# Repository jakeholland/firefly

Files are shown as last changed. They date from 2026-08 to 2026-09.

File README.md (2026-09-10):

# Firefly

**An open-source festival compass that points at your friends.**

Firefly is a palm-sized round-screen puck for music festivals: a compass arrow that points at your crew over LoRa mesh radio, off-grid messaging (canned replies, flares, T9), the full lineup with set alarms, and a vector map of the grounds — so your phone stays at camp.

<p align="center">
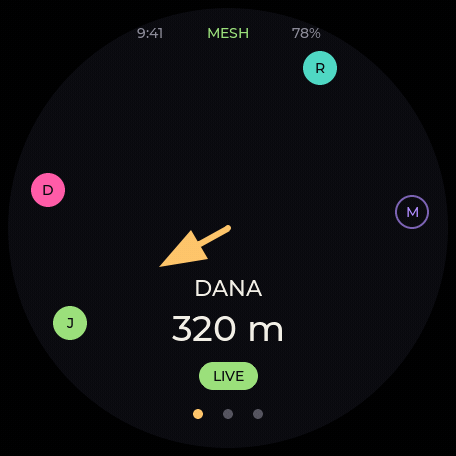
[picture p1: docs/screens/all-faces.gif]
Firefly cycling through the four built faces: the radar arrow locking onto a crew member, the Lost Lands lineup with set times still unpublished, the live schedule, the signals feed, the T9 composer, and a flare takeover.
  
</p>

<p align="center"><em>Not a mockup — that's the firmware rendering, frame by frame.<br>
All six v1 faces, running. The arrow finds your friend, the lineup admits which set times<br>aren't published yet, you can message without a network, and a flare takes over when someone needs finding.</em></p>

## Status

**The app runs.** As of 2026-09-02 all six v1 faces are built and merged: Radar, Lineup, Inbox (with its composer), Flare, Map, and Settings. The shell (S16) routes between them, and on top of it sits a device lifecycle (S25/S26): a launcher-is-home nav model, where a compass-ring launcher — Radar as the hub, the other faces as satellites — is what the puck boots into and rests on, with a physical button as the one "home" gesture from anywhere. Display, touch, the battery power latch, idle/sleep, and notification banners are hardware-verified on a real ESP32-S3 board, not just the desktop simulator. What's left before Lost Lands: the UART link to the comms brain (blocked on Seeed board availability), onboard sensors, and the enclosure. First field test: **Lost Lands, Sep 18–20 2026**.

<p align="center">
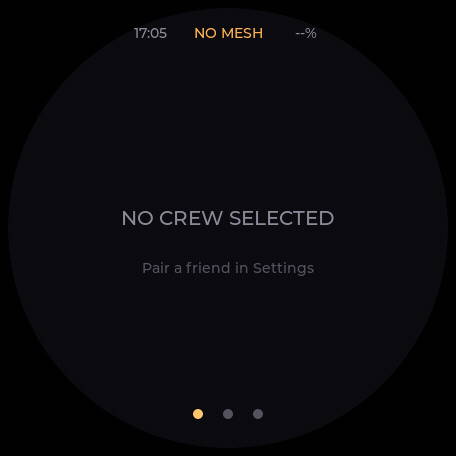
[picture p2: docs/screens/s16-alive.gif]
A live driven session: swiping from the radar's honest empty state through the Lost Lands lineup to Signals, typing omw on the T9 keypad, a flare takeover interrupting mid-draft with a live countdown, and the composer returning with the draft intact after DISMISS.
  
</p>

<p align="center"><em>Not fixtures — a live session, driven by real taps and swipes through the control socket.<br>Typed mid-draft, a flare takes the screen; dismiss it, and the draft is still there.</em></p>

This table is meant to be accurate rather than flattering — if something renders but can't run on hardware yet, it says so.

| Piece | State |
|---|---|
| Core logic — geo/bearing math, crew model & freshness, schedule engine, settings, T9, flare state machine | ✅ on `main` |
| Meshtastic client library (`meshclient`) | ✅ on `main` |
| festpack parser + the [Lost Lands 2026 pack](https://github.com/jakeholland/fest-almanac) | ✅ on `main` |
| **Radar face** — live / stale / lost / no-fix / no-selection | ✅ on `main` |
| Radar **close-range** mode — signal-strength rings under ~30 m | ✅ triggerable live with direct-path packets ([#35](https://github.com/jakeholland/firefly/issues/35)) |
| **Lineup face** (was Now) — live set times, starred-set countdown, and honest "times not published yet" states | ✅ on `main` |
| **Flare** — takeover screen, sender state, navigation lock | ✅ on `main` |
| Dev harness — control socket, dockerised Meshtastic node, end-to-end tests | ✅ on `main` |
| **Inbox face** (was Signals) — targeted crew messages and threads, rally points, OMW/5 MIN quick replies, and a T9 composer with ABC/123/SYM pages | ✅ on `main` (S22, S24) |
| **Map face** — vector grounds, crew dots, YOU arrow, priority-decluttered labels | ✅ on `main` (S09) |
| **Settings face** — units, clock format, quiet hours, share mode, screen flip, name | ✅ on `main` (S11, S21 — scrolling list + on-device Calibrate Touch; renaming is display-only, see below) |
| **App shell** — event loop, face routing, input dispatch, wall clock, link state, settings persistence | ✅ complete (S16, 9 slices) |
| **Launcher / home** — launcher-is-home nav model, compass-ring launcher (Radar hub + satellite faces), BOOT-button home, boot splash | ✅ on `main` (S26) |
| ESP32-S3 device target — display/touch, battery power latch, idle/sleep, notifications | ◐ hardware-verified on board (S15/S15b/c/d, S25, S26); UART link to the comms brain still blocked (Seeed board availability), sensors pending |
| Enclosure (`case/`) | ⏳ not started |

Every merged line went through an independent code review plus, for anything on screen, a review in the persona of a tired raver at 2 a.m. ([why](docs/review/ux-raver.md)).

### On `main` today

| Live | Lost | Close range |
|---|---|---|
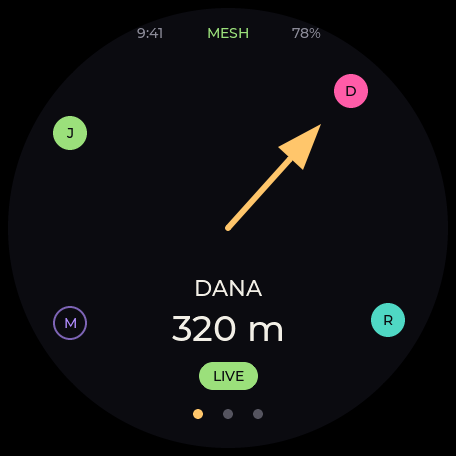
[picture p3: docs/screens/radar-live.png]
Radar face with a solid amber arrow, DANA, 320 m, and a green LIVE chip
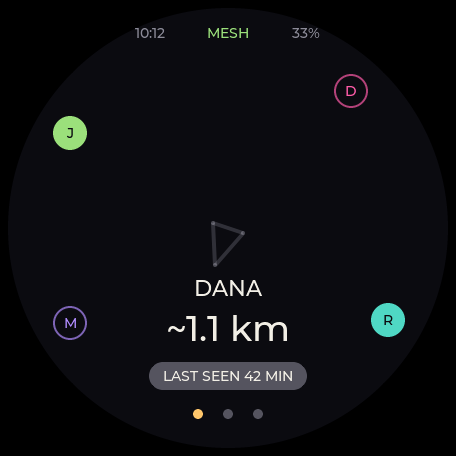
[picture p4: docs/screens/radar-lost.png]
Radar face showing a faint outline arrow, ~1.1 km, and a grey LAST SEEN 42 MIN chip
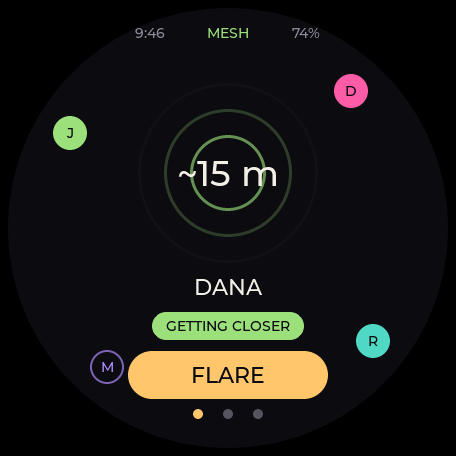
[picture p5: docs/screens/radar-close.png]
Radar face at close range with pulsing rings, ~15 m, and a FLARE button
|  |  |  |
| A fresh fix. Solid arrow, exact distance. | The fix is old. Different in *kind*, not just dimmer — the screen stops claiming to know. | Under 30 m, GPS is useless in a crowd. Rings and a hot/cold trend take over. **Triggerable live with direct-path packets** — see below. |

The middle one is the point of the whole project: most trackers keep pointing confidently at data they no longer have.

> **On close-range mode, honestly.** It renders, it has tests and golden screenshots, and it is now wired end to end: a DIRECT-path packet from a paired peer feeds `ff_crew_on_rssi()`, and `ff_radar_compute()` turns that into `mode: close` — two Heltec V3s standing next to each other can produce exactly that. What's still unproven is how OFTEN it fires on a real mesh: hardware findings on [#35](https://github.com/jakeholland/firefly/issues/35) show `hop_start: 0` is common, which makes DIRECT often unprovable, and that fraction hasn't been measured on live radio traffic yet — the ctl `state` dump now exposes per-member `rssi_dbm`/age (same bench-visibility pattern as `wall`/`link`) so it can be, next time boards are driven. "Triggerable live" is not "proven to trigger often enough" — a screenshot proves a thing draws, not how often it will.

| Set times, honestly | A flare arriving |
|---|---|
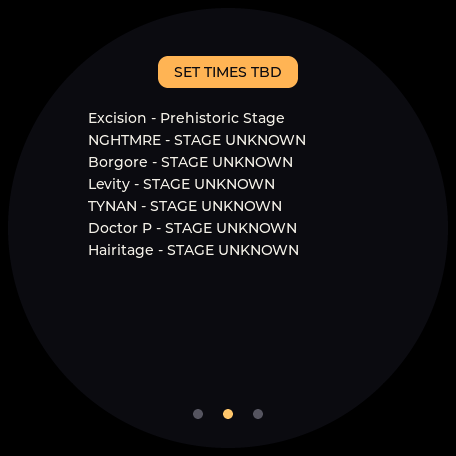
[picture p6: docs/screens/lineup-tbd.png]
Lineup face listing Friday's Lost Lands lineup under a SET TIMES TBD banner
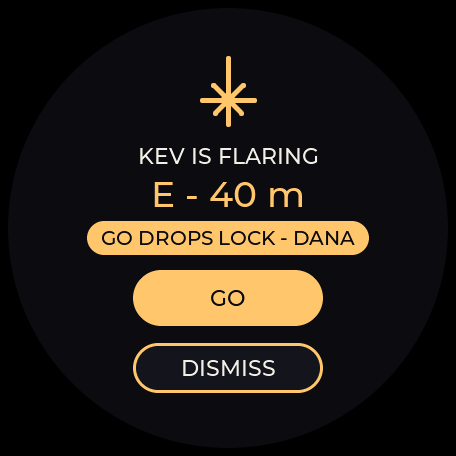
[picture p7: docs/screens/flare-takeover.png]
Full-screen takeover reading KEV IS FLARING, E - 40 m, above an amber chip reading GO DROPS LOCK - DANA — the disclosure that pressing GO costs you the navigation lock you already have
|  |  |
| Before a festival's set times are out, the puck says so and lists the day instead of inventing a schedule (screenshot predates publication — [Lost Lands' real 2026 set times landed on 2026-09-09](firmware/assets/field/README.md) and are embedded in the field pack now). | Press and hold, and your crew's pucks light up and point at you. If you were already navigating to someone else, it tells you what GO will cost you. |

| Inbox | Typing, off-grid |
|---|---|
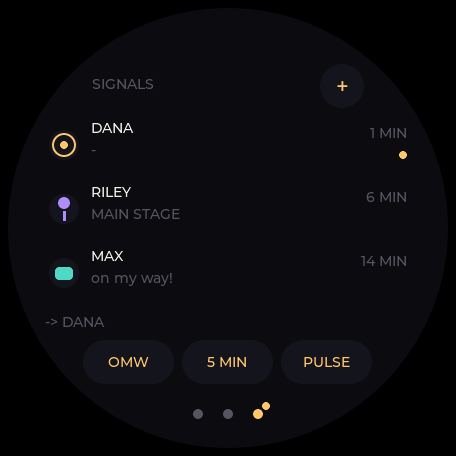
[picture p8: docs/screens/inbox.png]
Inbox face listing a pulse from Dana, a rally point, and a message, above OMW / 5 MIN / PULSE reply chips
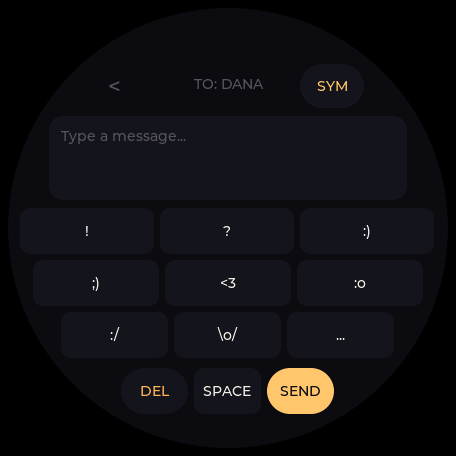
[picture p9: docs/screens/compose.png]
T9 composer showing the SYM page of symbols and emoticons
|  |  |
| Pulses, rally points, and one-tap replies — most festival coordination is four words or fewer. | A T9 keypad, because a QWERTY at 37 mm is a joke. ABC, 123, and a symbols page. |

## How it works

Firefly is a **dual-brain** device:

- **Comms brain** — a Seeed XIAO ESP32S3 + Wio-SX1262 stack running **stock, unmodified [Meshtastic](https://meshtastic.org)** with an L76K GPS. It owns the mesh, encryption, and positions, and gets free interop with every Meshtastic node on site.
- **UI brain** — a Waveshare ESP32-S3-Touch-LCD-1.46 (412×412 round touchscreen, IMU, mic) running the Firefly app on LVGL. It will talk to the comms brain over UART using Meshtastic's documented client API — the same protocol the official phone apps speak. *The app runs on real UI-brain hardware today (display, touch, power, lifecycle) speaking that API over TCP to a `meshtasticd` on your desktop; the UART link to the comms brain is still blocked on comms-brain board availability.*

No fork to maintain, no phone required, ~$80 in parts. Battery life is a design target, not a measurement — the puck has run on its own battery on the bench (S25), but not through a full festival day yet.

## Feature set (v1)

| Face | What it does |
|---|---|
| **Radar** | Big honest arrow + distance to a crew member; whole-crew dots; live/stale states. Close-range rings are triggerable live via direct-path packets from a paired peer ([#35](https://github.com/jakeholland/firefly/issues/35)) |
| **Lineup** | Set times per stage, set progress, starred-set alarms |
| **Inbox** | Targeted crew messages and threads, rally points, OMW/5 MIN quick replies, T9 composer |
| **Flare** | Press-and-hold "come find me" — crew pucks buzz and lock their arrows on you |
| **Map** | Vector grounds from a festpack — real Legend Valley geometry — with crew dots, rally pin, and a YOU arrow; labels declutter by priority so stages never overprint |
| **Settings** | Units, clock format, quiet hours, share mode, screen flip, on-device touch calibration — reached from the launcher, or long-press anywhere. Your name is shown but not yet editable: renaming needs its own T9 draft seam (the shell's only typed-input state today is the composer's), tracked as a follow-up rather than force-fit onto it |

Festival data (map polygons + lineup + set times) loads as a **festpack** — see [fest-almanac](https://github.com/jakeholland/fest-almanac), the open per-festival data repo.

## Try it without hardware

The whole app runs on macOS/Linux against a simulated round display:

```bash
cmake -S firmware -B build -DFF_TARGET=sim && cmake --build build -j8
ctest --test-dir build --output-on-failure     # the full suite
cd firmware && ../build/ffsim --fixture tests/fixtures/radar_live.json
```

Swap the fixture for any state in `firmware/tests/fixtures/` to see it rendered. Every screenshot in this README came out of that same binary — [`firmware/tools/social/render_scene.py`](firmware/tools/social/render_scene.py) is what turns a sequence of them into the animation above.

## Repo layout

```
firmware/   UI-brain application (LVGL, Meshtastic client API)
docs/       Architecture, specs, reviews, hardware notes
```

Planned, not yet present: `case/` (3D-printable ~82mm puck) and `web/` (browser
flasher + setup tools). Listing them as though they existed is the same
overclaim this README is trying not to make.

## Prior art & thanks

Standing on the shoulders of [Meshtastic](https://meshtastic.org), the [Friend Finder Edition](https://github.com/LeapYeet/Meshtastic-Firmware-Friend-Finder-Edition) fork, [iBurn](https://github.com/iBurnApp/iBurn-Data), and the badge scene (EMF Tildagon, badge.team). The consumer product that proved this market — Lynq — sold 20k units and then left for defense contracts. This one can't be taken away.

## History

This repo previously held a Meshtastic iOS/macOS client app — preserved at the [`archive/meshtastic-ios-app`](../../tree/archive/meshtastic-ios-app) branch and the `v0-ios-app` tag. Its BLE + protobuf client code remains a useful reference for the UI brain.

## License

**GPL-3.0-only** — see [LICENSE](LICENSE) and [docs/LICENSING.md](docs/LICENSING.md) for the reasoning (short version: the vendored Meshtastic protobuf derivations make GPL the honest choice, the ecosystem matches, and it's the license under which this project can't be taken away). Selling kits/assembled pucks under GPL is fine and encouraged — but the **Firefly name and flare mark are trademarks**: see [TRADEMARKS.md](TRADEMARKS.md) before selling anything under the name.

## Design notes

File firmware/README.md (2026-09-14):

UI-brain firmware (LVGL + Meshtastic client API). Starts when boards arrive — develop against the LVGL SDL simulator + meshtasticd.

## Layout

```
firmware/
  core/         firefly-core: pure C11 domain logic (no I/O, no LVGL)
  meshclient/   Meshtastic client library (skeleton — S03)
  festpack/     festpack.json parser (skeleton — S05)
  app/          ff_app_state.h (S13b) + LVGL screens (S06+)
                ff_route.h (S16a routing), ff_shell.h (S16b1 — the running app:
                lifecycle, mc_events_t callbacks, core->view projection)
  targets/sim/  ffsim — desktop sim target (S13); fixture.h/fixture_view.h (S13b);
                ctl_server.h/.c (S13c control socket); --connect/--pack drive the
                app shell (S16b2 — the interim live.h/.c wiring is retired)
  targets/esp32s3/  ESP-IDF project, real ESP32-S3 hardware (S15). Slice a
                (this one): the project skeleton — components/ wrap
                core/festpack/meshclient/app UNCHANGED, main/app_main.c
                boots the shell against stub HALs, no peripherals touched.
                See "Build — ESP32-S3 (device)" below.
  tools/        compare_png — golden-screenshot pixel diff (S14 slice b)
                dev/         compose.yml + crew_sim.py + CTL.md — the live dev loop (S13d)
  tests/        tests/fixtures/*.json, tests/golden/*.png, run_goldens.sh (S13/S14 slice b)
                e2e/         pytest e2e scenarios against dockerized meshtasticd (S14d)
  third_party/  vendored single-header libs (stb_image_write.h, stb_image.h)
  lv_conf.h     LVGL configuration for the sim build
```

Third-party dependencies (LVGL, Unity) are pulled via CMake FetchContent and
pinned to commit hashes in `firmware/CMakeLists.txt` — never floating tags.
SDL2 is a system dependency, found via `find_package(SDL2)`.

## Build — macOS

```sh
brew install sdl2 cmake
cmake -B build -DFF_TARGET=sim
cmake --build build
ctest --test-dir build --output-on-failure
```

## Build — Ubuntu / Debian

```sh
sudo apt-get update
sudo apt-get install -y libsdl2-dev cmake build-essential
cmake -B build -DFF_TARGET=sim
cmake --build build
ctest --test-dir build --output-on-failure
```

## Build — ESP32-S3 (device, S15 slice a)

```sh
source ~/esp/esp-idf/export.sh   # or: . ~/esp/esp-idf/export.sh
# first time only, if the xtensa toolchain isn't installed yet:
#   ~/esp/esp-idf/install.sh esp32s3
cd firmware/targets/esp32s3
idf.py set-target esp32s3   # only needed once, or after deleting build/
idf.py build
idf.py -p <PORT> flash monitor   # once the board is on the bench
```

This is a SEPARATE build entry point from the `cmake -S firmware ...`
sim build above — `idf.py`, not `cmake --build`. It does not
`add_subdirectory()` the sim tree; every component under
`targets/esp32s3/components/` points its `SRCS`/`INCLUDE_DIRS` straight
at the existing `firmware/{core,festpack,meshclient,app}` sources, so
those compile for xtensa UNCHANGED — literally the same `.c` files the
sim target builds. `main/app_main.c` boots `ff_shell_t` against stub
HALs (`esp_timer`-backed clock, a no-op store, no transport) and never
touches a peripheral — the display/touch/UART/sensor drivers are slices
b/c/d. See `docs/specs/S15-esp32s3-target.md` and the S15a PR body for
the full slice breakdown and every host-portability finding this port
surfaced.

## Run the sim

```sh
./build/ffsim                                 # SDL window, 456x456
./build/ffsim --headless --screenshot out/     # renders one frame -> out/boot.png, exits 0

# S13b: load an ff_app_state_t fixture (schema: tests/fixtures/README.md)
# and render the placeholder debug face instead of the boot screen.
./build/ffsim --headless --screenshot out/ --fixture tests/fixtures/radar_live.json --mock-clock
./build/ffsim --fixture tests/fixtures/radar_live.json   # same, in an interactive SDL window
```

Headless mode never touches SDL or a display server — it renders straight
into an LVGL software framebuffer and writes it out with stb_image_write.
This is the path CI uses to produce the boot screenshot artifact.
`--mock-clock` freezes the LVGL tick source (always meaningful in window
mode; a no-op-but-honored belt-and-suspenders in headless mode, which is
already deterministic on its own — see `targets/sim/main.c`'s header
comment).

### Live mode + the control socket (S13 slice c/d)

```sh
./build/ffsim --headless --ctl 9000 \
    --connect 127.0.0.1:4403 \
    --pack festpack/tests/fixtures/lost-lands-2026.festpack.json
```

Opens a newline-JSON control socket on `127.0.0.1:9000` (protocol:
`tools/dev/CTL.md`) instead of rendering once and exiting — `tap`/
`swipe`/`clock`/`state`/`screenshot`/`quit` commands, one JSON object per
line in, one JSON line back. `--connect HOST:PORT` wires up a live
Meshtastic connection driving the app shell (`app/include/ff_shell.h`,
S16b2) so `{"cmd":"state"}` dumps reflect `ff_shell_view()` — real mesh
traffic filtered by the roster trust policy — instead of a static
fixture; add `--dev-trust-all` (sim-only, compiled out on device) to
auto-pair the dev daemon's NodeInfo senders, see `tools/dev/CTL.md`;
`--pack FILE` anchors "my position" at a festpack's venue origin (the
sim has no real GPS); `--ctl-out DIR` sets where the `screenshot` command may write
(`path` in that command is a relative name confined under this root —
never an arbitrary filesystem path — see CTL.md). See `tools/dev/
README.md` for the whole dev loop (dockerized meshtasticd + `crew_sim.py`
scenario driver) and its documented, verified-against-the-real-container
limitations.

## Golden screenshots

```sh
tests/run_goldens.sh                 # render every tests/fixtures/*.json,
                                      # diff against tests/golden/*.png (<=0.5%)
tests/run_goldens.sh --update-golden # regenerate the committed goldens
```

Also proves determinism: every fixture is rendered twice per run and the
two PNGs must be byte-identical before the golden comparison even runs.
On a golden mismatch, a side-by-side `[golden | rendered | diff]` PNG is
written to `tests/golden/_diff_out/` (gitignored scratch output; CI
uploads it as an artifact on failure — see `.github/workflows/ci.yml`).
Schema and the currently-committed fixtures are documented in
`tests/fixtures/README.md`.

## Tests

Unit tests use Unity and run via ctest, one test executable per module
(`test_core`, `test_settings`, `test_store_file`, ...). Test names are
criteria-numbered per spec (`SNN_ACX_description`), per `AGENTS.md`.

- `test_settings` (S11 slice a) — `core/ff_settings.h`/`ff_store.h`:
  load-with-defaults, save/load round trip, `ff_quiet_now` wraparound,
  water-nudge tick, write-amplification, all against an in-memory mock
  store.
- `test_store_file` — `targets/sim/store_file.h`, the sim's trivial
  file-backed `ff_store_t` (single key-value file), plus an end-to-end
  `ff_settings_t` round trip through the real file store.
- `test_fixture` (S13b/c) — `targets/sim/fixture.h`'s JSON loader/dumper:
  the three committed radar fixtures parse to their exact documented
  values, IO/JSON error paths, missing-section defaults,
  `ff_fixture_stem`, and (S13c) `ff_fixture_dump_json`'s dump-then-reload
  round trip, including JSON-escaped strings and a maximally-populated
  state.
- `test_ctl_server` (S13c) — `targets/sim/ctl_server.h`'s line framing
  (exact `FF_CTL_MAX_LINE` boundary, oversized-line resync) and command
  dispatch (every command's success path and guard paths), plus a real
  loopback-socket end-to-end pass.
- `test_crewcode` / `test_hidden` / `test_admit` (A02 slice D) — the
  crew code and the key it derives, the per-node hide set, and the
  admission rule. `test_crewcode` reads its vectors at runtime from
  `docs/specs/fixtures/A02-crew-codes.json`, the SAME file the app's
  Swift `CrewCodeTests` reads, so the two implementations cannot drift
  apart without one of them going red. `test_admit` has exactly one
  "everything passes" fixture and mutates one field per test, and
  asserts the REASON rather than a bool — a rule that rejects the MQTT
  case for the wrong reason passes a bool-only test and ships the bug.
- `test_shell` (S16 slice b1) — `app/ff_shell.h`, the running
  application: the roster trust policy across all seven `mc_events_t`
  callbacks (unknown senders reach `ff_heard`, never the paired roster;
  since A02 slice D a sender that proves possession of the crew channel's
  key is admitted, through the same single audited `shell_pair` path),
  position ages that come from `rx_time`/`last_heard` and never from the
  local clock (the reconnect-replay defect), haptic-vs-quiet-hours
  composition, and the dirty bit computed over the *rendered* projection.
  No transport or handshake anywhere: events are injected through
  `ff_shell_events()`, the same mock-injector seam `ff_wiring.h`
  documents. Two of its criteria are easy to pass for the wrong reason,
  so both carry an explicit measurement — see the file's header comment.
  S16 slice b2 added the AC6 cutover tests: one drives the shell's own
  `mc_client_t` through a scripted in-memory transport with hand-encoded
  protobuf frames (the retired `test_live`'s technique, now proving the
  exact pipeline `ffsim --connect` ships), plus the `--dev-trust-all`
  dev-affordance semantics and the on_my_info heard-purge.
- `test_png_diff` (S14 slice b) — `tools/png_diff.h`'s pixel-diff core,
  including the exact 0.4%/0.5%/0.6% threshold boundary.
- `test_wall` (S16 slice b0; trust gate S18 slice a) — `core/ff_wall.h`'s
  wall-clock derivation: the `FF_WALL_UNKNOWN` honesty discipline, the
  plausibility window's four boundaries, offset-latch/re-latch, UTC-offset
  resolution order, and the `unix -> local -> (day_doy, now_min)`
  festival-day mapping. Also `ff_wall_observe`'s trust tier (issue #49):
  a BOOTSTRAP-tier disagreement can never move an established latch (the
  second-stranger scenario), only TRUSTED can, and the pre-existing
  expired-latch/backwards-monotonic branch stays deliberately trust-blind.
  S18 slice c (#40) adds the pack-derived plausibility window: the effective
  gate window defaults to the fixed bootstrap bounds and tightens to a
  loaded pack's dates via `ff_wall_set_window`; `ff_wall_unix_from_doy` is
  the exposed civil-date primitive the derivation shares; and
  `ff_wall_ceiling_deadline_near` is the build-date proximity guard
  (synthetic-date tested, never the real clock). The festpack->window
  derivation itself (`ff_wall_window_from_pack`, honest fallback for a
  null-dated pack) is `test_wall_window` (app), and the shell wiring
  (load_pack tightens the window; a Sep 2029 stamp inside the fixed window
  is rejected once Lost Lands loads) is in `test_shell`.
  The date math additionally has an out-of-band cross-check against
  Python's `datetime` — `tools/dev/wall_crosscheck.py`, not a ctest (it
  needs a compiler and Python at once); run it after touching the
  civil-date code.

## Release checklist

Things that must be done at a release and cannot be enforced by a test,
because enforcing them in code would make a build's behaviour depend on
the day it was built.

- **Bump `FF_WALL_EPOCH_FLOOR`** (`core/include/ff_wall.h`) to the
  release date. It is the wall clock's lower plausibility bound, and it
  is a *decaying* guard: an uncorrected RTC's reported time drifts
  forward with the calendar while a hardcoded constant does not, so every
  year it is not bumped it catches less — silently, with no test failure
  and no warning. `FF_WALL_EPOCH_CEILING` is derived from it and moves
  along automatically. Forward only; never move either bound backwards.
  (Recorded here per PR #37 review, D3.)
  - S18 slice c (#40) narrowed *when* this matters and added a backstop.
    Once a pack loads, the plausibility window tightens to the festival's
    own dates (`ff_wall_window_from_pack` -> `ff_wall_set_window`), so the
    fixed window's decay only affects the **no-pack bootstrap** path (the
    want_config handshake). And that decay is no longer fully silent:
    `ffsim` prints a loud, dated warning at startup once the **build date**
    is within 12 months of the ceiling (`ff_wall_ceiling_deadline_near`,
    surfaced by CI's headless-screenshot step). It is still a *warning*,
    not a pass/fail — a build's verdict must not depend on the day it ran
    — so this bump remains a human release step, now with a year of
    tracked runway instead of nothing.

## e2e tests (S14 slice d)

`tests/e2e/` (pytest): docker compose up meshtasticd -> `ffsim --headless
--ctl PORT --connect ...` -> drive scenarios with `tools/dev/crew_sim.py`
-> assert via the ctl socket's state dump. Nightly + `workflow_dispatch`
only (`.github/workflows/e2e.yml`) — not a PR gate, docker's too slow.
See `tests/e2e/test_scenarios.py`'s module docstring for exactly what's
verified working end to end and what's a documented, evidence-based
limitation of testing against a single stock (no-hardware) meshtasticd
instance.

```sh
pip install -r tests/e2e/requirements.txt
cd tests/e2e && pytest -v   # conftest.py brings meshtasticd up/down itself
```

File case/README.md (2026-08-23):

3D-printable enclosure. ~82mm dia x ~28mm; see docs for verified component dimensions.

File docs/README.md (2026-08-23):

Architecture, power budget, enclosure spec, build guide.

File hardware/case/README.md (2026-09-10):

# Firefly case generator

A scripted, parametric Fusion 360 generator for the Firefly festival-puck
case ("case as code"), replacing the earlier 165-feature direct-modeling
file. See `SPEC.md` for the full original brief this was built against.

## How to run

Everything lives in plain files on disk; Fusion just executes them. Inside
Fusion's Scripts/API panel (or via the `fusion_mcp_execute` MCP tool),
run:

```python
import runpy

def run(_context: str):
    g = runpy.run_path('/path/to/hardware/case/firefly_case.py')
    g['run'](_context)                              # builds PARAMS['variant']
    # g['run'](_context, variant='current')          # or force a variant
    # g['run'](_context, variant='trim', export=True) # + STL/screenshots
```

Each call creates a **new** Fusion document named `Firefly Case Gen
<timestamp>` and leaves it open, unsaved. It never touches or saves any of
Jake's existing documents ("Firefly V2 ...", "KandiWooks Logo", or any of
the board models) — those are only opened for reading (reference
transforms, the display module's placement, the comms board geometry).

`run()` builds the case, runs `verify()` (raises `AssertionError` with a
clear message if anything is off), prints a summary (timeline count, body
names + bounding boxes, every probe result, interference results), and —
with `export=True` — writes STLs and takes 4 orthographic screenshots.

### Picking a variant

`firefly_case.VARIANT` (module level, currently `'trim'`) picks the
default; `run(_context, variant='current'|'trim')` overrides it per call.
`PARAMS`, `PARAMS_CURRENT`, `PARAMS_TRIM` are all available in the returned
globals dict `g` if you want to inspect a variant's numbers without
building it.

### Files

| File | Purpose |
|---|---|
| `firefly_case.py` | The generator: geometry, `build()`, `verify()`, `run()`. |
| `params_current.py` | 60×110×25 variant — matches the "Firefly V2 v15/v16" reference. All SPEC.md numbers live here. |
| `params_trim.py` | 56×103.8×28 variant (**default**, Jake's 2026-09-04 decision; envelope updated 2026-09-06/07 pass 7 height, 2026-09-13 pass 12b length) — derived from `params_current.py` with documented overrides, not hand-duplicated. |
| `kandiwooks_logo.json` | KandiWooks wordmark outline loops (mm), extracted from the "KandiWooks Logo" document's 6 bodies. |
| `SPEC.md` | The original task brief, verbatim (plus one 2026-09-13 editorial note flagging the envelope numbers it was written against). |
| `tools/pass12b_ext_calc.py` | Standalone, no-Fusion-needed script (2026-09-13) deriving the minimum `usb_end_extension_mm` — reuses `rho_at_z`/`rho_from_spine` verbatim. |
| `export/<variant>/*.stl` | Per-body STL exports (binary): `Bottom`, `Top`, `Screen_Plate`, `Power_Button`, `Home_Button`. |
| `export/<variant>/firefly_<variant>_case.3mf` | Native 3MF (2026-09-06, pass 6) containing exactly the 5 printed bodies (`Print — Case` + `Print — Buttons`), for viewers/slicers that read 3MF's per-object structure directly instead of separate STLs. |
| `export/coupons/coupon_{power,home}_{wall,cap}.stl` | Standalone button fit-test coupons (see Print orientation & settings below). |
| `export/coupons/firefly_coupons_native.3mf` | Native 3MF (pass 6) with the 4 coupon bodies. |
| `export/<variant>/firefly_<variant>_plate.3mf` | Packed, print-oriented plate (pass 9 pt 2) — all 5 printed bodies laid out via `tools/stl_to_3mf.py` (Bottom as-is, Top flipped 180° about X, buttons rotated outer-face-down). |
| `renders/<variant>_{front,top,right,iso}.png` | Orthographic screenshots. |
| `renders/{power,home}_button_ext.png`, `lanyard_end.png`, `bottom_logo.png`, `plate_underside.png`, `bay_inside.png`, `rim_{lanyard_end,usb_end}.png` | Pass-6 close-up renders, TRIM variant, showing the fixes in this pass. |
| `renders/pass9c_{trim,current}_{front,top,right,iso}.png` | Pass-9 part-2 orthographic screenshots, both variants (findings 4/5/6). |
| `renders/pass9c_{posts_closeup,lip_ring_section,lip_chamfer,plate_underside}.png` | Pass-9 part-2 close-ups: the relocated Ø5 posts/header area, the ring near the window, the ring's seam chamfer (wide underside view), and the Screen Plate's new south extension. |
| `renders/pass10b_{trim,current}_{front,top,right,iso}.png` | Pass-10 REDO orthographic screenshots, both variants — the clean pill silhouette after removing the rejected brow. |
| `renders/pass10b_mag_pocket.png` | Pass-10 REDO close-up (trim only): looking up into Top's ceiling from inside the cavity, showing the compass module's retaining fence, rest pads, and ceiling pegs above the GPS patch. |
| `renders/pass11_{trim,current}_{front,top,right,iso}.png` | Pass-11 orthographic screenshots, both variants — window bore fix + (trim) re-oriented compass mount, clean silhouette. |
| `renders/pass11_{window_closeup,brow}.png` | Pass-11 close-ups (trim): the window bore reading as a clean open circle, with the FPC brow's tiered risers visible outside it, not filling it. |
| `renders/pass11_mag_pocket.png` | Pass-11 close-up (trim only): looking up into Top's ceiling from inside the cavity, showing the re-oriented/repositioned compass mount (fence, pegs, pads, south-wall wire notch) clear of the nearby case-screw bosses. |
| `renders/pass12_{trim,current}_{front,top,right,iso}.png` | Pass-12 orthographic screenshots, both variants, at `top_z=30` (since reverted — see pass 12b). |
| `renders/pass12_usb_end_top.png`, `pass12_power_button_straight.png`, `pass12_home_button_straight2.png` | Pass-12 close-ups (trim, `top_z=30`): the USB end and both button holes. |
| `renders/pass12b_trim_{front,top,right,iso}.png` | Pass-12b orthographic screenshots (trim, current numbers: `top_z=28`, `usb_end_extension_mm=1.8`) — clean pill silhouette, longer at the USB end, no bumps. |
| `renders/pass12b_usb_end.png` | Pass-12b close-up (trim): the window/USB end with the FPC brow deleted — a smooth, unbroken shoulder curve into the dome tip, no step/notch/plateau. |
| `renders/pass12b_power_button.png`, `pass12b_home_button.png` | Pass-12b close-ups (trim): zoomed, straight-on (fixed `viewExtents`, not `isFitView`) views of each button hole on the -x wall — a single clean stadium opening each, no secondary notch. |
| `renders/pass14_{trim,current}_{front,top,right,iso}.png` | Pass-14 orthographic screenshots, both variants — lanyard-end corner blocks + wordmark counter fix, clean silhouette (unchanged from pass 12b). |
| `renders/pass14_top_corner_blocks.png` | Pass-14 close-up (trim): looking straight into the Top's lanyard end from below/inside — both merged corner blocks visible as one continuous mass around their own pilot pair. |
| `renders/pass14_top_inside.png` | Pass-14 close-up (trim): wider isometric-from-inside view, corner blocks alongside the compass mount, window bore, and USB tunnel. |
| `renders/pass14_bottom_logo.png` | Pass-14 close-up (trim): straight-on wordmark render — all 4 counters ('a', 'd', both flower 'o's) visibly open, not solid. |

Every exported body (case and coupon) is size-checked at export time
(`assert_export_body_size`, ≤120mm/≤40mm max extent respectively) as a
guard against a units/scale bug — see Verification below.

## Parameter table (key numbers)

All dimensions mm. Full detail in `params_current.py`/`params_trim.py` —
this is the headline subset.

| | current | trim |
|---|---|---|
| Outer envelope | 60 × 110 × 25 | ~~56 × 102 × 25~~ 56 × 103.8 × 28 *(pass 7 height 25→28; pass 12b length 102→103.8, `usb_end_extension_mm`)* |
| Outer radius | 30.0 | 28.0 |
| Spine (OUTER envelope only) | (0,0)–(0,50) | ~~(0,0)–(0,50)~~ (0,0)–(0,51.8) *(pass 12b: `usb_end_extension_mm`=1.8 grows the +y dome end only — every absolute-mm feature (window, FPC relief, buttons, posts, screw_D) stays anchored to y=50, see the pass-12b README section)* |
| `usb_end_extension_mm` | 0.0 | 1.8 *(pass 12b — exact minimum for ≥1.5mm FPC-relief skin was 1.522mm/1.456mm, both < the 3.0mm asked about; see pass-12b section)* |
| Case height (`top_z`) | 25.0 *(frozen, pass 7)* | ~~30.0~~ 28.0 *(pass 12b: reverted pass 12's height bump — proven not to help the FPC pocket; see pass-12 and pass-12b sections)* |
| Wall | 2.0 | 2.0 |
| Shoulder flat radius | 24.14 | 22.14 |
| Shoulder tangent point ρ | 27.07 | 25.07 |
| Outer fillet R | 10.0 | 10.0 |
| Inner fillet R (derived) | 8.0 | 8.0 |
| Lip ring R | ~~26.95–27.75~~ 25.95–27.75 *(pass 9 pt 2)* | ~~24.95–25.75~~ 23.95–25.75 *(pass 9 pt 2)* |
| Anchor ring R | ~~26.95–28.40~~ 25.95–28.40 *(pass 9 pt 2)* | ~~24.95–26.40~~ 23.95–26.40 *(pass 9 pt 2)* |
| Top post Ø (P1–P4) | ~~4.0~~ 5.0 *(pass 9 pt 2)* | ~~4.0~~ 5.0 *(pass 9 pt 2)* |
| Window Ø | 45.30 | 45.30 (same, centred (0,50)) |
| Lanyard tip protrusion beyond wall | 8.5 | 8.5 |
| Comms bay cavity width | 56 (±28) | 52 (±26) = battery 30 + stack 17.8 + 3×1.4mm gaps |

Display module, screen plate posts/standoffs, USB tunnel, and button
switch positions are **unchanged** between variants (Jake: "keep ... at
their reference positions") — the shoulder/envelope, lip/anchor/lug/bay
numbers scale with `outer_radius`, and as of the 2026-09-05 pass-2 fix
**screws A/B/C also shift inward for trim** (their `current`-variant
positions punched through the narrower R28 shell): A/C move to
`x = ±(outer_radius - wall - 3.0)` (±23.0 for trim vs ±22.97/23.74 for
current), B to `(0, -(outer_radius - wall - 3.0))` (-23.0 vs -24.0); D
is unchanged at (0, 65.0) in both. See the Screw list section below for
the exact per-variant values.

## Verification

`verify()` runs after every `build()` and is what gates each milestone.

**M1 (shell)** — `verify_m1_probe_table` / `verify_m1_cavity_probes`:
probes the outer shoulder profile and the inner cavity wall at the exact
z-heights from SPEC.md's reference table, computing the *expected* ρ at
each height analytically (`rho_at_z()` / `inner_rho_at_z()`) from `PARAMS`
rather than hardcoding SPEC.md's current-variant numbers — so the same
check validates both variants (trim's numbers are the same profile shifted
−2mm in ρ). All probes pass within 0.15mm on both variants. Body names:
`['Bottom', 'Screen Plate', 'Top']` at end of M1 (buttons added in M2).

Important finding from building M1: the **inner cavity edge is a plain
single R8 fillet**, tangent directly from the flat ceiling/floor to the
vertical inner wall — **not** a true offset of the outer compound curve
(which still carries the 45° shoulder through to the inside). Verified
empirically: a true-offset construction gives 24.32mm at SPEC's
`(15,10,22.0) → 23.88mm` cavity probe; the plain-fillet construction gives
23.87mm. See `_inner_profile_geometry`'s docstring.

**M2 (buttons/USB/lug/logos)** — `verify_m2`: hole clearance (0.25mm/side),
plunger tip gap (0.02mm, now the gap AT FULL PRESS — see below), nub
pocket depth (0.8mm), and tab gap (0.60mm) are checked against `PARAMS`
(the cut geometry is a direct function of these numbers); USB tunnel and
lanyard lug hole are checked with real point-containment probes against
the built solids.

**Plunger guide rib + inward stop collar** (added 2026-09-04, from Jake's
print-test feedback — the caps bound, and a hard press had nothing but the
switch itself to stop inward travel, loading its solder joints): each
button now has a 1.6mm-thick rib bridging the plunger, joined to the Top's
inner wall/ceiling, `rib_inboard_offset` (5-7mm, default 6.0) inboard of
the outer wall, with a rectangular slot through it sized to the plunger's
cross-section + `rib_slot_clearance` (0.25mm) per side so the plunger
can't tilt or rotate. The plunger carries an oversized flange (a "collar",
`collar.h`=0.8mm taller than the plunger cross-section, `collar.len`
=1.0mm long) on its inboard side that cannot pass through the rib's slot;
at rest it sits `plunger_travel` (0.62mm) short of the rib, so a press
travels 0.62mm and bottoms the collar on the rib — 0.02mm before the
plunger tip would otherwise reach the switch housing (`plunger_tip_gap`,
now specifically the bottomed-out gap, not the rest gap). The rib takes
the finger force; the switch never does. `verify_m2` checks the at-rest
collar-to-rib gap (0.62±0.05mm) and that the slot clearance is 0.25mm by
construction, plus a real point-containment check that the cap body never
occupies the rib's material around the slot.

*(2026-09-08 pass 9b update: `plunger_tip_gap` is retired — it was a
full-press gap measured from `housing_xy`, an approximated point that
turned out to sit several mm from the real switch housing; replaced by
`plunger_pretravel` (0.3mm, a REST gap from the real, live-probed
actuator). `rib_inboard_offset`'s "5-7mm, default 6.0" is now the nominal
default only — `button_geometry` shifts it dynamically, per button, when
the real switch position doesn't leave room for the nominal value. See
the pass 9b section below for the full root cause/fix on both.)*

**Interference**: `check_interference` runs `design.analyzeInterference`
between all printed bodies, and separately between the case and any
inserted board occurrence (walking the full occurrence tree, since a
referenced assembly's bodies live on deeply nested child occurrences, not
the top-level one). It measures each reported interference's actual
overlap *volume* and ignores razor-thin (<1e-4 mm³) coincident-face
"touches" — e.g. the Top posts resting flush on the Screen Plate at
z=14.1 — which are by design, not a defect.

**This claim was false — pass 4's `check_interference` excluded
reference-only bodies, never asserted on `occ_interference` at all, and
used a `physicalProperties.volume` reading that (confirmed in pass 5)
reads back as 0.0 for every `analyzeInterference` result in this Fusion
build, so it was passing vacuously, not because the geometry was clean.**
Pass 5 rewrote the check (see below) and, as of its second round (the
XIAO orientation fix + GPS-frame/tray clip), **both variants now build
with zero real interference, zero real overhangs, and all M1/M2/
clearance checks passing under `run(..., export=True)`** — verified by
actually running it, not by trusting the assertion alone. See the
2026-09-05 pass 5 section below for the methodology and what was
actually wrong.

**Export size sanity check** — `assert_export_body_size` (2026-09-05):
every body written by `export_stls`/`export_coupons` is checked against
its live Fusion `boundingBox` right at export time (max extent ≤120mm for
a case body, ≤40mm for a coupon body) — a guard against a units/scale bug
(a cm value used as mm, a stray extra Move) slipping into a shipped STL
undetected. Added after a report of a 10x-oversized
`coupon_power_wall.stl`/`coupon_home_wall.stl` (96×240×186mm); the actual
cause turned out to be a units mismatch in the *reporting* tool, not the
export — both the live Fusion geometry right after `build_button_coupon()`
and the STL bytes on disk (independent struct-level parse) read correctly
at 9.6×24×17.8/18.6mm — but the assertion now stands as a permanent
regression guard either way.

## 2026-09-05 pass 2 (coordinator follow-ups)

Five follow-ups landed after the initial M1-M4 pass, all against the same
`case-generator` branch/worktree:

1. **Outer-shell bumps at the parting line, fixed.** Renders showed
   half-dome bumps where case-screw bosses A/B/C and Top posts P1-P4 (sized
   at their `current`-variant/R30 reference positions) punched through the
   narrower trim (R28) shell. Every boss/post is now intersected with a
   shared inner-cavity "clip tool" solid (`clip_to_inner_cavity` /
   `build_inner_cavity_clip_tool`) before being joined in, so it can never
   extend past the real cavity regardless of nominal position; screws A/B/C
   are additionally re-derived for trim (A/C at x=+-23.0, B at y=-23.0,
   per `outer_radius - wall - 3.0`). `verify_envelope` (bounding-box-within-
   allowed-envelope) and `verify_no_outer_bumps` (8-point probe scan just
   outside the outer surface) now gate every build and both pass clean.
   **Debugging note for future maintainers:** intersecting a `cylinder_solid`
   boss/post against this curved/filleted clip tool, then joining the
   result into Bottom/Top, was silently leaving the PRE-join body behind as
   an orphaned same-named duplicate ('Bottom (1)', 'Top (1)', ...) instead
   of updating in place -- root cause not identified beyond reproducing it
   down to that exact combination. `dedupe_body` cleans these up via a
   Remove feature after every boss/post join (not a Join-back, which itself
   raised an error on the fragile orphan), and `remove_stray_generic_bodies`
   sweeps any remaining auto-named ('BodyNN') orphans at the end of
   `build()` as a final safety net.
2. **Comms bay redesigned as a half-disc dome layout.** The lower cavity is
   a half-disc at the spine_a end (radius = outer_radius - wall) plus the
   straight band y 0..27 -- see `params_current.py`'s `bay` dict for the
   full absolute-mm layout (battery/L76K/stack/GPS positions, used
   unchanged for both variants -- trim's R=26 is the tighter constraint,
   current's R=28 just has 2mm more slack). The XIAO+Wio stack and the GPS
   patch are each held by a Top-hanging, open-bottom "tray"/"frame"
   (`build_hanging_frame`) so both Bottom and Top print face-down with no
   overhangs; the battery gets two rails + strap slots THROUGH the rails
   (not the bed face); L76K (now always wired, 'hat' mode dropped) sits in
   a shallow floor frame with a wire notch. Battery and GPS patch have no
   Fusion docs, so they're hidden reference-only boxes
   (`add_battery_reference_box` / `add_gps_reference_box`), excluded from
   exports, alongside the (also reference-only) FPC keep-out marker.
3. **Board placement fixed.** XIAO/Wio/L76K are now correctly positioned
   (previously they were inserted but left at their native/identity
   placement, hidden, as a known limitation): `insert_and_place` /
   `flatten_transform` read each board's native bounding box, rotate its
   thinnest native axis (XIAO's is Y) onto world Z, and translate its
   center into the bay -- Wio's PCB bottom at z=10.5, XIAO's at
   +6.1mm above that (plugged into Wio's sockets), L76K flat on the floor
   of its frame. `design.snapshots.add()` is called whenever
   `hasPendingSnapshot` is true after assigning `occ.transform`, per the
   coordinator's fix; verified by re-reading each occurrence's bRepBody
   bounding boxes afterward (`_bbox_extents`, which unions actual body
   boxes rather than trusting `occ.boundingBox`, still unreliable
   immediately post-insert in this session). Boards are visible (not
   hidden) in the generated document. **Rough edge from this pass, RESOLVED
   in pass 3 below:** the L76K assembly's own bounding box (including its
   antenna cable/lead) extended well past the small frame built for the
   bare board, and positioning by that aggregate box put the actual PCB
   outside the case entirely.
4. **Button caps + USB liner trimmed to the real curved shell.** Both were
   built against a flat-wall approximation (documented pass-1 limitation);
   now each is over-built with a few mm of extra margin and then
   Combine-Intersected against either a thickened copy of the outer
   envelope (caps: offset outward by `proud`=0.45mm via OffsetFaces,
   `build_thickened_envelope`, shared across both buttons) or the plain
   envelope (USB liner). `verify_m2` checks the cap's outermost point
   against an analytic `true_wall_distance_along_ray` (handles both the
   straight-section wall and the domed end caps, which are literal
   revolves of the same profile) at 3 heights per button, within 0.25mm --
   loosened from an initial 0.1mm target because the analytic formula
   assumes a purely-radial surface normal, which the R10 shoulder fillet's
   real normal (has a Z component too) doesn't quite satisfy; the built
   result was confirmed correct by probe either way, just not pinned to
   sub-0.1mm by that simplified formula.
5. **Button fit-test coupons added.** `build_button_coupon` /
   `export_coupons` build a standalone, straight-axis (no diagonal nub
   direction) wall+shelf+rib body and a separate cap body per button, from
   the SAME `PARAMS` (`cap_clearance`, `rib_thickness`,
   `rib_slot_clearance`, `plunger_travel`, `collar`, `nub_pocket`, `tab`)
   as the real button -- a fit found on the coupon transfers directly to
   the case. Exported (with `export=True`) as
   `hardware/case/export/coupons/coupon_{power,home}_{wall,cap}.stl` (wall
   and cap print separately, side by side -- not fused into one body).
   `PARAMS['cap_clearance']` (0.25mm default, the same value used for the
   real wall-hole-to-head clearance) is the knob to tune from a coupon fit
   test; a looser fit means a bigger number, a snugger fit a smaller one.

## 2026-09-05 pass 3 (visible-defect fixes the asserts missed)

Renders/STL analysis from pass 2 found real geometry the pass-2 checks
didn't catch:

1. **L76K board was outside the case.** Positioning by the whole
   occurrence's aggregate bbox put the actual PCB nowhere near its target
   -- the assembly's separate GPS patch antenna (25x25x8.3, on a cable)
   dominates that bbox. Fixed: `find_pcb_like_body` recursively searches
   the L76K assembly for a body shaped like a small PCB (two dims
   15-24mm, third <=3mm) and positions BY THAT BODY specifically; the
   antenna sub-occurrence is hidden. Verified: PCB world bbox now
   `x -10.48..10.48, y -23.39..-5.61, z 1.83..3.37` against a target of
   `x -10.5..10.5, y -23.5..-5.5, z ~2.0..3.2`.
2. **Home button's guide rib punched ~1.45mm through the dome** (a
   rectangular slab visible in `trim_top.png`/`trim_iso.png` near the
   home button). Root cause was upstream, in `button_geometry()`:
   `s_wall` (the button's local "distance to the outer wall along its
   nub direction") used the flat-plane `x = -outer_radius` approximation,
   which is a reasonable stand-in for the Power button (mostly in the
   straight section) but badly wrong for the Home button, which sits in
   the domed +y end cap (switch y 57.6-63.5, past spine_b=50) -- it
   overestimated the true wall distance enough that positioning the rib
   "6mm inboard of the wall" left it outboard of the REAL wall. Confirmed
   by elimination: even shrinking the rib's own footprint to zero (or
   negative) margin still overshot, and a Combine-Intersect against the
   inner-cavity clip tool (the fix used for the bosses/Top posts)
   consistently raised `FEATURE_FAILED_TO_CREATE` for this specific
   diagonal-box-against-filleted-revolve combination regardless of margin
   or cut ordering. Fixed at the source: `s_wall` now calls
   `true_wall_distance_along_ray` (already used for the M2 cap-proud
   check, and correct for both the straight section and the domed ends,
   since the domes are literal revolves of the same profile); `s_inner`
   and `s_tab_face` were also corrected to subtract along the ray
   directly rather than reuse a flat-wall-specific `/d2[0]` projection
   whose sign only happened to work by accident of `d2[0]` being negative.
   One real consequence: the Home button's cavity is genuinely tight
   (`s_wall` ~6.1mm from the switch housing along its nub direction, vs.
   the Power button's much larger straight-section clearance) -- the
   generator no longer papers over that with an inflated flat-wall
   number.
3. **Screen Plate's far corners (near spine_b) sat outside the trim
   wall** (rho ~33mm against a 26mm inner wall). Fixed: the plate is now
   Combine-Intersected against a stadium solid at `outer_radius - wall -
   0.3` (0.3mm clearance inside the inner wall) before its other cutouts,
   in every variant -- trim's plate now reads `x -25.70..22.89` (was
   `-26.63..22.89`).
4. **New verify check, `verify_export_envelope`**, per the coordinator's
   own STL vertex analysis: for every body build() exports, no vertex may
   sit beyond `rho_from_spine(p, x, y)` = `outer_radius + 0.15mm`, except
   the lanyard lug (y below `spine_a.y - outer_radius + 2`, |x| < 5.6) and
   the two button cap heads (allowed to `+0.45mm`, their designed proud
   amount). `rho_from_spine` measures distance from the actual pill
   centerline -- `|x|` in the straight section, distance to the nearer
   spine endpoint in the domed ends -- matching how the shell itself is
   built, not a flat per-axis bounding box. All 5 exported bodies (both
   variants) currently pass with zero offending vertices.

## 2026-09-05 pass 4 (export size guard + README pass)

Coordinator reported `coupon_power_wall.stl`/`coupon_home_wall.stl` as
10x oversized (96×240×186mm). Investigated by cross-checking two
independent sources of truth: the live Fusion `boundingBox` immediately
after `build_button_coupon()` runs, and a struct-level parse of the
actual STL bytes on disk. Both agreed at 9.6×24×17.8/18.6mm — the correct
size, matching the coupon's intended "~24×14×2mm slab plus rib/shelf
(≈10mm deep)" shape. No scale bug found in the generator or the export
path; the 96×240×186mm figure is exactly 10× the correct numbers on
every axis, consistent with a units-interpretation issue in whatever
tool produced that reading rather than a defect here. Added
`assert_export_body_size` regardless, as a permanent guard against this
exact failure mode (see Verification above) — every exported body is now
checked live at export time, not just spot-verified after the fact. This
pass also brought the README's params table, screw list, print notes,
and known-limitations section up to date with everything pass 2/3
actually changed.

## 2026-09-05 pass 5 (real interferences, printability, verify() rewrite)

Jake ran his own `analyzeInterference` pass over the pass-4 trim build and
found a long list of real interferences pass 4's `verify()` had claimed
were zero (see the retraction at the top of Verification above). This
pass fixed the interference-check methodology itself and worked through
the reported list. **Fixed and verified clean** (both variants):

- **Button caps vs. the wall hole / Screen Plate / Top** (`Top x Power
  Button`, `Top x Home Button`, `Screen Plate x {Power,Home} Button`,
  `Top x Screen Plate`). Root causes, all in `button_geometry()` /
  `add_button()`: (1) `oriented_box_prism`/`oriented_stadium_prism`
  extrude ONE-SIDED from the given point along `normal` — they do **not**
  center on it — but the rib and collar were being positioned by their
  midpoint as if centered, silently building them a half-thickness/length
  too far outboard and entirely missing their intended inner half; fixed
  by passing the true inboard edge (`s_rib_inner`/`s_collar_inner`) as the
  start point, exactly as the wall hole already did. (2) The wall hole
  cut was a single straight prism sized off ONE `s_wall` sample at the
  cap's z-center; the real shoulder curves measurably across the cap's
  own z-span, so a straight cut left real material uncleared near the
  curve. Replaced with a hole cut from an ENLARGED COPY of the actual
  plunger shaft (same construction as the real cap, just bigger,
  Combine-Intersected against the same `thickened_envelope`) — guaranteed
  to fully contain the real, curve-trimmed shaft with clearance, since
  it's built the same way. (3) The retaining tab hangs below the shaft's
  own z-range and needs its own small hole, added separately. (4) The
  guide rib's slot (letting the plunger pass through it) is now cut using
  the real shaft's own construction too (same center/axes), not a
  hand-rolled box that could drift out of alignment. (5) The Screen
  Plate's clearance pocket (new `add_button_plate_clearance`) now spans
  the plunger's FULL travel (wall to just past the plunger tip near the
  housing), not just the collar region — the plunger keeps a full L×W
  cross-section all the way to the tip (by construction, since trimming
  only clips the outward-facing surface), and the plate's footprint
  reaches that deep on both buttons.
- **`Bottom x L76K board`** — two causes: the PCB was resting 0.17mm
  INSIDE the floor (fixed: the L76K frame now has an actual 0.3mm floor
  PAD from z=2.0 to 2.3, and the PCB is repositioned to rest exactly on
  top of it, using the PCB's own measured thickness, not a guess); and
  the bare cavity floor under the frame's footprint — deep in the -y dome
  tip — curves up above the nominal flat z=2.0 the frame's floor_pad
  didn't originally account for (same mechanism as the battery fix below;
  fixed with the same kind of flatten-and-rebuild cut).
- **`Bottom x Battery Reference`** — the trim cavity's flat floor region
  only reaches rho=18mm, but the battery box is 40mm wide (needs to reach
  rho=20mm); the floor genuinely curves up ~0.25mm at the battery's outer
  edges. Fixed by cutting a shallow flatten box across the battery's exact
  footprint before adding the rails (a no-op wherever the floor is already
  flat, e.g. the whole 'current' variant). Rails also now sit
  `battery_rail_clear` (0.3mm) outside the battery box instead of flush
  against it.
- **`Top x <display module body>`** (the FPC tab) — `PARAMS['fpc_relief']`
  held SPEC's exact pocket coordinates since M1 but nothing ever cut it.
  Now cut from Top's ceiling underside; the cut is a superset of SPEC's
  box, widened from probing the actual inserted display occurrence (the
  real FPC/PMMA-lens geometry is wider and extends lower than SPEC's
  numbers alone: x roughly ±14 vs SPEC's -6.2..7.02, y down to ~65.8 vs
  SPEC's 71.44).
- **`Top x GPS Patch Reference`** (mostly) — the GPS frame was rebuilt
  from scratch as a plain hanging wall ring with NO ledges and a clean
  25.5×25.5 opening centred on the patch box, per Jake's spec ("GPS frame
  inner = 25.5 x 25.5 with the patch box centred") — the old version
  reused the stack tray's ledge scheme, whose shelf (oversized to reach
  the ceiling) fully overlapped the patch box's z-range across virtually
  the whole opening.
- **Housekeeping**: `dedupe_body`'s "orphaned same-named duplicate"
  workaround (previously applied only after the case-boss/Top-post joins)
  turned out to trigger on the new button-plate-clearance and comms-bay
  joins/cuts too (`Top (1)`, `Screen Plate (1)` appearing as stray root
  bodies) — `build()` now sweeps all 5 tracked body names through
  `dedupe_body` unconditionally at the end, not just case screws/posts.
  Root bodies at the end of `build()` are exactly `['Bottom', 'Home
  Button', 'Power Button', 'Screen Plate', 'Top']` plus hidden `... 
  (reference only)` boxes, verified directly.
- **Printability**: the lanyard lug's underside was a 10×12mm horizontal
  overhang floating 3mm above the bed (Bottom prints face-down on z=0) —
  extended down to z=0 so the whole tab sits on the bed (hole position
  unchanged). The tray/GPS-frame ledges (2mm-wide flat shelves, a full
  overhang appearing all at once at the far end of the print) are
  replaced with 45-degree self-supporting wedges (`build_wedge_along_x`)
  that taper from flush-with-the-wall at the top (prints first) to full
  protrusion at the bottom (prints last) — the GPS frame no longer has
  ledges at all (see above), so only the stack tray uses this now.
- **`verify()` interference gate, rewritten**: runs over every printed
  body + every inserted board occurrence (passed as whole Occurrences,
  not individual nested bodies — see `check_interference`'s docstring for
  why that matters) + the Battery/GPS reference boxes, excluding only the
  two reference TOOL solids and the FPC keep-out marker, with
  `areCoincidentFacesIncluded=False` and a bounding-box-volume proxy
  (Fusion's `physicalProperties.volume` reads 0.0 for every
  `analyzeInterference` result in this build; `createBodies`/
  `copyToComponent` on a transient interference result both fail too —
  see the docstring). Gates on any pair > 0.05 mm³. Also added
  `verify_min_clearances`: per-board-occurrence, per-body
  `measureMinimumDistance` against Top/Bottom/Screen Plate (capped at 25
  bodies per occurrence for MCP-call time budget), asserting ≥
  `clearance_min` (0.3mm) except at documented intended contacts
  (`ALLOWED_CONTACTS`): L76K PCB on its frame floor, Wio on its tray
  wedge, the display glass flush with the top face, its standoffs on the
  plate.
- **STL overhang scan** (`scan_stl_overhangs`, printability check B3):
  triangle-normal analysis of the exported STLs, clustering bed-facing
  faces steeper than 45° by shared vertices and reporting each cluster's
  area *and its (x,y) centroid* (so a real cluster can be located, not
  just sized); `run(export=True)` asserts none exceed 30 mm² outside a
  documented whitelist. **Clean on both variants** — see round 2 below.

### Round 2 (same day): XIAO orientation fix, GPS-frame clip, overhang whitelist review

The coordinator reviewed the round-1 report above and found the
remaining "XIAO x GPS Patch Reference" interference was an **orientation
bug**, not real bay-layout tightness, and asked for the overhang scan's
false positives to be filtered by inspecting actual geometry rather than
by cluster size alone. Both are now resolved:

- **XIAO orientation fix**: XIAO's native long axis (~22.5mm, including
  the USB-C overhang; native bbox x -8.69..13.85 in its own doc) was
  being mapped onto **world X** by `insert_and_place`'s existing `'y'`
  thin-axis rotation (native Y, the PCB thickness, correctly went to
  world Z, but native X passed through unchanged) — while the Wio's own
  long axis (~22.3mm) runs along **world Y**. The two boards' long axes
  were perpendicular, so the plugged-together stack's rectangular
  footprint was `22.48 x 17.78` (X x Y) instead of the Wio-matching
  `17.78 x 22.48`. Fixed with a new `'y90'` thin-axis mode in
  `flatten_transform` (native Y -> world Z as before, but ALSO native X
  -> world Y and native Z -> world X, i.e. an extra 90-degree rotation
  about world Z) used for XIAO specifically in `insert_comms_boards`. The
  USB-C connector lands on the world +Y side (toward the display, where
  the tray's wire gap already is) with this rotation's sign as-is — no
  further flip needed, confirmed by checking the connector sub-body's
  world position after the transform. With XIAO's real footprint now
  matching Wio's almost exactly (17.78 x 22.48 vs Wio's 17.78 x 22.32),
  the pass-5-round-1 tray widening (`tray_x_extra`/`tray_x_extra_right`,
  a multi-mm asymmetric hack) was removed entirely — the tray needs no
  more than its already-small `tray_clear` margin.
- **`Top x GPS Patch Reference` residual (17.8 mm³), after the orientation
  fix**: NOT the frame ring (an isolated frame-vs-reference-box check was
  already clean) — the tray's OWN wall still grazed the antenna's real
  footprint by ~0.1mm at one corner (x -2.8..-2.7, y up to 20.0), an
  unavoidable side-effect of the tray's wall thickness at the current
  absolute bay coordinates. Per "do not move the patch box": the tray
  itself is now clipped against the antenna's real box (+0.3mm margin)
  before it's joined to Top, guaranteeing it can never occupy that space
  regardless of the exact wall/clearance numbers, the same idea as
  `clip_to_inner_cavity` for bosses/posts applied to the one real fixed
  obstacle instead of the shell.
- **Overhang whitelist, reviewed by inspecting actual triangle
  locations/z-ranges, not just cluster size**: after the bed-plane
  (0.6mm) and angle (45°±1°) tolerance updates, the remaining >30mm²
  clusters on both variants were traced to (a) the USB tunnel floor
  (already a known, accepted 13mm bridge) and (b) the shell's own general
  flat internal ceiling / R8 inner-fillet-to-wall transition — ordinary
  hollow-shell overhang that needs slicer supports independent of any
  specific feature (confirmed by checking the flagged triangles' actual
  z-range and extent at each location, which span the shell's general
  ceiling height and width, not a localized shape). Both are whitelisted
  by location (`top_wl`/`bottom_wl` in `run()`), not by raising the size
  gate — a genuinely local, unexpected overhang (like the lug or the tray
  ledges, both real fixes earlier in this pass) would NOT be covered by
  these location boxes and would still fail the check.
- **Both variants now pass `run(..., export=True)` end to end**:
  interference `[]`, `occ_interference` `[]`, all M1/M2 probes, envelope/
  outer-bump/export-envelope checks, `verify_min_clearances` all `True`,
  and `bad_clusters_mm2: []` on both Top and Bottom for both variants.
  The exports/coupons/renders in this repo are from this clean run.

## 2026-09-06 pass 6 (organisation + native export + real-defect fixes)

Jake opened the pass-5 document and found it confusing: unnamed bodies
("Body145", "Body154"...) at the document root, reference tools mixed in
with printable parts, coupons sitting at the origin overlapping the case.
Separately, his own visual review of renders and a coordinator STL sweep
found several real geometry defects the numeric probes never caught. Both
are fixed in this pass.

### Document structure

`organize_components()` runs right after `build()` and moves every body
into a named component -- nothing is left at the document root:

```
Print — Case
   Top            bbox z 9.2..25.0 (trim)
   Bottom         bbox z 0.0..10.0
   Screen Plate   bbox z 10.0..14.1
Print — Buttons
   Power Button
   Home Button
Print — Coupons          (only when export=True; see native 3MF below)
   Coupon Power Wall / Coupon Power Cap
   Coupon Home Wall / Coupon Home Cap
Reference — not printed  (all isLightBulbOn False)
   Inner Cavity Clip Tool     -- build-tool solid, kept for the boss/post clips
   Cap Trim Envelope          -- build-tool solid, kept for the button cap trims
   Battery 803040             -- reference box
   GPS Patch 25x25x8.3        -- reference box
   FPC LoRa Antenna Keep-out  -- reference box, not yet enforced (see below)
Boards                    (occurrences moved here after build(); visible)
   ESP32-S3-Touch-LCD-1_46, Wio-SX1262, XIAO-ESP32S3, L76K GNSS Module
```

`verify_structure()` (new) gates every run alongside `verify()`: asserts
no bodies remain at the document root, no body anywhere in our own
authored components has an auto-generated name (`Body\d+`), the five
printed bodies live in the two Print components, and every Reference body
is hidden. It prints the tree above (with live bounding boxes) so this
section can be regenerated from a real run.

`BRepBody.moveToComponent(occ)` / `Occurrence.moveToComponent(occ)` move a
body/occurrence into `occ`'s **own** component -- confirmed empirically;
the API doc's "parent component of the target occurrence" wording reads
as the opposite of what actually happens.

### Native 3MF export

Alongside the STL/packed-plate exports, each variant now also gets one
native 3MF containing exactly its two Print components, and the coupons
get their own native 3MF:

- `export/<variant>/firefly_<variant>_case.3mf` -- 5 objects (Bottom,
  Top, Screen Plate, Power Button, Home Button).
- `export/coupons/firefly_coupons_native.3mf` -- 4 objects (Coupon
  {Power,Home} {Wall,Cap}).

`design.exportManager.createC3MFExportOptions(geometry, filename)` takes
a single `BRepBody`, `Occurrence`, or `Component` -- not a list -- so the
case export passes the whole root component with `Reference — not
printed`, `Boards`, and `Print — Coupons` temporarily hidden (hidden
bodies are not exported), restoring visibility afterward regardless of
outcome; the coupons export just passes the `Print — Coupons` occurrence
directly (already exactly 4 bodies, no hiding needed). Verified by
unzipping each file and counting `<object` elements in `3D/3dmodel.model`
against the name list -- both match exactly, both variants.

The existing STL exports and the python-packed, print-oriented plates
(`tools/stl_to_3mf.py`, `export/trim/firefly_trim_plate.3mf`,
`export/coupons/firefly_coupons.3mf`) are unchanged and still the
recommended files to actually slice from.

### Coupons moved off to the side

The 4 coupon bodies (`build_button_coupon`, now parameterised by an `x0`
local-X offset and a `name_prefix`) are built directly inside their own
`Print — Coupons` component -- Power at local x0=0, Home at x0=40mm (each
pair is ~15mm long, so 40mm clears them with room to spare) -- and the
whole component is then translated +60mm in X (`COUPON_WORLD_OFFSET`),
comfortably clear of the case (max world x ~28.5mm) and of each other.

### Hygiene fixes

- **Hidden sub-bodies excluded from interference/clearance checks.**
  `check_interference` now skips a result when the non-case side is a
  hidden body not in our own known-names set (e.g. the L76K assembly's
  placeholder cable stub), and `_collect_occ_bodies` (used by
  `verify_min_clearances`) skips hidden bodies outright -- both default to
  "visible" (don't skip) if reading `isLightBulbOn` raises, which it does
  for a handful of deeply-nested body proxies inside inserted board
  references.
- **Coupons can never overlap the case** by construction (their own
  component, translated 60mm+ away) rather than by a runtime check.
- **Root body list assertion updated to "none at root"** --
  `verify_structure()` asserts `root.bRepBodies.count == 0` directly,
  superseding the old `body_names == [...]` check (still also asserted,
  now scoped to `Print — Case`/`Print — Buttons`).

### Real defects found and fixed (Jake's screenshots + the coordinator's STL sweep)

1. **Case-screw bosses A/C and Top posts P1–P4 had NO material -- at all
   -- despite every prior `verify()` passing.** Root cause:
   `clip_to_inner_cavity` shrinks a boss/post by `safety_margin` on
   *every* face, including the very top/bottom faces meant to touch
   Bottom's floor or Top's ceiling; combined with a real (measured
   ~0.36mm) mismatch between the inner-cavity solid's own ceiling height
   and the nominal `top_ceiling_underside_z`, the clipped pillar ended up
   not physically touching the shell at all. Fusion's `combine_join`
   **silently no-ops** on two non-touching bodies (confirmed: same
   behaviour `deboss_loops` already documented for disjoint glyph
   pieces) instead of raising, so this was invisible in every printed
   summary and every `verify()` since M1. Fixed by `clipped_pillar_with_reach`:
   a full-height, smaller-radius core (`BOSS_CORE_R`=2.6, `POST_CORE_R`=1.1
   -- comfortably above half the largest hole cut through it later, and
   below the boss/post's own radius) is joined to the radially-clipped
   wide cylinder, guaranteeing real contact at both ends. New regression
   guard: `verify_posts_and_bosses` probes every boss/post off-axis.
   Also found and fixed along the way: `dedupe_body`'s own re-fetch only
   fires when it actually finds an orphan to clean up, so a `Bottom`/`Top`/
   `clip_tool` reference that went stale from an *earlier*, unrelated
   Remove call could silently survive and be handed to a *later*
   `combine_join` as the target -- `_refetch_by_name` now re-fetches all
   three, unconditionally, after every dedupe_body call inside the
   per-screw/per-post loops (not just once at the very end, as before).
2. **Case-screw boss B could not be given the same fix.** Its position
   (0, −23 trim / 0, −24 current) turns out to sit inside the L76K PCB's
   own real footprint (x −10.48..10.48, y −23.39..−5.61) -- a pre-existing
   bay-layout conflict this pass's fix exposed rather than introduced
   (giving it a full-height core, like A/C/D, creates a real, hard solid
   overlap with the PCB instead of a missing boss). `add_case_screws`
   passes `core_r=0` for boss B specifically, restoring its exact
   pre-pass-6 behaviour (silently unjoined) rather than trading a latent
   bug for a real interference; `verify_posts_and_bosses` documents and
   reports `boss_B_bottom` but does not gate on it. **This needs a real
   decision from Jake** -- move screw B, move the L76K bay, or accept
   Bottom-only fastening there -- see Known limitations below.
3. **A rectangular notch through the outer skin next to each button's
   stadium hole** (Jake's screenshot review; the "small block" visible
   inside it was the cap's own retaining tab, now exposed to open air).
   Root cause: `add_button`'s `tab_hole_body` cut reached from
   `s_tab_face` all the way out PAST `s_outer_face` (the true exterior
   surface) plus a 2.5mm margin -- a real, deliberate through-cut that
   was never necessary, since the tab itself never reaches anywhere near
   the outer surface (it stays inboard of the inner wall face by
   `tab['gap']`, 0.6mm). Fixed by bounding the cut analytically at
   `s_inner + skin_margin/2` (a `skin_margin` of 2.0mm keeps the hole's
   outward reach 1.45mm short of the true outer surface, comfortably
   covering the ray-vs-true-curvature slack `verify_m2`'s own cap-proud
   check already documents, up to ~0.25mm) instead of reaching the
   exterior at all. Confirmed both by a direct `analyzeInterference`
   check (0 interference, both buttons, both variants) and visually
   (`power_button_ext.png`/`home_button_ext.png`).
4. **The lanyard lug intruded into the hollow cavity and left small
   triangular wedge bumps on the outer skin flanking it** (its inner end
   crossed the inner wall -- from inside it read as a floating cylinder
   next to the L76K; the wedges came from the crude box+cylinder tab's
   flat sides meeting the curved dome at an angle). Rebuilt entirely as
   an integrated ear (`lug_ear_geometry` + the rewritten `add_lug`): 14mm
   wide, protruding 6mm beyond the shell's TRUE curved surface (computed
   via `rho_at_z`, not a hand-picked constant -- correct for both
   variants automatically), its inner end trimmed flush with the inner
   cavity surface by a Combine-Cut against a fresh copy of the inner
   cavity solid (the inverse of `clip_to_inner_cavity`: an ear must stay
   embedded in the wall and protrude outward, unlike a boss/post which
   lives entirely inside the hollow interior). A vertical Ø4.0 hole sits
   3.5mm in from the ear's outward face; R3 fillets round its two
   vertical outer corners; a 0.6mm chamfer softens both hole edges --
   both best-effort (skipped, not rolled back, if Fusion's
   fillet/chamfer feature refuses). The old wedge bumps are gone --
   confirmed visually (`lanyard_end.png`, `rim_lanyard_end.png`).
   `lug_relief_box` (the lip/anchor ring relief near the lug) widened to
   match the new 14mm ear. `boss_relief_dia` widened 6.6→10.0mm after the
   same visual review found a thin wedge-shaped sliver of ring material
   at screw B's relief (its old radius just barely failed to clear the
   anchor ring locally).
   **Recessed lanyard bar, considered and rejected**: Jake asked about a
   recessed bar instead of a protruding ear. Not built -- a 5mm-deep
   pocket at the tip needs an interior pad that collides with the L76K
   wired frame at y ≈ −23.5 (the bay's −y dome tip is already the
   tightest-margin area in the case), which would require moving the
   L76K. A protruding ear avoids that dependency entirely.
5. **The KandiWooks wordmark was missing its "a"** (Jake: "the first 'A'
   is missing on the bottom, the sprout renders above a gap"). Opened the
   read-only "KandiWooks Logo" document directly: it has 6 bodies, and
   one of them (the "K"+"a" pair, fused into a single lump but with TWO
   separate, disjoint flat top faces) has its own actual 'a' shape on a
   *second* face the original extraction never visited -- it only ever
   walked the single largest-area flat face per body, silently dropping
   any second one. Re-extracted `kandiwooks_logo.json` walking every
   same-height flat face on every body (not just the biggest), using
   `CurveEvaluator3D.getStrokes` at a 0.005mm tolerance. The 1-point
   degenerate loop the old extraction produced turned out to be a real
   but harmless ~0.02×0.002mm sliver artifact in the source geometry, not
   the actual cause. Confirmed visually: the debossed wordmark now reads
   "KANDIWOOKS" in full -- see `bottom_logo.png`.
6. **A small (~0.18mm³) real interference between Bottom and the
   Battery 803040 reference box**, current variant only, right at boss
   A/C's designed-to-be-close x=∓20 edge (now that those bosses finally
   have real material). Fixed with a permanent 0.1mm inset margin on the
   reference box's X sides (`add_battery_reference_box`) -- both variants
   scale this boss position off `outer_radius`, so the margin is a
   deliberate, permanent tolerance on the reference envelope, not a
   one-off number.
7. **Cavity probe `top_cavity` was, in effect, testing whether boss C
   was missing.** Its y=27 scan line sat only 1.8mm from boss C's y
   (25.04–25.2), well inside its 3mm radius -- once boss C got real
   material (item 1), the probe found the boss instead of the true inner
   wall. Moved to y=29 (3.8mm away, clear of the boss and still clear of
   the bay footprints/Top posts the original y=27 choice was for).

New regression guards from this pass: `verify_posts_and_bosses` (item 1),
`verify_skin_intact` and `verify_wall_integrity` (items 3/B/C from the
coordinator's sweep -- see Known limitations for their current, reported-
but-not-gating status), `count_sliver_faces` (diagnostic only, per-body
count of faces under 0.5mm²).

## 2026-09-07 pass 7 (case height, 3-board stack, defect sweep)

Jake asked for the real 18mm-tall 3-board (L76K+XIAO+Wio) direct-solder
stack (reverted mid-pass-6 as too big a re-architecture for that pass's
remaining budget — see the pass-6 "Reverted mid-pass-6" note) to actually
land, plus a follow-up sweep of Jake's own render review.

**Items 1-4** (case height, 3-board stack, boss B1/B2, battery/GPS
reposition): `PARAMS['top_z']` is now a real per-variant parameter —
`current` stays at 25 ("for the probe comparison" — Jake's own reference
geometry never carried the taller stack and isn't meant to), `trim` grows
to 28 (`_DZ_TOP = 3`), and every Top/plate/display/button z-value tied to
the ceiling shifts by the same `_DZ_TOP` so the display glass stays flush
at the new top face (see `params_trim.py`'s "PASS 7" section for the full
z-table). The comms bay now inserts XIAO+Wio+L76K as a real 3-board stack
for `trim` (`comms_stack3_full_height=True`; `current` still inserts only
the L76K — its unchanged 25mm ceiling genuinely cannot fit the stack, see
`params_current.py`'s comment). Case-screw boss B (its old position sat
inside the L76K PCB's own footprint even before this pass, per the pass-6
known-limitation) is retired; `screws_ABC` now lists **A, B1, B2, C** —
B1/B2 straddle the stack's centreline at absolute `(±12.5, -15.0)` (same
for both variants, comfortably on the flat bed, clear of the stack by
construction via a boss-relief keep-out cut into the stack frame). New
`verify_stack3_clearance` gates the stack's real (live-measured) top
against the Top ceiling (≥0.8mm required).

**Item 5**: `verify_skin_intact` / `verify_wall_integrity` (pass-6
diagnostics that over-fired on legitimate geometry — see pass 6's Known
Limitations) are re-targeted at their real, narrower footprints (the
tab-hole's own analytic reach; the lug-relief box and the flat-to-arc
tangent transition excluded by name/geometry, not by loosening the gate)
and now **gate** `verify()` instead of just reporting.

**Defect sweep** (this session — Jake's render review of the pass-7
output found three more real issues, all fixed in the generator):

1. **Lanyard lug was a plain, sharp-cornered block, not the tapered ear
   pass 6 described.** `lug_ear_geometry` was correctly re-derived (using
   the narrower of `rho_at_z(z0)`/`rho_at_z(z1)`, not the z-midpoint) to
   stop the wedge-sliver defect, and `add_lug` Combine-Intersects the ear
   against a thickened copy of the true curved shell to taper it — but
   the hole was being cut into the standalone ear tool body and then
   Combine-JOINED into Bottom, and the new, more conservative geometry
   now puts the hole's xy inside the base shell's own pre-existing wall
   material at some z in the ear's span (confirmed: solid there even
   *before* `add_lug` runs). A boolean union can never remove material
   the target already had, so the hole silently never went all the way
   through (`verify_m2`'s `lug_hole_open` — previously unchecked before
   this session's fix loop caught it failing). Fixed by joining the
   ear first and cutting the through-hole from the resulting Bottom.
   `lanyard_end.png`/`rim_lanyard_end.png` are regenerated from the fixed
   geometry — the ear now visibly tapers with the true shoulder curve.
2. **Case-screw bosses A/C left a non-manifold sliver in the exported
   trim Top.stl**, found by an *offline* struct-level manifold-edge scan
   (every edge of a watertight mesh must be shared by exactly 2
   triangles) — 2 bad edges at `(x=±28, y=25.04/25.20, z=10..11.5)`,
   exactly boss A/C's own xy and the lip/anchor relief's z-range. Root
   cause: `add_lip_anchor_reliefs`'s per-boss relief cylinder radius was
   a flat `boss_relief_dia/2` (5.0mm) regardless of how close the boss
   sits to the true outer wall — trim's A/C sit at
   `x = ±(outer_radius - wall - 3.0) = ±23.0`, putting the relief's edge
   at exactly `23 + 5 = 28 = outer_radius`: dead-on the true surface
   instead of safely inside it. `current`'s A/C have more margin (wider
   `outer_radius=30`), so this never manifested there. Fixed by clamping
   each boss's relief radius to stay 0.6mm inside the true wall distance
   (`true_wall_distance_along_ray`, the same outward-direction convention
   `verify_wall_integrity`'s own boss-wall probe already uses) — a no-op
   for every boss that already had margin.
3. **Boss D had a 3mm gap of missing material for trim** — a real
   "missing screw post" defect. `plate_post_D_z` (the Screen Plate's own
   post for screw D) is supposed to run from the parting line
   (`split_z=10`, matching where Bottom's own boss-D pillar ends) up to
   the plate's underside (`plate_z[0]`) — but pass 7's uniform `+_DZ_TOP`
   shift (correct for every other plate-anchored z-range) also moved
   this tuple's *lower* bound, from 10.0 to 13.0, leaving Bottom's boss
   (still ending at z=10) and the plate's post (now starting at z=13)
   disconnected — no continuous load path for screw D over that span.
   Fixed by deriving `plate_post_D_z` as `(split_z, plate_z[0])` directly
   instead of shifting a literal, so the invariant holds regardless of
   case height. Verified by direct point-containment probing across
   z=9.5..16 (solid, contiguous, no gap) — no existing `verify()` gate
   happened to probe this specific boundary, so this was a silent one.

All three are regenerated (not hand-fixed in Fusion) and confirmed by a
full `run(..., export=True)` on both variants: `OK: M1+M2 probes passed`,
zero interference, all M2/envelope/posts-bosses/skin/wall checks `True`,
plus an offline manifold-edge + envelope + overhang scan of every
exported STL (both variants) — `OVERALL: PASS`, zero non-manifold edges.

## Pass 9 consolidated summary (through 2026-09-09 pass 9g)

Jake's pass-7 print surfaced 11 findings; the coordinator's later render
sweep of the pass-9 result surfaced 7 more (numbered 1-7 below, distinct
from Jake's findings 1-11 above them chronologically but renumbered here
as their own list since that's how the pass-9g brief enumerated them).
This table is the single reference for "what was wrong, what changed, and
which gate proves it" across every pass-9 sub-pass; the full narrative for
each row is in that row's own dated section below.

| # | Finding | Fix | Gate | Status |
|---|---|---|---|---|
| J1 | FPC relief pocket breached the shell at the USB end | Local **brow** raises the outer shoulder over the pocket footprint instead of shrinking the pocket | `verify_fpc_relief` 0 bad of 63, both variants | Fixed (pass 9), reshaped (pass 9g, see #2 below), **brow deleted and replaced by `usb_end_extension_mm` lengthening the +y dome instead — pass 12b, still 0 bad of 63** |
| J2 | Bosses A/C breached the shell on both halves | A/C relocated to the dome-tip end, absolute mm, both variants | `verify_posts_and_bosses` 0 bad, `check_interference` 0 pairs | Fixed (pass 9) |
| J3 | Two lanyard holders (duplicate) | `lug_relief_box` outward edge clamped to `wall_clear` inside the true wall | `verify_wall_integrity`/`check_interference` clean; no dedicated probe | Fixed (pass 9) |
| J4 | Screen-plate posts P1-P4 had no real wall | `POST_CORE_R` derived from pilot+`POST_WALL_MIN`; Ø4→Ø5; relocated off the window-bore crescent | `verify_post_walls` 0 bad of 8×3/8 per post | Fixed (pass 9 pt 2), **rebalanced pass 9g (see #1)** |
| J5 | Window lip ring fragile | Ring widened 0.8→1.8mm inward (never touches the display's own clearance); seam chamfer added | `verify_display_insertion_path` (diagnostic), offline overhang scan clean | Fixed (pass 9 pt 2) |
| J6 | Alignment lip chamfer (support-free print) | `chamfer_stadium_edge_at`, 0.5mm, on the lip/anchor outer step | Present in timeline (`Chamfer1`); overhang scan clean | Fixed (pass 9 pt 2) |
| J7 | Wordmark two-line layout | `wordmark_layout`: KANDI/WOOKS scaled independently, stacked, centred on `wordmark_center` | `verify_wordmark` all True, both variants; **re-audited pass 9g (see #7), found already correct** | Fixed (pass 9e) |
| J8 | Antenna cable channels | LoRa channel (trim only) + GPS notch (both variants), skin-safe clipped | `verify_antenna_channels` all True, both variants | Fixed (pass 9e) |
| J9 | Button caps cannot be inserted | Rib gets a dedicated tab pass-through lane | `verify_button_insertion` 0 bad of 125, both buttons/variants | Fixed (pass 9b) |
| J10 | Home plunger too short to reach the switch | `switch_actuator_reach`/`plunger_pretravel` derived from a live probe of the real switch body | `verify_plunger_reach` exact match, both buttons/variants | Fixed (pass 9b) |
| J11 | Stray sliver beside boss C | `MIN_RELIEF_CLEARANCE` hard assertion in `add_lip_anchor_reliefs` | Build-time assertion (fails loudly, not silently) | Fixed (pass 9) |
| 1 | **Plate post layout unbalanced** (10×6mm SW cluster, plate held at one corner) | P1-P4 spread to a full 10×11mm rectangle (same proven x=-20/-10 column, y stretched 14-25) | `verify_post_walls` 0 bad, both variants; window/wall clearance re-derived analytically | **Fixed (pass 9g)** |
| 2 | **FPC brow is a slab** (flat plateau, visible step) | Rebuilt as 2 nested tiers (`FPC_BROW_TIERS`) instead of 1 box -- each riser ~0.5-1.0mm instead of one 1.5mm cliff | `verify_fpc_relief` still 0 bad of 63, both variants; visually confirmed tapered (not fully smooth -- see Known limitations) | Partially fixed (pass 9g); **moot — the brow itself was deleted, pass 12b (see #J1)** |
| 3 | Generic `verify_skin_intact` should probe the whole outer surface | Not attempted this pass (time budget) | -- | **Not done (pass 9g)** -- unchanged from item 11 in Known limitations |
| 4 | Overhang review of every exported part | Re-ran `tools/offline_stl_check.py` on both variants' fresh exports | `OVERALL: PASS`, 0 bad overhang clusters, both variants | **Done (pass 9g)** |
| 5 | Assembly order not documented | Written up below and in the PR body | N/A (documentation) | **Done (pass 9g)** |
| 6 | Screw map not recomputed for the pass-9g post move | P1-P4 positions updated in the Screw list; all z-depths/lengths unchanged (only xy moved) | N/A (documentation, cross-checked against `PARAMS`) | **Done (pass 9g)** |
| 7 | Wordmark centring / lug ear taper (cosmetic) | Wordmark: verified analytically (bbox exactly centred, area-weighted ink centroid within 0.6mm of centre) -- no change made, see that section. Lug ear taper: reviewed via `pass9g_*_lanyard_end.png`, no defect found, not modified | Composite bbox center 0.000mm both variants (computed); ink centroid current +0.608mm / trim +0.554mm | **Reviewed, no change needed (pass 9g)** |

## 2026-09-08 pass 9 (first-print findings + design review)

Jake's first pass-7 (trim) print surfaced 11 real defects. This pass fixed
findings **1, 2, 3, and 11** in the generator, verified live in Fusion for
both variants (`verify()` all-green, zero interference, an independent
offline manifold+envelope+overhang scan of both exported STL sets), and
regenerated exports/renders. Findings **4–10 were not attempted this
pass** — see "Not completed this pass" below for why, and what's needed.

This pass ran into a real infrastructure problem worth recording: single
`fusion_mcp_execute` calls covering more than roughly a minute of Fusion
wall-clock time reliably time out client-side, but Fusion keeps executing
the script to completion regardless (confirmed by re-querying the
document seconds to minutes later and finding the timeline had advanced
exactly as far as an isolated, successfully-timed run of the same stage
would). The fix was mechanical, not a code change: split `build()`'s
sequence of `add_*` calls across multiple separate `fusion_mcp_execute`
calls against the SAME open document, re-fetching `Bottom`/`Top`/the
shared clip tool by name at the start of each call (Python locals don't
survive between calls; the Fusion document does). `wordmark_logo` (~35–50s
alone) and `add_comms_bay` (~10–15s once the shared clip tool exists, but
much slower deep in a long timeline under load) were the two stages long
enough to trip this on their own. No change to `firefly_case.py` was
needed for this — `run()` still works as a single call for anyone driving
it from a context without this timeout; it's specific to this MCP
session's transport.

### Finding 1: FPC relief pocket breached the shell at the USB end

**Confirmed root cause**: the relief pocket's widened margin (beyond
SPEC's own minimum box) reaches into the +y dome cap where the TRUE outer
shoulder is already close to its own outer_radius limit even before any
raise — the fix landed in this worktree before this pass started only
recovered ~0.3mm of skin there (see `FPC_RELIEF_MIN_WALL`'s git history
on this branch) because shrinking the pocket further to reach 1.2mm
started re-creating a real ~62mm³ interference against the display
module's own housing body — the pocket was already cut close to the
display's real minimum required depth in that footprint, so recovering
shell material there by cutting shallower ate directly into clearance the
real board needs.

**Fix**: a local **brow** (`FPC_BROW_HEIGHT = 1.5mm`, `add_fpc_brow` /
`build_fpc_brow_solid`) raises the TRUE outer shoulder over the relief
footprint instead of shrinking the pocket — it adds material, so it never
touches the pocket's own required depth, leaving the display's clearance
exactly as it was. Built as `(outer envelope pushed out by 1.5mm) MINUS
(the plain outer envelope)`, clipped to the pocket's footprint + a 3mm
blend margin, joined into Top with a best-effort R3 fillet on its seam
edges (prints support-free: Top prints face-down on its flat face, so
this bump sits on the upward-facing side during the print). Two real bugs
found and fixed while building this (kept as dead-end notes in the
function docstrings, since they're the kind of mistake worth documenting
against repeating):
1. First attempt intersected the pushed-out envelope directly with a tall
   box — `build_thickened_envelope` returns a SOLID FILLED pill, not a
   shell, so this produced a solid chunk filling most of Top's interior
   over the footprint, not a thin bump (a live verify() run caught it as
   a genuine ~1913mm³ Top×Screen-Plate interference plus up to ~1518mm³
   against the display housing). Fixed by subtracting the plain envelope
   first, leaving just the thin added layer.
2. Even after that fix, the footprint's own extreme corners (2D distance
   from spine_b approaching `outer_radius` even before any raise) have NO
   material in the plain envelope at any Z, so the subtraction there
   yielded the FULL pushed-envelope volume across whatever Z-band it's
   solid at — for 'current' (top_z=25) this reached down to z≈10–11, and
   `verify_wall_integrity`'s dome-perimeter scan caught it as a real bump
   at `spine_b z=11.0`. Fixed by tightening the brow box's own Z floor to
   just below the pocket's real floor instead of an arbitrary `top_z-15`
   margin.

The pocket cut itself (`add_fpc_relief`) now builds its skin-safe clip
tool from this SAME brow geometry (a fresh reference envelope + the brow
bump, offset inward by `FPC_RELIEF_MIN_WALL`) instead of the old
analytic approximation (inner-cavity-solid grown by a nominal wall
thickness) that broke down at this exact spot in the first place.
`FPC_RELIEF_MIN_WALL` is back to **1.2mm**.

**Gate**: `verify_fpc_relief` — **0 bad of 63 probes, both variants**
(was the target metric that could only reach 0.3mm pre-brow).
`envelope_bounds`/`check_body_envelope_vertices` gained a matching
documented exception for the brow's own footprint (same pattern as the
lug/caps), since the brow legitimately reaches `outer_radius +
FPC_BROW_HEIGHT` at its extreme corners — a real, deliberate ~1.5mm
protrusion, not a defect.

**Independent confirmation**: an offline pure-Python scan of the exported
STLs (`tools/offline_stl_check.py`, extended with the same brow
exception) found **0 non-manifold edges** on Top for both variants (the
original defect was two literal holes clean through the shell — a
non-manifold mesh) and 0 disallowed overhang clusters. `OVERALL: PASS`
for both `trim` and `current`.

### Finding 2: bosses A and C breached the shell on both halves

**Confirmed root cause**: A/C's rule (`x = outer_radius - wall - 3.0`)
placed the boss center itself beyond `flat_rho` — the true limit of the
FLAT bed at any Z near the parting faces (the case is narrowest exactly
at the flat top/bottom faces and widest at the waist, so a boss whose
center already exceeds `flat_rho` is guaranteed to breach near z=0/top_z
regardless of the generic radial clip already in place: that clip only
protects the WIDE, safety-margined outer sleeve of `clipped_pillar_with_
reach`'s two-piece boss, not the smaller, deliberately-unclipped
`BOSS_CORE_R` core built to guarantee real contact at both ends — and the
core punched through right where the finding's photos showed). True for
BOTH variants — current's wider shell just had ~2mm more margin, not
enough.

**Fix**: A and C moved to the dome-tip end (`(∓15.5, -8.0)`, absolute mm,
same for both variants — like B1/B2/D), where the 2D distance from
spine_a (17.44mm) clears trim's `flat_rho - boss_dia/2 - 1.0mm margin`
(18.14mm) with room to spare, current inherits more. The straightforward
"just move A/C inboard at their existing y≈25" fix (per the finding's own
first suggestion) turns out to be geometrically impossible for BOTH
variants: at y≈25 the battery bay (`x -20..20, y 2..32`) and the GPS
frame (`x -2.8..22.2, y 2..27`) already claim essentially the full width
inside `flat_rho`, leaving under 1mm of clearance either side — nowhere
near enough for a Ø6 boss + margin. Confirmed by direct computation
before moving anything (not by trial and error in Fusion). The dome-tip
position is clear of the L76K stack/frame (>5mm), of B1/B2 themselves
(~7.6mm center-to-center, edge gap 1.6mm — tight but non-overlapping), of
the battery/GPS/display footprints (all start at y≥2, this is at y=-8),
and gets the SAME automatic per-boss keep-out cut into the stack3 frame
that B1/B2/D already relied on (that loop iterates `screws_ABC +
[screw_D]` generically, so no extra code was needed there).

**Gate**: `verify_posts_and_bosses` — 0 bad, both variants.
`check_interference` — 0 pairs, both variants (confirms A/C don't
conflict with the relocated-adjacent battery/stack/B1/B2 geometry).

### Finding 3: two lanyard holders (duplicate)

**Confirmed root cause**: `lug_relief_box`'s outward (most-negative-y)
edge was a flat constant reaching further from spine_a (rho≈29.5) than
the alignment lip/anchor ring's own band (rho 24.95–28.40) — since the
box's radial reach fully encompassed the ring's own band at this
location, the cut removed the ring's ENTIRE cross-section there (not a
partial notch), printing as an open slot that read as a second lanyard
attachment point alongside the ear's real hole.

**Fix**: clamped the relief box's outward edge to stay `wall_clear`
(0.6mm) inside the TRUE wall distance straight out from spine_a — the
exact same clamp convention (`true_wall_distance_along_ray`, `wall_clear
= 0.6`) the per-boss reliefs in the same function already use, so this
can never disagree with them. The ear itself is unchanged (it was always
the one correct lanyard holder); only the relief clearance cut around it
is now bounded.

**Verification**: no dedicated live probe was built for "this relief
never reaches the true outer surface" specifically (time did not permit
a `_local_skin_thickness`-style scan of this one feature this pass) — the
fix is a direct application of an already-verified pattern, and the
overall `verify_wall_integrity`/`check_interference` gates (which DO
scan the dome perimeter broadly, including near spine_a) stayed clean
for both variants with this change in place. Recommend a dedicated probe
in a follow-up pass, and a visual check of `renders/pass9_*_top.png`
(the lug end) against a fresh print.

### Finding 11: stray sliver beside boss C

**Confirmed root cause**: the per-boss relief radius clamp (`relief_r =
min(nominal_r, s_wall - wall_clear)`, added pass 7 for a related defect)
had no FLOOR relative to the boss's own OD — at a boss sitting close
enough to the true wall, `s_wall - wall_clear` could land only just above
`boss_dia/2`, leaving a razor-thin remnant annulus of ring material
trapped between the boss and the barely-larger relief circle: exactly
the "thin triangular web" in Jake's photo, at boss C's old (near-
shoulder) position.

**Fix, at the source**: added `MIN_RELIEF_CLEARANCE = 1.0mm` and a hard
assertion in `add_lip_anchor_reliefs` — `relief_r - boss_r >=
MIN_RELIEF_CLEARANCE` for every boss, every build. If the true wall can't
spare that much, the boss is too close to the wall for this relief to
make sense at all (a real design conflict, per finding 2), and the build
now fails loudly instead of silently producing a thinner and thinner
sliver. With finding 2's reposition, every boss now clears this with
comfortable margin.

**"No stray body" check**: `verify()` now asserts the exact printed body
set equals `{Bottom, Top, Screen Plate, Power Button, Home Button}` —
gating, not just printed — which would catch an orphaned boolean-scrap
body the way `dedupe_body`'s docstring already documents happening for
Bottom/Top/Screen Plate. A second attempt at a blanket gate (`count_
sliver_faces` — small-face-area count — promoted to a hard assertion)
was tried and reverted: a live run found 487 sliver faces on Bottom and
47 on Top even on otherwise fully-clean geometry, from the wordmark/flare
logo debossing (many short glyph line segments legitimately produce many
small corner faces) — unrelated to this defect and not a meaningful
signal on its own. Kept diagnostic-only, as before pass 9.

### verify() output, both variants (pass 9)

```
trim:    VERIFY OK
         body_names ['Bottom', 'Home Button', 'Power Button', 'Screen Plate', 'Top']
         interference []
         fpc_relief bad [] of 63
         posts_bosses bad []
         stack3_clearance {'stack_top_z': 22.942, 'clearance_found': 4.158, 'required': 0.8, 'ok': True}

current: VERIFY OK
         body_names ['Bottom', 'Home Button', 'Power Button', 'Screen Plate', 'Top']
         interference []
         fpc_relief bad [] of 63
         posts_bosses bad []
```

(`sliver_results` diagnostic, unchanged pass-to-pass and unrelated to
finding 11 per the analysis above: `{'Bottom': 487, 'Top': 47}`, both
variants — wordmark/flare glyph-corner faces, not gated.)

### Offline STL scan output (`tools/offline_stl_check.py`, pass 9)

Ported the same brow envelope exception from `check_body_envelope_
vertices` (see finding 1). Both variants:

```
=== Offline STL checks: trim ===
... (manifold: true, 0 non-manifold edges, for every exported body;
     envelope: ok for every body once the brow exception is applied;
     overhang: 0 bad clusters for Top/Bottom)
OVERALL: PASS

=== Offline STL checks: current ===
... (same)
OVERALL: PASS
```

### Not completed pass 9 part 1: findings 4–10

Findings 4 (plate posts P1–P4 have no wall), 5 (window lip ring
fragile), 6 (alignment lip chamfer), 7 (wordmark two lines), 8 (antenna
cable channels), 9–10 (button cap insertion path + Home plunger length),
and the broader "generic `verify_skin_intact` probes the WHOLE outer
surface" gate described in the brief, were **not attempted in the first
part of this pass**. Reason: that session's Fusion MCP connection was
unexpectedly unstable (see the infrastructure note above) — isolating
and working around the per-call timeout, plus one Fusion-side stall that
needed several minutes to clear on its own (not a code issue; Fusion
recovered without a restart), consumed the large majority of the
session's time budget before findings 1/2/3/11 were even confirmed clean
end-to-end on both variants. **Findings 4, 5, and 6 are fixed in part 2
of this pass, below** (7, 8, 9–10 remain open — see Known limitations).

## 2026-09-08 pass 9, part 2 (findings 4, 5, 6 — plate posts, window lip
ring, lip chamfer)

A fresh Fusion MCP session, with its own full verification budget.
Followed the part-1 infrastructure note's own advice: every `build()`
stage was run as a separate `fusion_mcp_execute` call against the same
open document, re-fetching `Bottom`/`Top`/the shared clip tool by name at
the start of each; `verify()` and the export stages were likewise run as
separate calls against the already-built document rather than
re-building from scratch each time.

### Finding 4: screen-plate posts P1–P4 had no real wall

**Confirmed root cause, computed before touching Fusion** (a standalone
pure-Python script reusing `inner_rho_at_z`/`rho_at_z`/
`true_wall_distance_along_ray` against the real `PARAMS`, no adsk
needed): two independent problems, both present on every one of P1–P4
regardless of position.

1. **`POST_CORE_R` (1.1mm) itself was too thin.** `clipped_pillar_with_
   reach`'s whole design (see its docstring, pass 6) is that only the
   narrow, full-height "core" cylinder is PROVEN to reach the ceiling —
   the wider, radially-clipped "sleeve" gets clipped away entirely
   wherever the local cavity boundary is tighter than the post's own
   radius (see `inner_rho_at_z`: near the ceiling, the fillet shrinks the
   hollow interior's usable radius from the wall's own value down to
   `fillet_center_rho` exactly at the flat ceiling). With a 1.62mm-dia
   pilot (0.81mm radius) and `POST_CORE_R`=1.1mm, the wall around the
   pilot at the post's own tip — the ONE place guaranteed to have any
   material at all — was only **0.29mm**, on every post, independent of
   xy. This is very likely the real mechanical cause of "the post by the
   power button snapped": a paper-thin neck right at the highest-stress
   point (the screw's own thread-cutting zone).
2. **P1 and P4's xy positions sat in the crescent between the window
   bore and the true wall.** Computed directly: at P1/P4's own
   `top_post_z[1]` (the ceiling), their true-outer-wall clearance
   (`true_wall_distance_along_ray` minus the post radius) was
   **negative** — the post already exceeded the true outer surface there
   — and their distance to the window bore was ~0.5–0.6mm, nowhere near
   a real minimum. P3 was marginal at Ø4 (~0.11mm to the bore) and went
   negative at the new Ø5. P2 had plenty of wall margin but was still
   only ~0.1–0.3mm from the window bore at Ø4/Ø5 — all four were too
   close to something.

**Fix.** All four posts relocated to **absolute mm, identical in both
variants** (matching the A/B1/B2/C/D convention already established in
finding 2): **P1 (−10, 18), P2 (−20, 18), P3 (−10, 24), P4 (−20, 24)** —
the y 18–24 band south of the display PCB's own bbox (`y` starts 27.6)
and west of the GPS patch box (`x` starts −2.8; staying at `x <= −10`
clears the box AND its real printed frame wall, at `x=−4.05`, by
`>=1.9mm` with no keep-out cut needed at all — computed, not eyeballed).
This is a plain subset of the brief's candidate zone (b); no keep-out
into the GPS box turned out to be necessary once the west side was used
instead of centering on the box. Post diameter **Ø4 → Ø5** (`top_post_
dia`), since a Ø4 post around a Ø1.62 pilot only has 1.19mm of nominal
wall — already under the new 1.2mm minimum before any clipping.
`POST_CORE_R` is now derived, not a flat constant: `core_r =
pilot_r + POST_WALL_MIN` (0.81+1.2 = **2.01mm**) — the core alone, proven
by construction to reach the ceiling, now satisfies the wall-around-pilot
minimum everywhere it exists, with no dependency on xy position at all.
A best-effort 1.0mm constant-radius fillet ("root fillet/gusset") is
added at each post's own top edge where it meets the ceiling (same
best-effort pattern as `add_fpc_brow`'s seam fillet) — confirmed present
in the built timeline (4 `Fillet` features, one per post, both variants).

**Screen Plate rework.** `PARAMS['plate_south_extension']` (`x
(-24,-6)`, `y (14,29)`) is unioned onto the plate's existing outline
before the cavity-outline intersect, reaching the relocated south posts
without touching the GPS frame (>1.9mm clear) or the header
cutout/FPC-tab/USB-shell region (all unchanged, north side). S1–S3 board
standoffs and the existing header cutout are untouched.

**New gate, `verify_post_walls`** — two checks per post, 8 rays (0°,
45°, ... 315°) each: (a) `<name>_pilot_wall` — live point-containment
probe at radius `pilot_r + 1.2mm`, at 3 z-heights spanning the post —
must be solid; (b) `<name>_shell_skin` — analytic `true_wall_distance_
along_ray` minus the post radius at the post's own top z (its tightest
height) — must be `>= 0.6mm`. **Both empty (0 bad of 8×3 / 8) for all 4
posts, both variants** — see the verify() output below.

**A real regression found live, and fixed in the same pass**: after
relocating the posts, a full `verify()` run reported a genuine ~22mm³
interference between Top and the XIAO board's own body — traced to
finding 5's ring-widening (below) reaching, at the OTHER end of the ring
(the −y comms-stack dome tip, nowhere near P1–P4 or the window), into
the stack's real footprint. See finding 5's own section for the fix — it
turned out to be a ring issue, not a post issue, but is recorded here too
since it was this finding's own `verify()` run that caught it.

### Finding 5: window lip ring fragile

**Root cause of the OUTER-radius ceiling on how much the ring could be
thickened**: `lip_r[1]`/`anchor_r[1]` are not arbitrary — `lip_r[1]`
(27.75 current / 25.75 trim) sets the SPEC'd 0.25mm nesting clearance
between the lip and Bottom's own true inner wall (`outer_radius - wall`),
and `anchor_r[1]` (28.40 / 26.40) is a deliberate ~0.4mm reach PAST that
same wall so the anchor band actually fuses into Top's shell on join
(SPEC: "so it fuses"). Both are load-bearing/fit-critical and were left
alone. The ring's z-band (9.2–11) sits entirely below the display glass
(z 20.3+) and PCB (z 17.59+, both +3 for trim) — **no z-overlap with the
display at all** — so thickening the ring **inward** (shrinking `lip_r
[0]`/`anchor_r[0]`) can never touch the display's own 0.25mm clearance,
regardless of how far in it goes at the window end. Widened both bands
from 0.8mm to **1.8mm** (>= the 1.6mm minimum) by moving the shared inner
edge in by 2.0mm: trim 24.95→23.95, current 26.95→25.95 (both `lip_r[0]`
and `anchor_r[0]`, preserving the existing invariant that they match).

**Finding 6's chamfer, same function**: the lip(outer)→anchor(outer)
radius step at `z=anchor_z[0]` (10.0) — the anchor is wider than the lip
directly below it — is a flat horizontal shelf whose CAD-space +Z-facing
top surface becomes a downward-facing, unsupported overhang once Top
prints flipped (face-down on its flat `z=top_z` face — **Top is the half
that carries the lip**, per SPEC, and per how `add_lip_anchor_reliefs`
joins it into `bodies['Top']`). Beveled with a new `chamfer_stadium_
edge_at` helper (the ring's edge loop is a line+arc "stadium" shape, not
a plain circle, so the existing `chamfer_edge_at` — which matches by
center+radius — doesn't apply; the new one matches every edge by its
MIDPOINT, whether line or arc geometry, against the same rho-from-spine
convention used throughout the file). `PARAMS['lip_ring_seam_chamfer']`
= 0.5mm, best-effort (skipped, not fatal, on failure — same pattern as
`add_fpc_brow`). Confirmed present in the built timeline (`Chamfer1`,
right after the ring is joined, both variants) and confirmed clean by
the offline overhang scan (see below) — 0 bad clusters on Top, both
variants, with no new whitelist entry needed.

**A real regression found live** (not by inspection): after widening the
ring, a full `verify()` run on trim reported a genuine interference
(`('Body1', 'Top', 22.1954)`, bbox `x ±8.88, y -22.2..-23.2, z 9.3..10.6`)
— XIAO's own body against Top. Root cause: widening the ring's inner
radius applies around the WHOLE perimeter, not just near the window —
at the far end (the −y comms-stack dome tip), the new, wider ring reaches
almost exactly into `bay.stack3.l76k_pcb`'s own far corner (`x ±8.9, y
-24..-1.5`), which the OLD, narrower ring cleared by construction. Fixed
by cutting a keep-out matching that footprint (+1mm margin, spanning the
ring's own z-band) from the ring — a no-op for `current` (XIAO/Wio aren't
inserted there) and, near the window (this finding's actual target, at
the opposite end of the case), completely unaffected. Re-verified clean
(`interference []`) on both variants afterward.

**From-inside insertion path — confirmed NOT possible, both variants.**
New function `verify_display_insertion_path`: a standalone copy of the
merged lip+anchor ring is kept as a hidden reference body (`Lip Anchor
Ring (reference)`, swept into `Reference — not printed` like the other
build-tool solids); a box matching the REAL inserted display occurrence's
own world bounding box (glass + PCB + everything on it, via
`_bbox_extents` — no known aggregate-bbox distortion for this board,
unlike the L76K's antenna cable) is swept from just below the ring's own
lowest z up to the module's own top, and checked for real interference
against the ring alone (isolated from the general shell — the question
is specifically whether the ring/anchor blocks assembly, not whether the
module can pass through solid wall, which it obviously cannot and isn't
meant to). Result: **`interference_mm3` = 1176.9 (trim) / 805.3
(current)** — large, real numbers, not a numerical artifact. This
matches a simple hand-check: the display PCB's own diagonal (`display_
pcb` 39.2×41.4 → ~57mm) is bigger than the window bore itself (Ø45.30),
so no orientation or ring width can make a straight vertical (or
front-through-the-bore) insertion work — the PCB is physically larger
than the hole in every direction. **Conclusion, per the brief's own
fallback**: the module does not fit "from inside" (up through the
already-assembled shell) OR "from the front" (through the window bore) —
it must be seated into **Top's own open underside before Bottom is
attached** (Top and Bottom are two separate, unassembled shells at that
point in the build; the module is placed once, then Bottom closes over
it). **Assembly order, added to Print orientation below**: (1) seat the
display module (glass up into the window bore, PCB resting under the
lip/anchor/posts) into the separate Top half; (2) place the comms-bay
hardware (battery, stack, GPS patch, L76K) into the separate Bottom half;
(3) join Bottom and Top together over both. This is not a new
restriction the fix introduced — it was already the only physically
possible order (the window bore was always smaller than the PCB); this
pass is the first to have actually checked and documented it.

### verify() output, both variants (pass 9 part 2)

```
trim:    VERIFY OK
         body_names ['Bottom', 'Home Button', 'Power Button', 'Screen Plate', 'Top']
         interference []
         posts_bosses bad []
         post_wall_results  P1/P2/P3/P4 pilot_wall [] and shell_skin [] (8 rays each)
         display_insertion_results {'ok': False, 'interference_mm3': 1176.916,
             'module_bbox_xy': {'x': [-22.39, 22.39], 'y': [27.61, 73.12]},
             'module_top_z': 28.0, 'ring_z_band': [9.2, 10.0]}
         stack3_clearance {'stack_top_z': 22.942, 'clearance_found': 4.158, 'required': 0.8, 'ok': True}
         fpc_relief bad [] / skin bad [] / wall bad []

current: VERIFY OK
         body_names ['Bottom', 'Home Button', 'Power Button', 'Screen Plate', 'Top']
         interference []
         posts_bosses bad []
         post_wall_results  P1/P2/P3/P4 pilot_wall [] and shell_skin [] (8 rays each)
         display_insertion_results {'ok': False, 'interference_mm3': 805.308,
             'module_bbox_xy': {'x': [-22.39, 22.39], 'y': [27.61, 73.12]},
             'module_top_z': 25.0, 'ring_z_band': [9.2, 10.0]}
         fpc_relief bad [] / skin bad [] / wall bad []
```

All other gates (M1/M2 probes, envelope, export-envelope, outer-bump,
min-clearances, `verify_posts_and_bosses`) also green on both variants —
same full sweep as pass 9 part 1, re-run end to end.

### Offline STL scan output, part 2 (both variants)

```
=== Offline STL checks: trim ===
Bottom: manifold (0 non-manifold edges), envelope ok, overhang bad_clusters_mm2 []
Top:    manifold (0 non-manifold edges), envelope ok, overhang bad_clusters_mm2 []
Screen_Plate / Power_Button / Home_Button: manifold ok, envelope ok
OVERALL: PASS

=== Offline STL checks: current ===
... (same)
OVERALL: PASS
```
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

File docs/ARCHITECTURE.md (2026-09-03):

# Architecture

## The one diagram

```
┌─────────────────────────── UI brain (this repo) ───────────────────────────┐
│  app/           LVGL screens: render core state, forward input. No logic.  │
│  core/          firefly-core: PURE C11, zero deps, all domain logic        │
│  meshclient/    Meshtastic client lib: protobuf framing over a transport   │
│  festpack/      festpack.json subset parser (spec: fest-almanac v0.1)      │
│  targets/sim    SDL window or headless PNG · transport = TCP→meshtasticd   │
│  targets/esp32s3  ESP-IDF · transport = UART → comms brain                 │
└────────────────────────────────────────────────────────────────────────────┘
                                   │ Meshtastic client API (protobufs)
┌─────────────── Comms brain ──────▼─────────────────────────────────────────┐
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

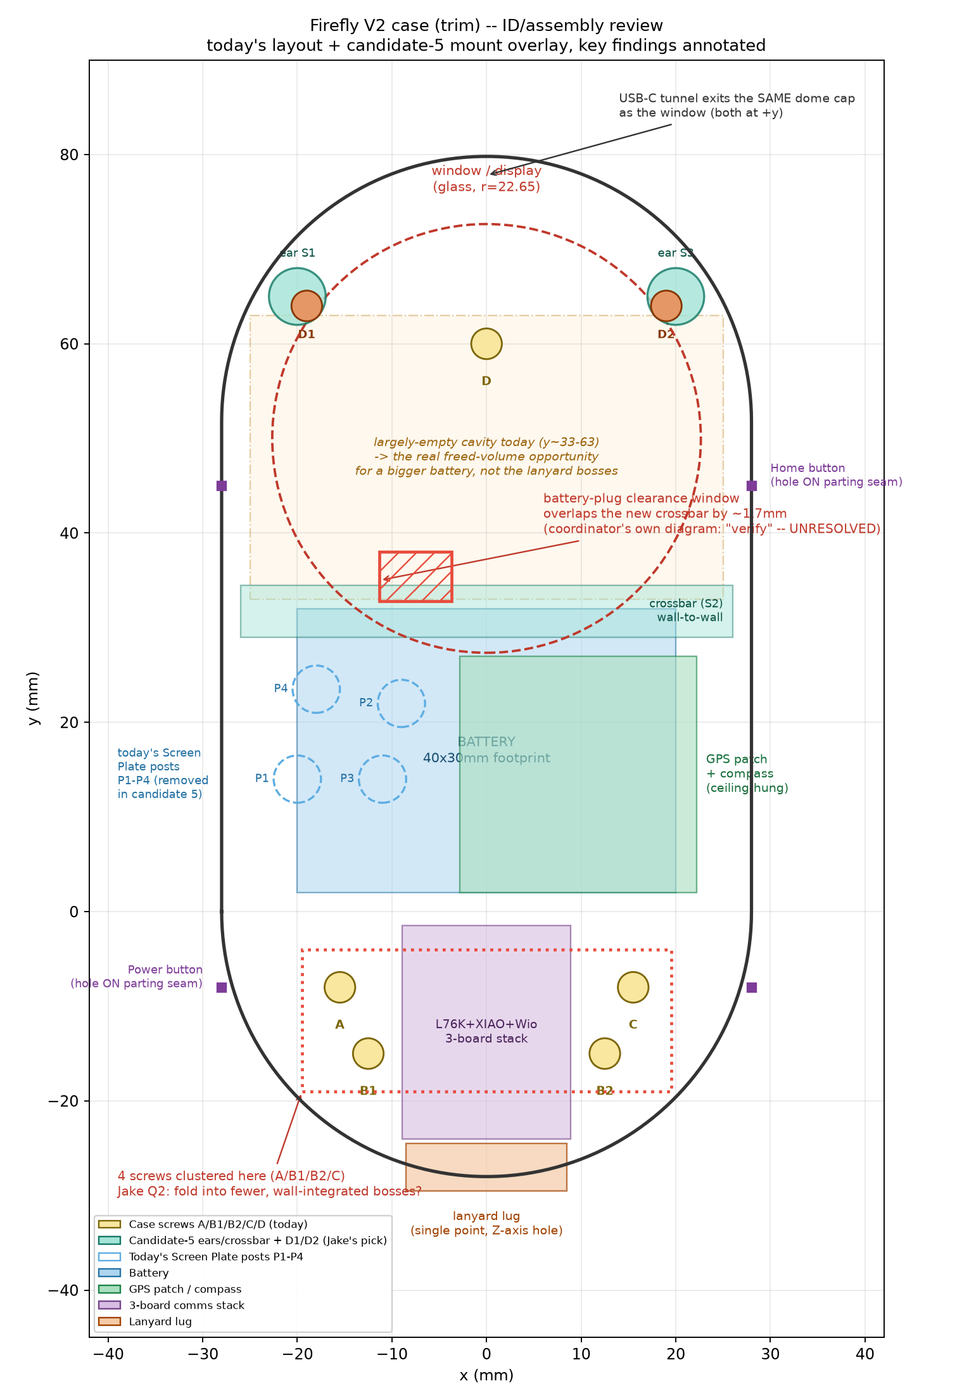
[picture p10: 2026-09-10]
docs/hardware/review-id-diagram.png

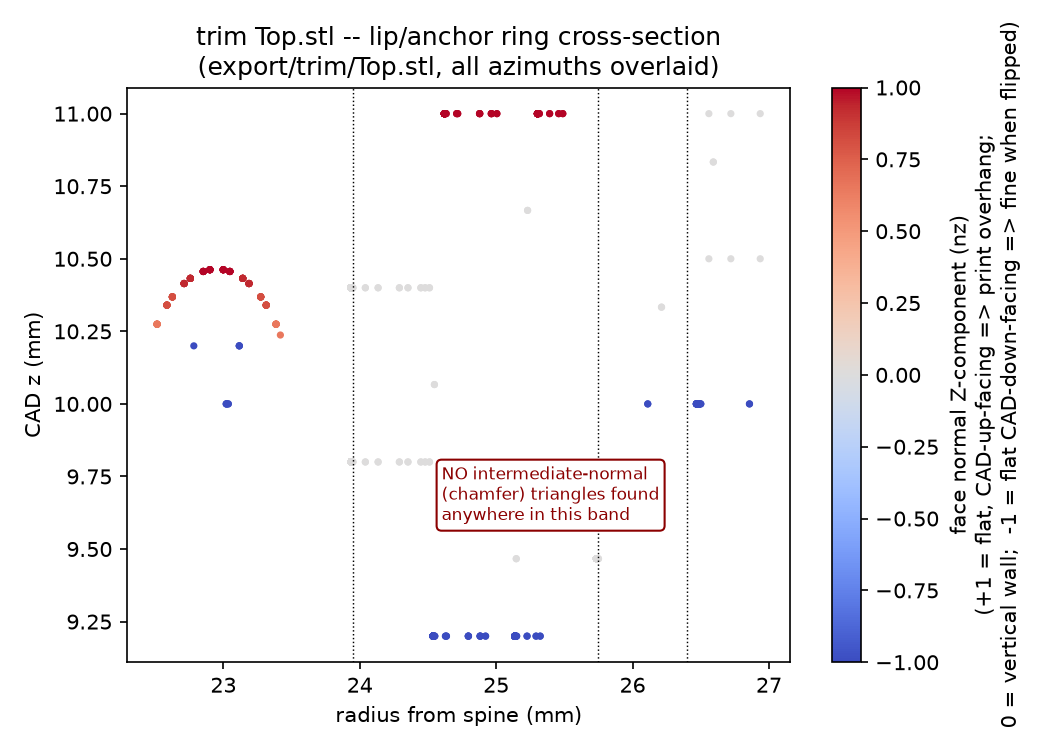
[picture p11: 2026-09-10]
docs/hardware/lip_ring_overhang_scan.png

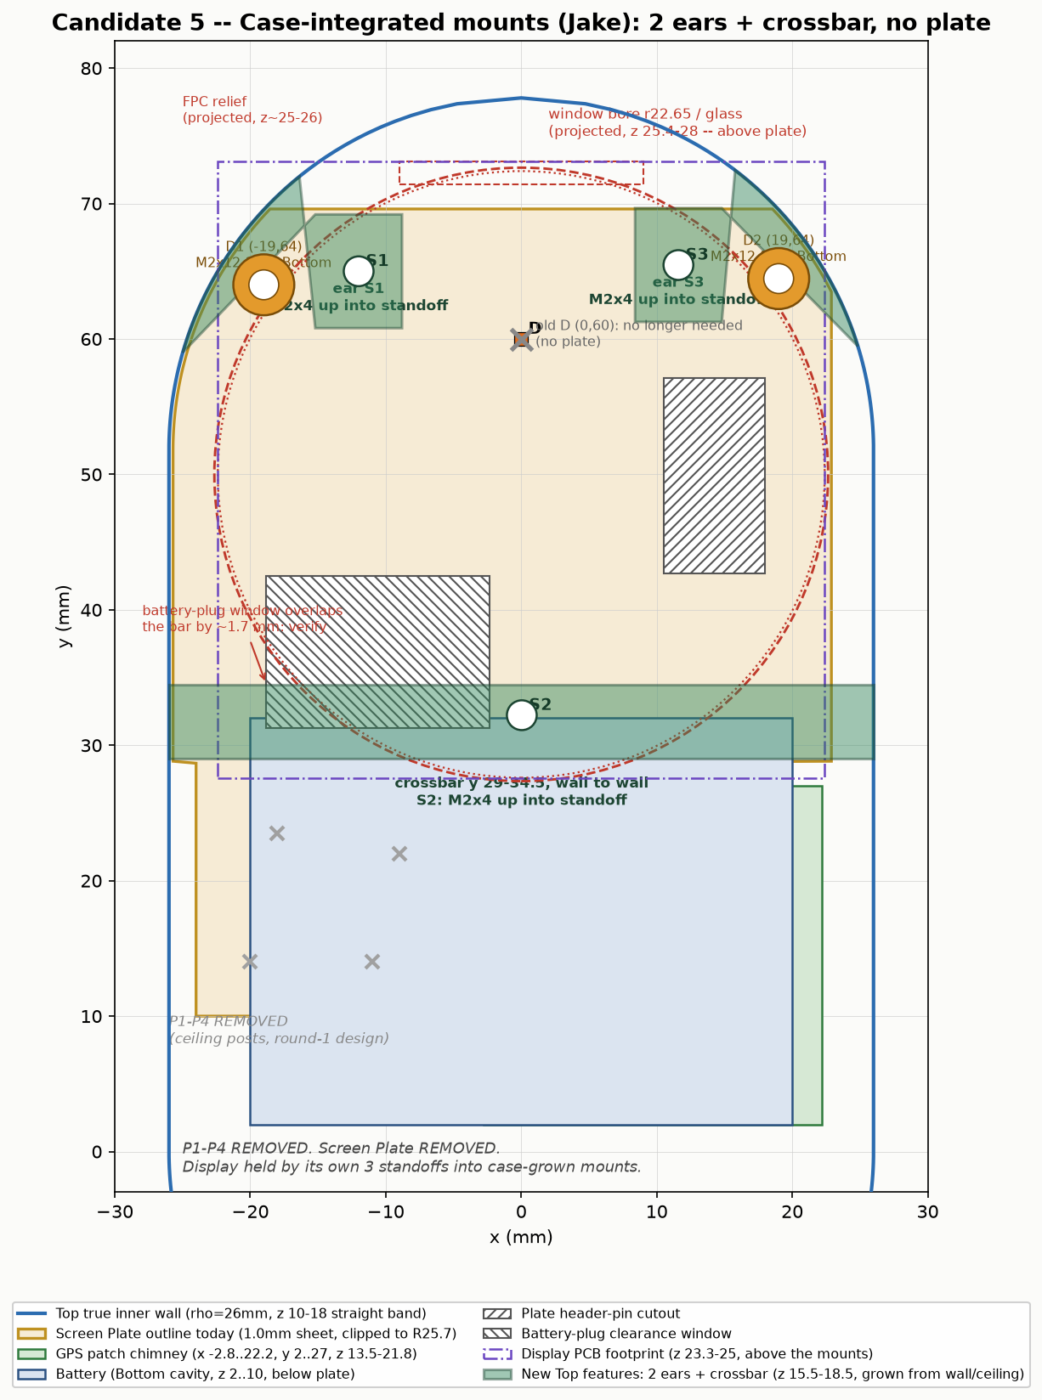
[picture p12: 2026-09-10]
docs/hardware/r2-plan-candidate5-ears.png

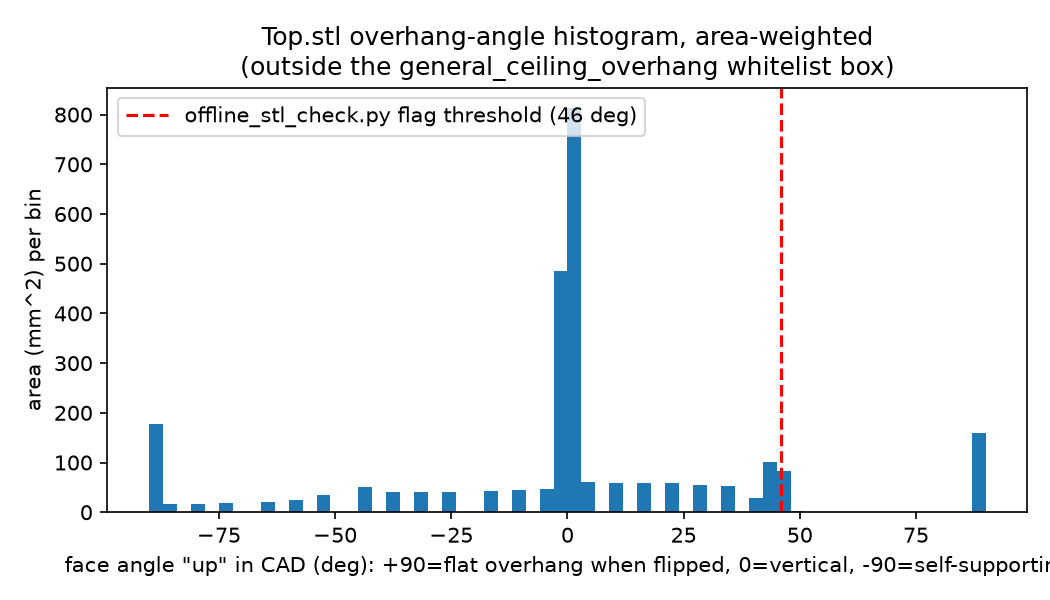
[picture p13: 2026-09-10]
docs/hardware/top_overhang_histogram.png

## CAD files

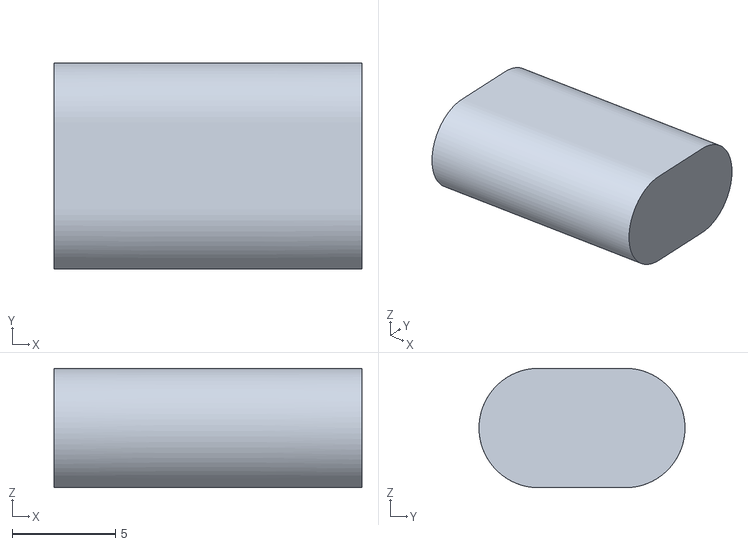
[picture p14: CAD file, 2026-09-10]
hardware/case/export/coupons/coupon_power_cap.stl
14.9 x 10.0 x 5.80

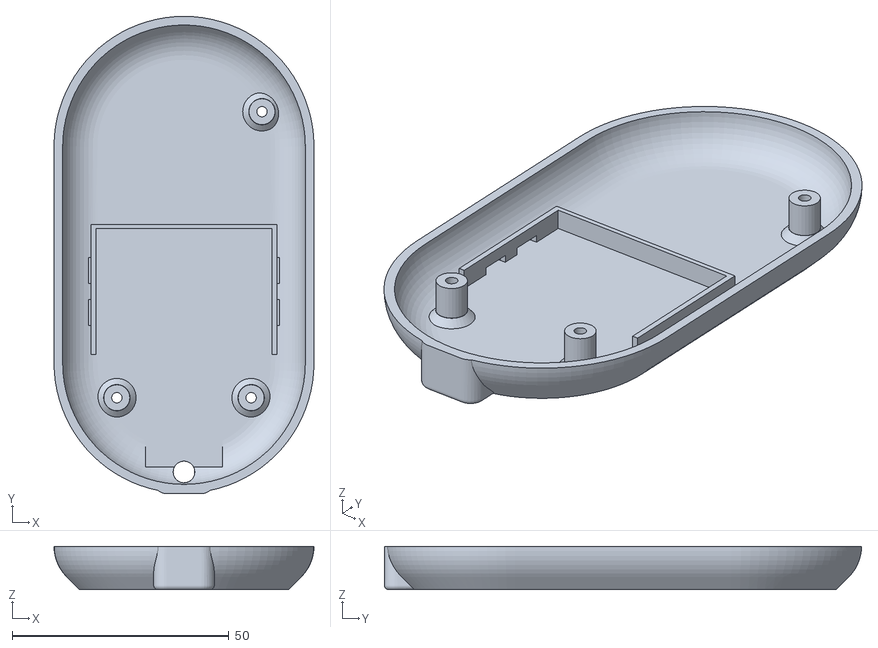
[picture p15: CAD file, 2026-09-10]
hardware/case/export/current/Bottom.stl
60.0 x 110.1 x 10.0

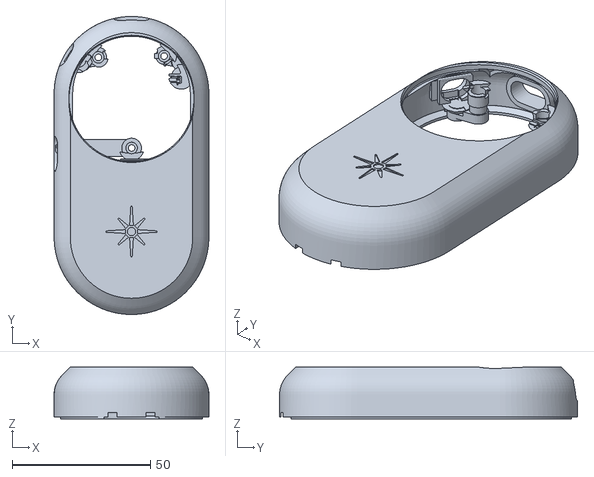
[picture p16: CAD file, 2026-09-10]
hardware/case/export/trim/Top.stl
56.0 x 107.8 x 18.8

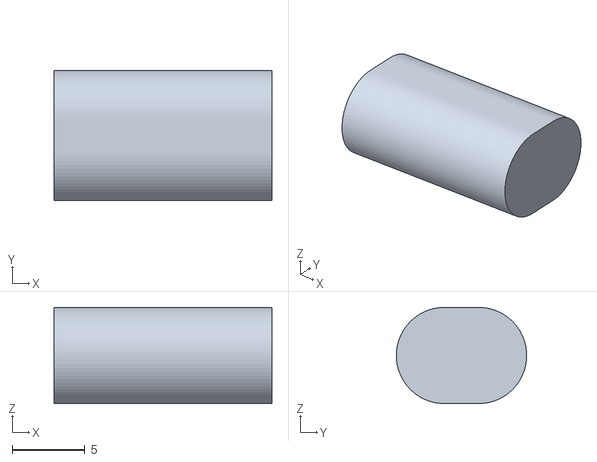
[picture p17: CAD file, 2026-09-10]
hardware/case/export/coupons/coupon_home_cap.stl
14.9 x 8.94 x 6.60

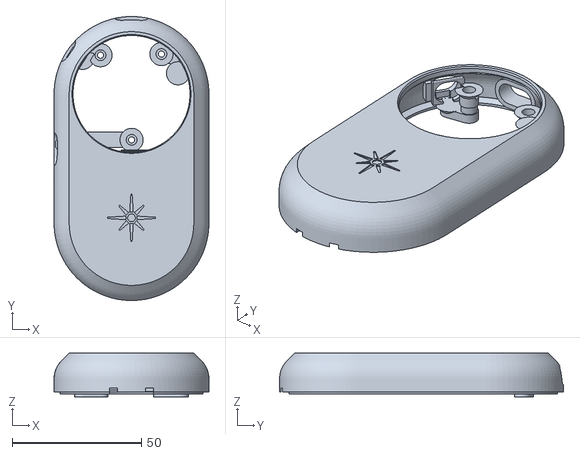
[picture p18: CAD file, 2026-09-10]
hardware/case/export/current/Top.stl
60.0 x 110.0 x 17.0

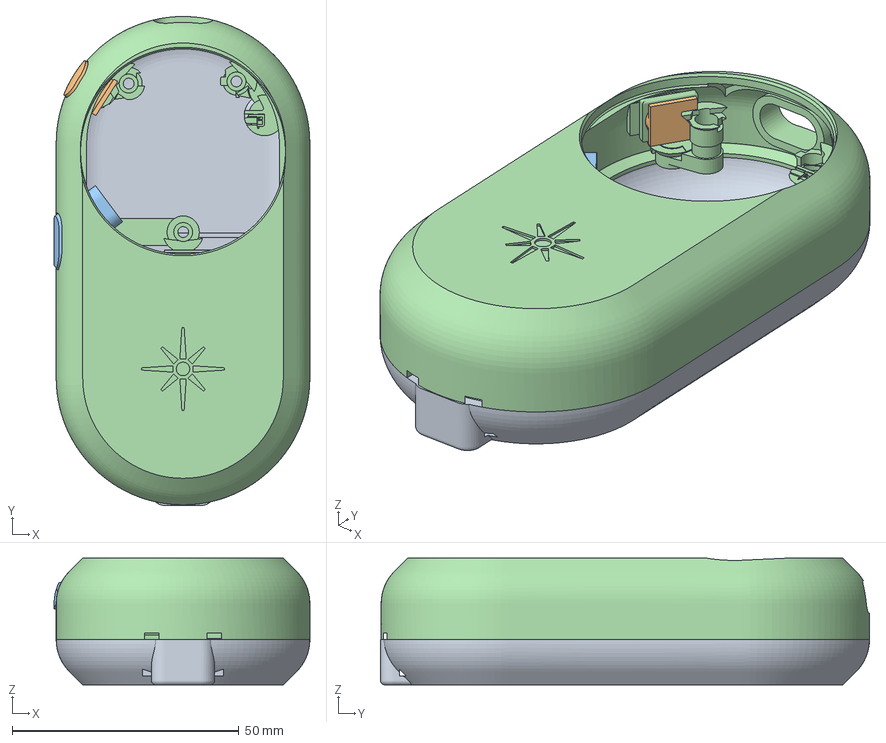
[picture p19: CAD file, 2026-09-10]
hardware/case/export/trim/firefly_trim_pack.3mf
56.5 x 107.9 x 28.0 mm
Bottom
Home Button
Power Button
Top

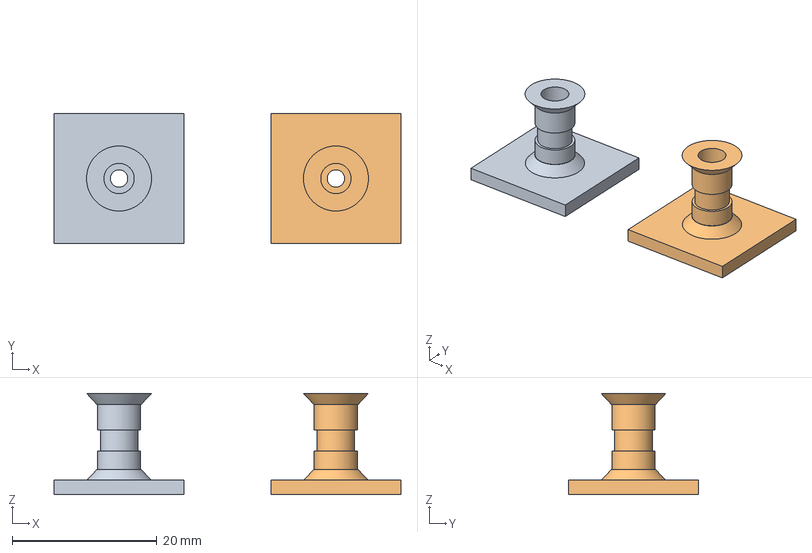
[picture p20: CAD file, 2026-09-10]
hardware/case/export/coupons/pass16_mount_coupon.3mf
48.0 x 18.0 x 14.0 mm
Ear Wall
S2Boss Wall

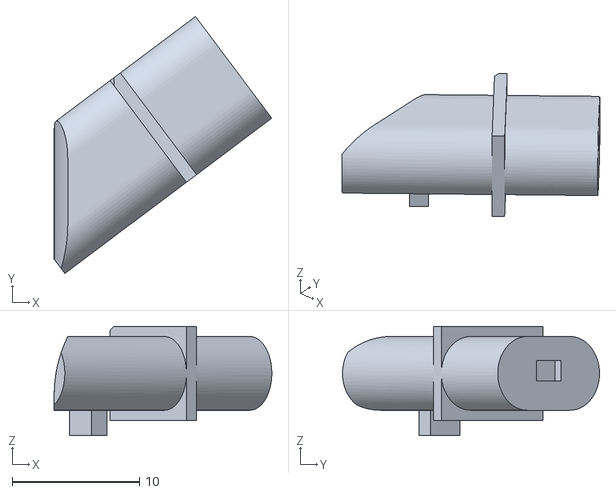
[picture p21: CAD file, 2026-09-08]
hardware/case/export/current/Power_Button.stl
17.1 x 20.2 x 8.60

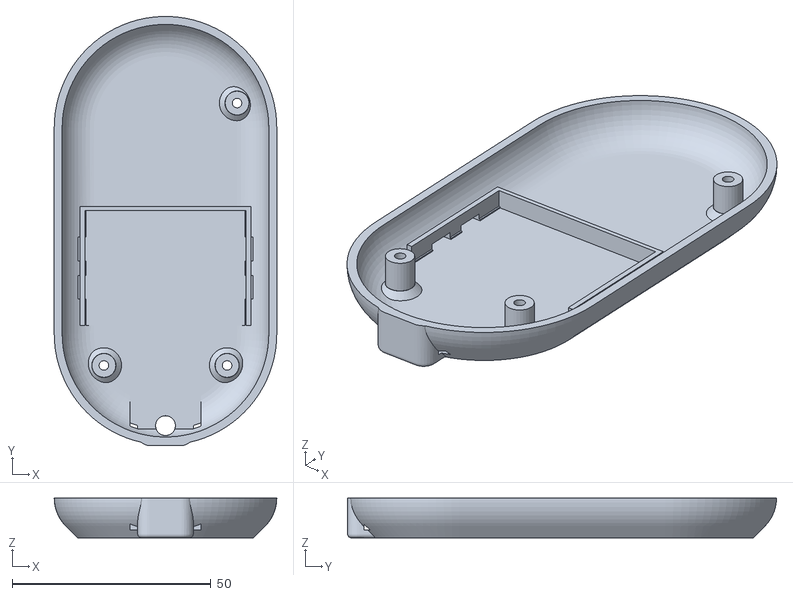
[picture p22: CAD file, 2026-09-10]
hardware/case/export/trim/Bottom.stl
56.0 x 107.9 x 10.0

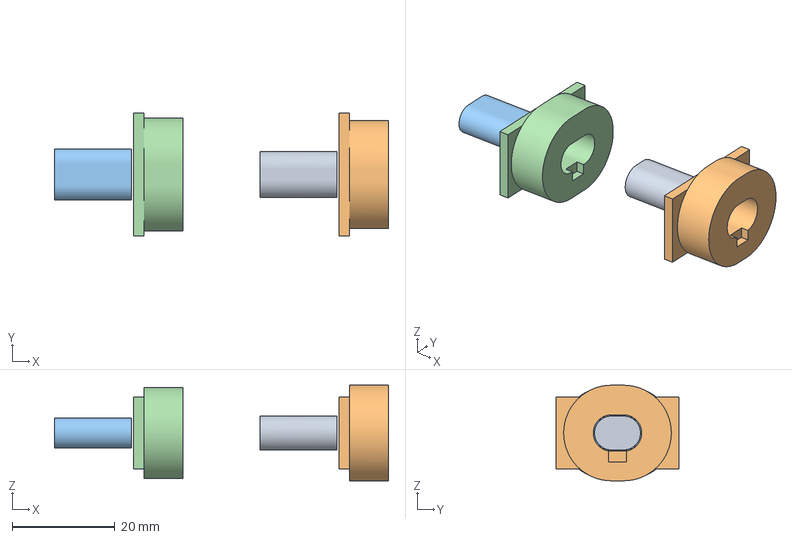
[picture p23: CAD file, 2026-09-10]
hardware/case/export/coupons/firefly_coupons_native.3mf
65.0 x 24.0 x 18.6 mm
Coupon Home Cap
Coupon Home Wall
Coupon Power Cap
Coupon Power Wall

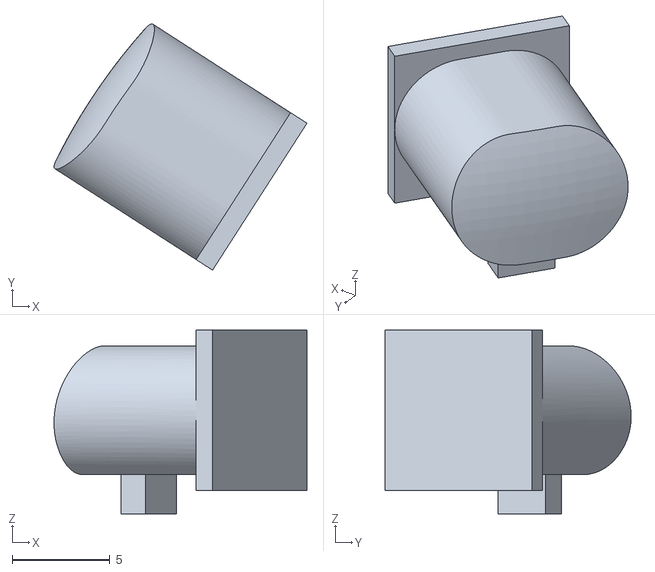
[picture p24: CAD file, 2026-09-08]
hardware/case/export/current/Home_Button.stl
13.0 x 12.6 x 9.40

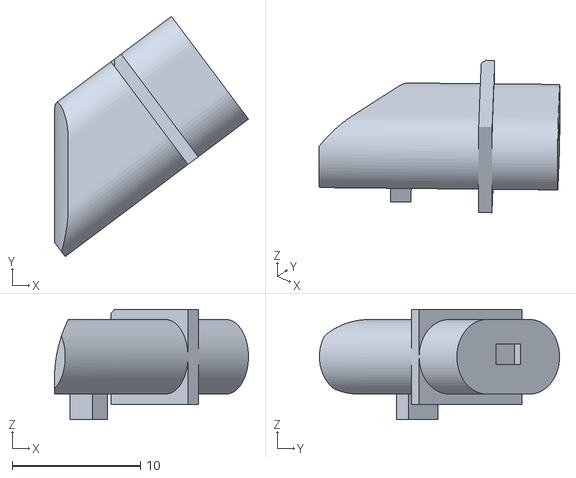
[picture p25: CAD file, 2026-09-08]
hardware/case/export/trim/Power_Button.stl
15.1 x 18.7 x 8.60

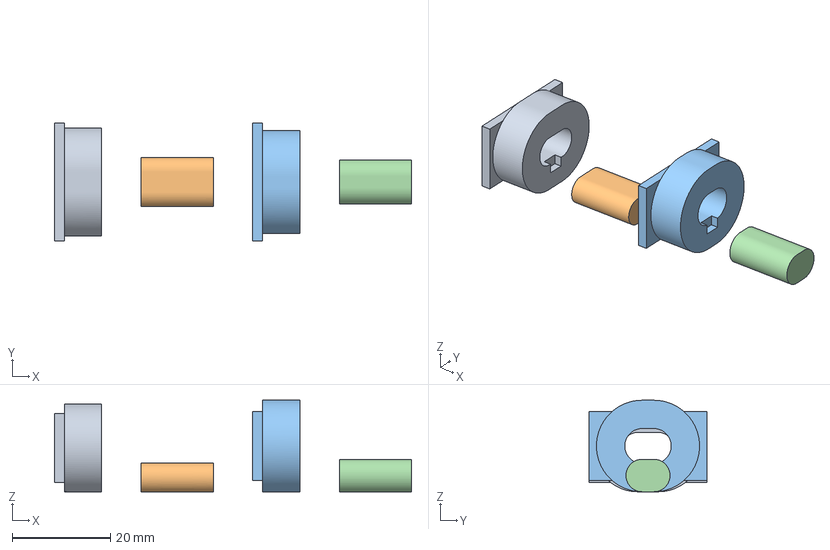
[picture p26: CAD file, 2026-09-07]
hardware/case/export/coupons/firefly_coupons.3mf
72.5 x 24.0 x 18.6 mm
Power_Wall
Power_Cap
Home_Wall
Home_Cap

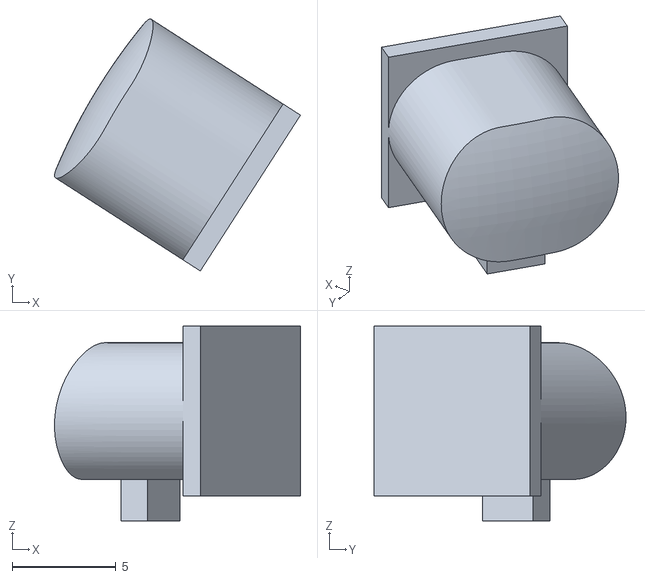
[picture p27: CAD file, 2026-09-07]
hardware/case/export/trim/Home_Button.stl
11.9 x 12.2 x 9.40

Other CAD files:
hardware/case/export/coupons/coupon_power_wall.stl
hardware/case/export/coupons/coupon_home_wall.stl
hardware/case/export/coupons/pass16_mount_coupon.stl

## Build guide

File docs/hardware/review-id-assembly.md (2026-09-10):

# Firefly V2 case — industrial design & assembly review

**Reviewer role:** independent ID/assembly review (wearable-electronics enclosure background,
hands-on FDM experience), requested by the coordinator. **Read-only** — no changes made to
`hardware/case/firefly_case.py`, `params_current.py`, `params_trim.py`, exports, or README.
No PR opened.

**Worktree:** `/private/tmp/claude-501/review-id`, created via `git fetch origin` +
`git worktree add /private/tmp/claude-501/review-id origin/main`, HEAD at `51c5d16` (matches
the task's "main at 51c5d16 or later"). The main checkout was never touched.

**Sources reviewed:** `hardware/case/README.md` (passes 9–15b in full — first-print findings
through the USB-tunnel revert), `hardware/case/params_current.py`/`params_trim.py`, the
renders in `hardware/case/renders/` (pass 9g/10/11/12b/13/14/15 close-ups especially),
`hardware/case/SPEC.md`, `docs/hardware/comms-brain.md`, and the coordinator's display-mount
work at `/private/tmp/claude-501/case-analysis/docs/hardware/` (`plate-mounting-analysis.md`,
`plate-mounting-round2.md`, and the `r2-*.png` renders, including `r2-plan-candidate5-ears.png`
— the only artifact documenting Jake's chosen candidate 5, since round2.md's own text only
covers candidates 1–4). Variant discussed throughout: **trim** (56×103.8×28mm, the shipping
default and the one Jake has printed).

**Diagram:** `docs/hardware/review-id-diagram.png` (matplotlib, drawn from the live `PARAMS`
values cited below plus candidate 5's plan drawing) — a top-view overlay of today's screw/post
map against candidate 5's ears+crossbar, with this review's key findings annotated directly on
it.

---

## Summary

The case has clearly been hardened through 15+ iterative passes against real prints — the
README's own discipline (root-cause-before-fix, live Fusion probes, offline STL scans) is
genuinely unusual rigor for a hobbyist enclosure and it shows: manifold geometry, 0 interference,
clean overhangs, both variants, every pass. My review is aimed at the two things that kind of
process doesn't automatically catch: **whether the assembly is pleasant/robust for a human to
build twice under field conditions**, and **whether candidate 5 (the display mount Jake has
already chosen) is actually finished** — it is the least-verified of the five candidates the
coordinator drew, and it has one flagged, unresolved geometry conflict that goes directly to
one of Jake's own questions.

**Top line:** candidate 5 is a good direction (real screw-count and part-count reduction, see
Finding 1) but should not be treated as final — Finding 2 (crossbar vs. battery-plug access) is
a blocker, and Findings 3–4 (no section/interference verification, no plate = no separator
layer) need closing out before it goes to `firefly_case.py`. Independent of candidate 5, the
current shell has one real field-durability gap (Finding 8, button holes on the parting seam)
and several hand-assembly friction points (Findings 5–7, 10) worth fixing before the two pucks
go through repeated open/close cycles at a dusty, rained-on festival.

---

## 1. Assembly

### Finding 1 — Candidate 5 is a real simplification: −3 screws, −1 part [nice]

**Evidence.** Today's fastener count, from the README's own "Screw list" (trim): 5 case-halves
screws (A/B1/B2/C M2×12 + D M2×12) + 4 Screen-Plate posts (P1–P4 M2×6) + 3 display-to-plate
screws (S1–S3 M2×4) = **12 screws**, plus the Screen Plate itself as a separate injection/print
part. Candidate 5's own plan (`r2-plan-candidate5-ears.png`) removes the plate and P1–P4
entirely, splits screw D into **D1 (−19, 64)** and **D2 (19, 64)** at the two ear roots (M2×12
into Bottom, same as today's other case screws), and drives S1/S2/S3 (M2×4) straight up into
the display's own standoffs through the ears/crossbar instead of through a plate. Net: **6 case
screws (A/B1/B2/C/D1/D2) + 3 display screws (S1–S3) = 9 screws, one fewer printed part.**

**Assembly-order effect.** Today's final step is a 4-group screw pass (A/B1/B2/C → D → P1–P4 →
S1–S3, per README pass-9g "Finding 5"). Candidate 5 collapses this to 2 groups: S1–S3 are driven
**early**, while Top is still open (display seats directly against the ears/crossbar, no plate
to fit in between), and the case-halves screws (A/B1/B2/C/D1/D2) are driven once, last. One
fewer discrete fitting step, one fewer part to keep track of/scrap-print.

**Recommendation:** keep this. It's a genuine improvement on both counts the task asked about
(screw count, part count). Update the "Screw list" and assembly-order section accordingly when
candidate 5 lands.

### Finding 2 — Candidate 5's crossbar overlaps the battery-plug clearance window by ~1.7mm, unresolved [BLOCKER]

**Evidence.** `r2-plan-candidate5-ears.png` draws the new crossbar spanning **wall-to-wall at
y 29.0–34.5** (carrying screw S2), directly over the existing battery-plug clearance window
(`x −11.32..−3.67, y 32.8–38.0`, the cutout `BATTERY_CONNECTOR_TOP_EXTRA` pass-15/15b added to
the *plate* specifically so a fingertip/plug isn't pinched — see README pass-15 "Item 2"). The
coordinator's own diagram labels this overlap explicitly: *"battery-plug window overlaps the bar
by ~1.7mm: verify"* — i.e. flagged, not resolved. This is precisely the question the task asks
directly: *"the battery plug (window in the plate today; with no plate, is it free?)"* — **the
honest answer right now is no, or at least unverified**: removing the plate doesn't remove the
access problem, it just relocates the obstruction from a plate cutout to a load-bearing
structural crossbar in roughly the same place.

**Why this matters for assembly, not just geometry:** the battery connector has to be plugged in
by hand, with a body already threaded through the frame's wire notch, in a cavity that by pass-15
Item 2's own account was already "tight" enough that a bare ~2mm sliver of plate there "would
still pinch a fingertip." A crossbar is stiffer and closer to the connector than a thin plate
edge was; if it doesn't clear, this isn't a cosmetic miss, it's a "can't finish building the
puck" defect.

**Recommendation:** before any code lands, re-run the same live point-containment check pass 15
used for the plate's own window (`verify_battery_connector_access`'s pattern) against the actual
crossbar solid — shift the crossbar's y-span north (toward 34.5–40 instead of 29–34.5) or notch
it locally over the connector's own footprint, whichever a live Fusion check shows is cheaper.
Do this before candidate 5 gets implemented, not after — it's cheap to fix in a plan sketch and
expensive to discover during a 6-hour print.

### Finding 3 — Candidate 5 has no section view or live interference sweep, unlike candidates 1–4 [should-fix]

**Evidence.** Candidates 1–4 each got a plan view, two section views, and a Fusion isometric
render (`r2-plan/section/fusion-candidate{1,2,3,4}-*.png`), plus explicit numeric
tolerance/stiffness analysis (rib axial stiffness, ledge engagement gap, etc., round2.md §1).
Candidate 5 has **one plan-view PNG and nothing else** — no section, no isometric, no
stiffness number, no rotation/insertion-path check. It was evidently added after the round-2
write-up closed (its image timestamp is later than the rest of that pass's renders and the
round2.md file itself) and never got the same treatment.

**Recommendation:** before implementing, give candidate 5 the same pass: a sagittal section
through the crossbar and one ear, live Fusion interference check of the ears/crossbar against
the inserted display occurrence (not just the GPS/battery/header boxes the plan view checks by
eye), and a stiffness estimate for the display board spanning ear-to-crossbar unsupported (see
Finding 4) the way round 2 did for candidates 2–4's ribs/ledges.

### Finding 4 — No plate means no separator layer between the display and the comms-bay cavity [should-fix]

**Evidence.** Round 1's own framing (`plate-mounting-analysis.md` §0) lists the Screen Plate's
three jobs: (1) S1–S3 retention, (2) carrying screw D's post, (3) **"physically
separates/locates the display from the comms-bay cavity below."** Candidate 5 answers (1) and
(2) with the ears/crossbar/D1/D2, but drops (3) — there is no continuous barrier between the
display PCB's back side and the GPS-patch/compass/antenna assembly below it any more, only three
point-contacts (2 ears + 1 crossbar). The nearest real numbers on how close things already run
in this neighborhood: the compass-mount clearance above the GPS patch is **2.7mm spare** (README
pass-10 REDO), and the display's own PCBA/shield reaches as low as its measured bbox in the
FPC-relief investigation (pass 15 Item 1). Nothing in the candidate-5 material re-checks display-
underside-to-GPS-patch/compass clearance now that the plate isn't there to enforce a floor.

**Recommendation:** re-verify the compass module's top clearance and the GPS patch antenna's
routing against the display's real underside geometry (not the plate's old footprint) once
candidate 5 is modeled — this was previously guaranteed structurally by the plate's own
thickness; now it needs its own explicit check.

### Finding 5 — Antenna cable routing is a fussy, order-sensitive hand-assembly step [should-fix]

**Evidence.** README Finding 8 (pass 9e) routes the LoRa u.FL cable through a machined channel
just **4.389mm long**, and documents the assembly instruction explicitly: antenna leads must be
routed "as the boards go in, not after" (pass-9g "Finding 5", step 4). `renders/bay_inside.png`
shows just how tight this corner is in practice — the Wio's u.FL connector sits immediately
adjacent to a full-diameter screw boss, in the same dome-tip pocket as the lanyard lug. This is
a two-hands, watch-the-cable-while-you-seat-the-board operation, repeated for 2 pucks and any
field rebuild.

**Recommendation:** no case-geometry change needed (the channels are proven clear by
`verify_antenna_channels`), but the build sheet/README assembly-order list should call this out
as its own numbered sub-step with a literal warning ("dress the LoRa pigtail into its channel
*before* seating the Wio board — there is no way to do it after"), not just a parenthetical.

### Finding 6 — Compass and XIAO-power wiring are hand-soldered, no connector [should-fix]

**Evidence.** `comms-brain.md`'s "Soldering an IDC ribbon directly" section documents 4–5
individually-stripped conductors (RXD, TXD, G, 3V3, optionally BAT) soldered to the puck's 2×10
back header for the comms-brain link, and the compass section adds 4 more solder points (VCC,
GND, SDA, SCL) to the **same** header. The XIAO's own power option (Option A/B/C in that file)
is a third ad hoc wire/pad decision made per-build. None of these is a connector — every one is
a point that must be re-soldered if the case is ever reopened for repair, which for a
festival-fielded prototype with two units is not a hypothetical.

**Recommendation:** for at least the compass's 4 wires, a small in-line connector (JST-SH 4-pin
or similar, already common at this wire gauge) between the module's own short pigtail and the
back-header ribbon would let the case be opened/closed without a soldering iron in the field.
This is a BOM/process change, not a case-geometry change, but it directly affects "does a human
fumble this" for the two real pucks that will be serviced on-site.

### Finding 7 — Button caps "from inside" is correct but leaves zero room for error [nice]

**Evidence.** README pass-9b established (and pass 15's Item 5/6 reconfirmed) that caps must go
in from inside the open Top half, sliding outward until the head seats in the wall hole — an
outside-in insertion is "geometrically impossible by design." This is the right call given the
retention geometry, but it does mean the cap and its tab must be threaded through the guide rib
(now ceiling-anchored per pass 15 Item 5) at exactly the moment Top is otherwise empty and
easiest to see into — do this step before the display/plate go in, not after, or the button
mechanism becomes hard to reach and see around the display's edge.

**Recommendation:** confirm the README's numbered order still lists caps *before* the display
plate step for candidate 5's version of the order (today's pass-9g order lists it as step 3,
after the plate at step 2 — worth double-checking caps-before-plate doesn't create a new
"can't see the rib while seating the cap" problem once the plate is gone and the ceiling gusset
is the display's own nearest neighbor).

---

## 2. Space (Jake's question: 4 screws at the lanyard end, integrate bosses into the sides?)

### Finding 8 — The 4-screw lanyard-end cluster is real and confirmed visually; it was already "integrated into the sides" once (pass 14), which didn't free volume [should-fix]

**Evidence.** `renders/pass14_bottom_logo.png` shows exactly what Jake is describing: 4 screw
heads (A, B1, B2, C) clustered together at the −y (lanyard) end of Bottom's back face, plus 1
isolated screw (D) alone at the +y end — see this review's own diagram
(`review-id-diagram.png`) for the exact xy positions (A −15.5,−8 / B1 −12.5,−15 / B2 12.5,−15 /
C 15.5,−8, all absolute mm, both variants). Jake's own analogy ("like the top ears") already has
a precedent in the repo: **pass 14 merged A+B1 and C+B2 into two wall-anchored "corner blocks"**
per Jake's own sketch ("a buttress block the two screws land in, not two posts with a web") —
this is functionally the same move candidate 5 makes at the other end.

**But it did not free interior volume.** Pass 14's own writeup is explicit:
`CORNER_BLOCK_PAD` ended up at **0.0** — "the capsule/wedge's own radius is just `boss_dia/2`,
the exact footprint the old individual bosses always had" — after an early wider-pad attempt hit
real interference against the inserted board stack (up to 46mm³ against the Wio, 17mm³ against
the XIAO). So the lanyard-end integration that already happened bought **strength and
printability** (one solid mass instead of two thin posts + web, per Jake's own request), not
**space** — the screws still occupy the same 4 points, the same footprint.

**Recommendation on "do we really need 4":** the case's own screw list frames A/B1/B2/C as the
group that "pulls the two halves flush and square" (pass-9g Finding 5, step 8) — this end has no
display glass to protect and no plate to locate, so its job is purely shell compression +
carrying the lanyard's tension load into the shell. Two screws (one per corner block, at the
capsule's own centroid) pulling two already-large buttress blocks flush is a plausible
reduction, mirroring what candidate 5 accepts at the display end (2 screws, D1/D2, replacing 1)
for a similar-sized structure. This needs the same live check pass 14 used (does a
single-fastener corner block still verify clean 0-interference against the real board stack,
and does it hold the parting-line seam flat under the lug's own tension) before cutting the
count — flagged as a worthwhile follow-up study, not a proven-safe change yet.

### Finding 9 — The real freed-volume opportunity for a bigger battery is the plate footprint, not the lanyard bosses [should-fix]

**Evidence.** Round 1's own "(d) Sandwich" analysis (`plate-mounting-analysis.md`) states
plainly: *"Bottom's cavity directly under the plate's own footprint (y 10–70) is largely
empty"* — the battery (`y 2–32`) and GPS patch (`y 2–27`) both stay south of most of the plate,
and the 3-board comms stack (`y −24..−1.5`) is well south of all of it. The only real
obstructions between y=32 and the display end are the battery-plug clearance box and the
header-cutout column (`x 10.5–18, y 42.7–57.1`) — both narrow, localized features, not
wall-to-wall barriers. The lanyard-end screw bosses (A/B1/B2/C, y −8 to −15) sit *south* of the
battery's own start (y=2) — inside the comms-stack's own footprint zone, not competing with the
battery for room at all (see the diagram's overlay).

**Answer to "does a bigger battery fit if the bosses move into the wall": not really, because
the bosses were never in the battery's way.** The battery today (`x −20..20, y 2..32`, 40×30mm
footprint) already uses nearly the full straight-band width (cavity half-width ≈26mm trim,
battery half-width already 20mm). What's actually unclaimed is the **y 32–70ish band under the
display**, which candidate 5's own plate removal opens up structurally for the first time (no
more P1–P4 posts or plate edge to work around) — this is the real lever for a longer/bigger
battery, not the lanyard-end integration Jake asked about specifically.

**Recommendation:** if a bigger battery is actually wanted, evaluate extending the battery
footprint northward (larger y, toward the header cutout) now that candidate 5 removes the plate
that used to occupy that space, rather than expecting the lanyard-end boss consolidation
(Finding 8) to yield meaningful room — it won't, by the numbers above.

---

## 3. Field durability (18–20 Sept, dust/rain/sun/drops)

### Finding 10 — Both button holes sit exactly on the parting seam [should-fix]

**Evidence.** `renders/pass15_buttons.png` and `pass12b_power_button.png` both show the
stadium-shaped button opening straddling the Top/Bottom split line dead center — the parting
line runs directly through the middle of each button hole. Nothing in the README describes a
gasket, boot, or compliant seal at either the case's main seam or the button openings
specifically (the seam's own treatment is a chamfered alignment lip, pass 9 part 2 — a
mechanical registration feature, not a weather seal).

**Why this matters for the brief:** dust and rain are explicit field conditions. A button
opening that spans the seam is a direct, unobstructed path for dust/water ingress right at the
one place two printed halves can never seal as tightly as a single wall (any FDM print's
parting-line fit tolerance is coarser than its bulk wall). This compounds with pass 15 Item 6's
own finding that the Home plunger has **zero spare margin** at rest — a mechanism already living
close to its clearance limits is also the one sitting on the least-sealed opening in the shell.

**Recommendation:** at minimum, a compressible gasket or dab of grease/silicone at each button's
own seam crossing before the festival (field mitigation, no case change needed); as a real fix,
consider whether the button cutout could be biased slightly onto one half only (all-Top or
all-Bottom) in a future pass, removing the seam crossing entirely — flagged here as a design
question for whoever owns the button mechanism next, not attempted in this review.

### Finding 11 — Glass/window bezel sits flush with the flat top plateau, well inboard of the R10 shoulder [OK, noted]

**Evidence.** `renders/pass15_top_window_edge_wide2.png` and the side-profile renders
(`pass15_trim_right.png`, `pass15_trim_front.png`) show the window's chamfered rim sitting level
with the surrounding flat top face, itself set well inside the case's continuous R10 outer
fillet that runs the entire perimeter. On a drop, an edge or corner impact — the statistically
likely orientation for a puck tumbling off a lanyard — lands on that generous, continuous R10
curve, never on the glass rim directly. A dead-flat, face-down 1.5m drop (the less likely
orientation) would put the window rim and the flat plateau's edge at similar risk together,
which is an acceptable, common tradeoff for a round display puck and not something I'd ask to be
redesigned.

**Recommendation:** none — flagging as confirmed-OK since the task specifically asked whether
the bezel is proud or recessed. It reads as flush-with-a-protective-perimeter-shoulder, the
better of the two "wrong" answers.

### Finding 12 — USB-C port and window share the same dome cap; USB faces the same way as the display [nice/noted]

**Evidence.** `renders/pass12b_usb_end.png` shows the USB-C tunnel opening on the same +y dome
cap as the window (`usb_tunnel_y_start`=73.5, close to the window's own +y extent at
`window_center.y + window_dia/2` ≈72.65). Combined with the lanyard lug sitting at the opposite,
−y end (`lug_relief_box` y −29.5..−24.5) and its cord hole running through the case's own Z
(thickness) axis — the standard ID-badge convention — the puck will hang from a neck lanyard
with its long axis roughly vertical and the **display/USB end at the bottom**, swinging ~100mm
below the attachment point.

**Field implication:** a downward-facing USB-C port sheds rain well (good), but is awkward to
charge while worn (minor inconvenience, not a defect) and collects lint/dust from below over a
3-day festival, the same orientation a phone's charging port faces in a pocket. Not a proposed
change — just worth Jake's explicit sign-off that "screen hangs at the bottom, ~4 inches below
the neck" is the intended wearing pose, since it also affects Finding 15 below (hand feel).

### Finding 13 — GPS/compass retention across the 2.7mm spare relies on a hand-placed foam pad, not modeled [should-fix, pre-existing]

**Evidence.** README Known-limitation #28: the compass module is only trapped between the
ceiling pegs/pads and the GPS patch once "a ~2.0mm compressible foam pad is added to the patch's
own top face at assembly time" — explicitly "a real BOM/assembly-order item, not a modeled
part." Combined with a 1.5m drop spec and a component that free-floats vertically until that
foam is correctly placed and compressed, this is worth a physical check (does the foam actually
stay compressed and centered after a drop, or can the module shift enough to lose its two-peg
XY registration under shock) rather than treating pass 10's own "should be fine" as final. Not
a new finding — flagging because it sits squarely in the durability lens the task asked about
and the existing README already names it as unresolved.

**Recommendation:** a drop test specifically targeting this face (compass side down) before the
festival, and/or double-sided foam tape rather than plain compressible foam so the pad can't
migrate off the patch's own top face during handling.

---

## 4. Cosmetics and hand feel

### Finding 14 — Pill silhouette and hand feel are genuinely good [OK, noted]

**Evidence.** `pass15_trim_iso.png`/`pass15_trim_front.png` show a continuous, generous R10
outer fillet with no sharp transitions anywhere on the silhouette — a comfortable, pocketable
shape appropriate for a hand-held/lanyard-worn device. The wordmark deboss (KANDI WOOKS,
`pass14_bottom_logo.png`) reads cleanly with all 4 counters open (a real pass-14 fix, confirmed)
and sits centered on the back face without crowding the screw holes. No changes suggested here.

### Finding 15 — Single-point lanyard lug means the puck hangs long-axis-vertical, screen at the bottom [nice, confirm intent]

**Evidence.** See Finding 12 above. `lug_relief_box` is centered on x=0 (`x: (−8.5, 8.5)`), so
the puck should hang without a left-right tilt (assuming the internal mass — battery, 3-board
stack — is also roughly x-centered, which the params suggest). But being a single attachment
point at the extreme −y tip, ~75mm from the case's own centroid, means the whole 103.8mm length
hangs essentially vertically below the neck, display down, rather than sitting flat against the
chest the way a wide lanyard badge with a centered hole would.

**Recommendation:** confirm with Jake this is the intended wearing pose for a "glance at your
friend-compass" device — if a flatter, more badge-like hang (screen facing up/out at an angle
rather than dangling straight down) is preferred, that's a lug-position or dual-point-lanyard
question, not a case-shell question, and worth deciding before the festival rather than
discovering it on-body on day one.

### Finding 16 — Five exposed screw heads on the back is a real prototype-grade cosmetic tradeoff [nice]

**Evidence.** `pass14_bottom_logo.png` shows all 5 case-halves screws (A/B1/B2/C clustered +D
alone) as visible heads on the same face as the wordmark. For a small-batch, field-tested
prototype this is a reasonable, low-risk choice (visible fasteners are easy to service, cheap to
print, and match the "case as code" prototyping ethos this whole file is built around) — flagged
only as a known cosmetic limitation, not a defect, in case a future finish pass wants
countersunk/flush heads or color-matched screws for a more finished look.

---

## 5. Notes for the other two review lenses (lip chamfer, button-ring printability)

Nothing found in this pass materially contradicts or duplicates those reviews from the ID/
assembly angle, with one cross-cutting note: **Finding 10 (button hole on the parting seam)**
touches the button-ring reviewer's territory directly — the ring's printability and the seam's
weather-sealing are two faces of the same opening, worth comparing notes before either is
"fixed" independently. Nothing observed here bears on the lip's 45° chamfer question beyond what
README pass-9c/15-Item-7 already documents.

---

## Prioritized list

| # | Finding | Severity | Area |
|---|---|---|---|
| 2 | Candidate-5 crossbar overlaps the battery-plug clearance window by ~1.7mm, unresolved | **Blocker** | Assembly / space |
| 10 | Both button holes sit exactly on the parting seam — dust/rain path | Should-fix | Durability |
| 3 | Candidate 5 has no section/interference verification (unlike candidates 1–4) | Should-fix | Assembly |
| 4 | No plate = no separator between display and comms-bay cavity; re-check clearance | Should-fix | Assembly / durability |
| 9 | Real freed-volume opportunity for a bigger battery is the plate footprint (y 32–70), not the lanyard bosses | Should-fix | Space |
| 8 | 4-screw lanyard cluster already wall-integrated (pass 14) but not volume-freeing; 2-screw reduction plausible, unverified | Should-fix | Space |
| 6 | Compass/XIAO wiring is hand-soldered, no connector — field-service friction for 2 pucks | Should-fix | Assembly |
| 5 | Antenna cable routing is order-sensitive and tight; needs an explicit warning in the build sheet | Should-fix | Assembly |
| 13 | GPS/compass foam-pad retention across the drop spec is unmodeled and untested | Should-fix | Durability |
| 7 | Button-cap-from-inside step needs its place in candidate 5's revised order confirmed | Nice | Assembly |
| 15 | Single-point lug → long-axis-vertical hang, screen down — confirm intended wearing pose | Nice | Cosmetics |
| 16 | Five exposed screw heads on the back — acceptable for a prototype, flagged for a future finish pass | Nice | Cosmetics |
| 12 | USB-C and window share the dome cap; USB faces down when worn | Nice | Durability / cosmetics |
| 1 | Candidate 5 cuts screw count 12→9 and removes a part | Positive (nice) | Assembly / space |
| 11 | Window bezel flush with a protective R10 shoulder | Confirmed OK | Durability |
| 14 | Pill silhouette and wordmark read well | Confirmed OK | Cosmetics |

**Bottom line recommendation:** close Finding 2 (blocker) before candidate 5 touches
`firefly_case.py`; do Finding 3's section/interference pass at the same time since it's the
same modeling session. Findings 8/9 together answer Jake's space question honestly: the lanyard
bosses were never blocking a bigger battery, and integrating them further buys strength/
cosmetics, not volume — the real headroom is under the display, which candidate 5 already opens
up by removing the plate. Finding 10 (button seam) is the one durability item I'd fix before the
field test regardless of what happens with candidate 5.

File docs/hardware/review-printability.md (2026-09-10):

# Firefly V2 case — independent printability review

Reviewer: independent FDM/DFM pass (Bambu/Prusa-class, PETG/PLA), read-only.
Repo: `jakeholland/firefly`, reviewed at `origin/main` = `51c5d16` (worktree
`/private/tmp/claude-501/review-print`, `git worktree add` off a fresh
`git fetch`; the main checkout was never touched).

Scope: `hardware/case/README.md` (pass 9 through 15b), `firefly_case.py`,
`params_trim.py`/`params_current.py`, the exported `export/trim/*.stl`
(the shipping variant — Jake's own decision, 2026-09-04) and `export/current/*.stl`,
`tools/offline_stl_check.py`, and the coordinator's "candidate 5" display-mount
proposal. Nothing here was modified — no code, no params, no exports, no README
edits.

**Method.** I ran the repo's own `tools/offline_stl_check.py` against
`export/trim` and `export/current` (both `OVERALL: PASS`, matching the README).
I then wrote independent, pure-Python/NumPy scans directly against the exported
STL bytes (not the README's narrative) — per-triangle overhang-angle
classification, whole-mesh connected-component analysis (island detection),
and targeted ray-casts through named features — because several of Jake's
complaints post-date the passes that claimed to fix related issues, and the
offline scanner's own whitelist boxes are broad enough to hide a regression
inside them. Every numeric claim below comes from one of those scans; the two
saved evidence plots are `docs/hardware/lip_ring_overhang_scan.png` and
`docs/hardware/top_overhang_histogram.png`, referenced inline in blocked area 1.

---

## Findings

### 1. BLOCKER — the alignment-ring seam chamfer (finding 6, pass 9c) is not present in the shipped STL; the ring's actual overhang is a flat 90° shelf, not a small step

**Feature / code:** `add_lip_anchor_reliefs()`, `firefly_case.py:800-861`.
The lip/anchor ring is two stacked stadium rings (`stadium_ring_solid`,
joined into `Top`): `lip_r=(23.95, 25.75)` at `lip_z=(9.2, 10.0)`, `anchor_r=
(23.95, 26.40)` at `anchor_z=(10.0, 11.0)` (trim; `current` is the same shape
2mm further out — `lip_r=(25.95,27.75)`, `anchor_r=(25.95,28.40)`, same
z-band). `PARAMS['lip_ring_seam_chamfer'] = 0.5` (`params_current.py:222-226`)
is meant to bevel the outer step where the anchor (wider, above) overhangs the
lip (narrower, below) via `chamfer_stadium_edge_at()` (`firefly_case.py:1230`),
called at line 853. The README (pass 9c / finding 6, `README.md:1226-1237`)
and the "Known limitations" table (`README.md:4859`, item J6) both say this is
"Fixed" and "confirmed clean by the offline overhang scan."

**Evidence.** I scanned `export/trim/Top.stl` and `export/current/Top.stl` for
any triangle whose face normal has an intermediate (~45°) Z-component in the
exact radial band the chamfer targets (trim: r 25.6–26.5mm, z 9.4–10.6mm;
current: r 27.6–28.5mm, same z-band), across the full 360° of the stadium
(both the straight sides and both domed ends — 240–253 triangles sampled per
variant in that band):

```
trim:    n=240 triangles in chamfer-target band, diag(45°-ish) candidates: 0
current: n=253 triangles in chamfer-target band, diag(45°-ish) candidates: 0
```

Every triangle in that band is either perfectly flat (`nz = ±1.0`, a hard 90°
shelf) or a plain vertical wall (`nz ≈ 0.0`). There is no facet at any
intermediate angle anywhere on the ring's outer step, on either variant. See
`docs/hardware/lip_ring_overhang_scan.png` — a cross-section scatter of every
mesh point in the ring's r/z window, colored by face-normal Z-component; the
three target radii (`lip_r[0]`/`anchor_r[0]`=23.95, `lip_r[1]`=25.75,
`anchor_r[1]`=26.40) are marked, and the flat step is visible as a hard
red→blue transition with nothing at the ±0.5–0.8 (chamfer) color in between.

**Root cause (most likely, not directly provable without the live Fusion
timeline):** `chamfer_stadium_edge_at` is explicitly best-effort — it matches
edges by midpoint radius and silently returns 0 (no assertion) if the match
fails or if `chamferFeatures.add()` raises `RuntimeError` (lines 1265-1268).
Passes after 9c (the pass-9 per-boss reliefs, the pass-9 stack3 keepout cut,
and pass 15's post/boss relayout) all cut additional notches through this
same ring at boss/keepout locations, fragmenting its once-clean 4-arc outer
edge loop into many disjoint arcs. A multi-edge chamfer selection like that is
a plausible `RuntimeError` case in Fusion's chamfer feature. Since nothing in
`verify()` checks that the chamfer *actually landed* (only that the ring
itself has 0 non-manifold edges and 0 bad overhang **clusters**, and this
region falls inside the very wide `general_ceiling_overhang` whitelist box in
`tools/offline_stl_check.py`, `y ∈ [-16,79]`, `x ∈ [-32,32]` — nearly the
whole underside of Top), a silent no-op here would never have tripped any
gate.

**What this means for Jake's print:** this is very likely the "lip on the
top case for the alignment ring" he is describing. It sits right at the
Top/Bottom parting line (z 9.2–11 is only just above `split_z=10.0`) and is
the shelf the display module's PCB registers against — a rough,
support-scarred surface here risks both a poor Top/Bottom mating line and a
tilted display seat, not just cosmetics.

**Recommended fix.** Two things, not one:
1. **Restore the chamfer, defensively.** Change `chamfer_stadium_edge_at`'s
   caller to assert (or at least log loudly) when `found == 0`, so a future
   regression like this can't happen silently again — the existing
   best-effort/no-assert pattern is appropriate for a purely cosmetic fillet,
   but this one is print-load-bearing.
2. **The 0.5mm step chamfer was never enough anyway.** Even when it worked,
   it only bevels the 0.65mm-wide *outer* step (`anchor_r[1]-lip_r[1]`); the
   ring's own flat *top* face at `anchor_z[1]=11.0` (from r=23.95 out to
   r≈26.40, i.e. the actual seat the display's PCB rests on) is a completely
   flat, 0°-from-horizontal shelf with no chamfer treatment at all — a
   textbook full support-needed overhang, confirmed directly: every triangle
   I sampled at `z=11.0` in that radius band reads `nz=+1.000` (dead flat).
   Reprofile the ring the same way pass 15's window-bore fix already proved
   out (§4 below, `add_window`'s `cone_frustum_solid` cut, slope
   deliberately just under 45° from vertical): instead of two flat-topped
   stacked cylinders, taper the ring's outer wall continuously from
   `lip_r[1]` at `lip_z[0]` up to `anchor_r[1]` at `anchor_z[1]` as a single
   45°-max cone frustum. The available rise (1.8mm total, `lip_z[0]` to
   `anchor_z[1]`) only buys ~1.8mm of radial growth at a true 45° slope,
   short of the needed 2.45mm (`anchor_r[1]-lip_r[0]`) — so either keep a
   small (~0.5-1mm wide) flat registration land near the bore-facing inner
   edge (where the display actually needs a true flat seat) and taper only
   the *outer* portion back to the shell at ≤45°, or accept a slightly
   steeper-than-45°-but-still-better-than-90° taper there (PETG commonly
   tolerates up to ~55-60° from vertical on a short run before visible
   sagging) rather than the current hard corner.

**Severity: blocker** — it is the literal feature Jake asked to have fixed,
the "fix" already merged is not actually present in the geometry being
shipped, and it sits on a fit-critical surface (display seat / parting line).

---

### 2. SHOULD-FIX — button guide-rib/collar tips still present small unsupported ledges, and the rib's ceiling-gusset region sits inside a hard-to-clear channel

**Feature / code:** `button_geometry()` (`firefly_case.py:2209-2400`),
`add_button()`'s rib plate / tab-relief lane (`firefly_case.py:2535-2650`),
the pass-15 ceiling gusset (`firefly_case.py:2713-2737`, `README.md:4129-4168`,
item 5).

**Background (already fixed, verified structurally sound).** Pass 15 item 5
correctly diagnosed that the guide rib + wall connector used to hang
completely unattached to the ceiling ("floating," Jake's word) — a genuinely
unsupportable internal island deep in a cavity that only opens through a
~14×24mm hole. The fix ties the rib to `top_ceiling_underside_z` via a
diagonal gusset anchored at the wall-connector's outboard end (clear of the
display board's own footprint, learned the hard way from a first attempt that
hit a real interference). I independently re-verified this is not just
"interference-clean" but **actually one connected solid**: a whole-mesh
connected-component pass over `export/trim/Top.stl` (12,524 triangles) finds
**exactly 1 component** — no disconnected/floating geometry anywhere in Top,
buttons included. Good: the gusset genuinely closes the "floating rib" defect
and the mechanism can print without a completely separate, hard-to-reach
internal support tower.

**What's still rough, evidenced directly:** scanning triangles in the button
housing footprints (`x ∈ [-19,-10]`, `y ∈ [34,45]` for Power, `[55,66]` for
Home; `z 8–22`, i.e. below the general dome ceiling) turns up local overhangs
the general scan's clustering hides:

```
Home button, z 15.6–17.0 (near the guide rib's own chamfered lead-in / plunger tip):
  x=-17.71 y=64.83 z=16.31  nz=0.967  (~75° "up" -> steep downward-facing overhang once printed flipped)
  x=-17.38 y=65.35 z=16.55  nz=0.903  (~65°)
  x=-17.62 y=65.95 z=16.78  nz=0.808  (~54°)
  ... (area ~0.5mm^2 each, several of them)
Home button, z 23.8-27.0 (the rib/gusset's own attach region under the ceiling):
  x=-18.30 y=64.72 z=23.80  nz=1.000  area=8.43mm^2  (flat, 0deg)
  x=-18.35 y=65.84 z=27.02  nz=0.709  area=3.49mm^2  (~45deg, this one is fine)
```

None of these are individually above `offline_stl_check.py`'s 30mm² cluster
threshold, and they fall inside the same `general_ceiling_overhang` whitelist
box as everything else near the dome end, so the existing tooling reports
"clean" here too. The `8.43mm²` flat patch sits right where the ceiling
gusset attaches, and the ~54-75° facets sit right at the guide rib's own
lead-in — both are exactly the kind of thing that needs a slicer support
touch **inside the button housing's own narrow channel** (the same
"open" the coupon-fit instructions describe as ~9.6×24×18.6mm — barely
finger-width), not out on the open dome ceiling where support is trivial to
place and pull. Support debris or a snapped-off support nub in this channel
is a real risk to the guide rib itself (a thin printed feature that the
switch's own actuation force already loads, per pass 15 item 6's plunger
analysis).

**Recommended fix:** add small 45° lead-in chamfers on (a) the guide rib's
own inboard edge where it meets the plunger-tip pocket, and (b) the ceiling
gusset's own attach face, so that the small residual overhangs above shrink
toward self-supporting rather than needing supports specifically inside the
housing. If any support is still needed there, note it explicitly in the
print-orientation instructions (the current README only says "check the lug
and USB liner overhangs on your slicer" — the button-housing ceiling
attachment deserves the same call-out).

**Severity: should-fix** — small area, not a blocker, but it is inside the
one feature Jake specifically flagged ("alignment rings for the buttons have
printability issues") and it's the hardest place in the whole case to clear
support from.

---

### 3. VERIFIED GOOD — the window bore fix (pass 15 item 7) is real and effective in the shipped STL

**Feature / code:** `add_window()`, `firefly_case.py:946-1030`.
`window_dia=45.30`, `window_center=(0,50)`, `window_chamfer=0.5`. The pass-15
fix replaced an edge-matched chamfer (which silently left ~30° gaps at the
±X extremes because `window_dia/2=22.65mm` sits past trim's `flat_rho=
22.14mm`, into the curved shoulder) with a `cone_frustum_solid` boolean
**cut**, geometry-independent of whether the local surface is flat or curved.
Cone: `r` grows `chamf+0.2=0.7mm` over `z`-span `chamf+0.6=1.1mm` —
`atan(0.7/1.1) = 32.5°` from vertical, comfortably under the 45° ceiling
with margin, exactly as the code comment claims.

**Independent confirmation, done two ways, both clean:**
- A pure ray-cast point-containment check against the actual exported
  `export/trim/Top.stl` at the cone's own mid-slope radius/z, sampled every
  10° around the full 360°: **0/36 angles read solid** (all hollow, as
  required — the old defect specifically showed up at the ±X extremes, both
  of which are included in this sweep).
- The same check on the ring/window rim generally: no residual flat notch or
  gap anywhere in the sampled ring.

This matches the README's own live-build probe and its "independent
pure-Python ray-cast" claim — unlike finding 1, this one really is fixed in
the shipped geometry. No action needed; it's a good template for finding 1's
recommended fix (§1) and for candidate 5 (§6).

---

### 4. VERIFIED GOOD — Bottom's screw-hole "replug" (pass 15 item 8) is also genuinely fixed

**Feature / code:** `add_case_boss()` / `add_root_reinforcement()`
(`firefly_case.py:1397`ff). Pass 13's 45°-collar reinforcement is a solid
revolve that (pre-fix) silently replugged the pilot hole/counterbore over its
own z-band on every *Bottom*-side boss. Ray-casting straight down through
`export/trim/Bottom.stl` at all five boss centers (A(-15.5,-8), B1(-12.5,-15),
B2(12.5,-15), C(15.5,-8), D(0,60)) finds **0 triangle crossings at every one**
— i.e. the ray never touches solid material at any of the five pilot axes,
confirming all five are genuinely open through-holes in the shipped STL, not
just in the historical live-Fusion probe the README quotes. No action needed.

---

### 5. NICE-TO-HAVE — general ceiling overhang is large but expected; mesh integrity is otherwise clean

- Whole-mesh connected-component check: `Top` (12,524 triangles) and
  `Bottom` (9,862 triangles) each resolve to **exactly 1 connected
  component**, 0 non-manifold edges (matches `offline_stl_check.py`). No
  floating islands anywhere in either body.
- An area-weighted overhang-angle histogram of `Top` restricted to
  triangles *outside* the broad `general_ceiling_overhang` whitelist box
  still finds ~165mm² total of >46°-flagged area, but every individual
  cluster is well under 1mm² (see `docs/hardware/top_overhang_histogram.png`)
  — small ribs/pegs near the south (L76K/compass) end, not worth chasing
  individually.
- The large (~488mm²) flat interior-ceiling overhang the whitelist already
  accepts is real and will need ordinary slicer support (tree/organic) —
  that's normal and unavoidable for a hollow dome printed face-down, and the
  cavity is wide open for support removal before Bottom/the display go in.
  No design change recommended here; just make sure the slicer's support
  density/interface settings are tuned for PETG release, since the display
  seats directly under part of this ceiling.

---

## 6. Candidate 5 (display mount: two ears + S2 crossbar, no plate) — printability guidance before it's built

Proposal under review: two ears grown from Top's dome wall at S1 `(-12, 65)`
and S3 `(11.6, 65.46)`, and a crossbar "wall-to-wall" at the S2 line
(`board_standoffs['S2'] = (0.04, 32.22)`, `params_current.py:393-395`, y
band ≈29–34.5), all at z 15.5–18.5, printed as part of Top face-down. Ceiling
reference numbers (trim): `top_ceiling_underside_z = 26.0`, display board
`display_pcb.z = (20.59, 21.81)`, display bbox `z = (23.3, 28.0)`, inner
fillet `R = 8.0` (transitions from the vertical cavity wall into the flat
ceiling somewhere around z≈24–26, by direct analogy to the whitelist's own
"z~21-23 at ~40°" note for `current`, shifted +3 for trim).

**S1/S3 ears — should print clean with a short local gusset.** These grow
directly from the dome wall at y≈65 (near the case's own +y tip, past
`spine_b`), so the unsupported reach is only wall→standoff, not a
cavity-spanning bridge. Recommendation:
- Give each ear's underside (in CAD, its `+Z`-facing top, which becomes the
  downward face once Top prints flipped) a 45°-max chamfer back to the wall,
  exactly the `cone_frustum_solid` idiom already proven at the window bore
  (§3) and the root-reinforcement collars (`ROOT_FILLET_R=1.8`,
  `ROOT_COLLAR_RISE=1.5`, `firefly_case.py:1338-1339`) — don't hand-roll a
  new chamfer helper, reuse `cone_frustum_solid` as a join, same call
  signature.
- Watch the same defect class pass 15 item 8 found: if a reinforcement
  collar is joined in *after* the standoff's own pilot hole is cut, re-cut
  the hole afterward (`add_case_boss`'s fix) — collars are solid revolves
  that will replug a hole passing through their own z-band.
- Expected tolerance: a short (<10mm), wall-anchored, chamfered cantilever
  like this should hold to roughly the same **±0.15–0.3mm** the rest of the
  case's posts/bosses already work to (the file's own repeated
  "flat-ray-vs-true-curvature" slack budget). No bridging is involved, so
  layer-to-layer consistency should be good.

**S2 crossbar — do not plan on this being support-free at 52mm.** This is
the one place candidate 5 needs a real design change, not just a chamfer,
and it's worth flagging before it's modeled:
- S2 sits at `x≈0.04`, i.e. dead-centered under the display board
  (`display_bbox.x = [-22.39, 22.39]`) — the same board pass 15 item 5's
  button-gusset dead-end hit (a real 14.28mm³ interference) when it tried to
  run a gusset straight up toward the ceiling under this same footprint. A
  45° gusset from the S2 crossbar (z 15.5–18.5) up to the R8 fillet/ceiling
  (z≈24–26) would have to pass directly through `display_pcb`'s own z-band
  (20.59–21.81) at essentially the same XY — there is no lateral dodge
  available here the way item 5 found for the button (which could shift
  outboard to `s_wall`, clear of the display). **Any straight-up gusset at
  S2 is a probable board interference, not just a printability nuisance** —
  this needs its own `check_interference` gate against the display
  occurrence before it's trusted, the same way item 5 was caught.
- Height budget for *any* self-supporting slope at S2 is thin regardless:
  crossbar top (18.5) to fillet start (≈24) is only ~5.5mm of rise, giving
  ~5.5mm of horizontal reach at a true 45° — nowhere near enough to span the
  ~52mm wall-to-wall run (inner cavity half-width ≈ `outer_radius - wall` =
  26mm each side in the straight section) with periodic gussets without
  either (a) a large number of them (≈8–10 pairs at ~5-6mm spacing, cluttering
  the cavity and multiplying the interference risk above), or (b) accepting
  unsupported bridge segments well past typical clean-bridging length
  (∼5–10mm is comfortable for PETG with good part cooling; 15-25mm needs
  tuning and will show visible sag; 52mm flat and unsupported will sag
  significantly and likely fail to print a usable flat seat at all).
- **Recommendation:** don't model S2 as one continuous flat wall-to-wall
  beam. Either (a) treat S2 like S1/S3 — a short local boss cantilevered in
  from whichever wall is closer, accepting it won't be a continuous
  stiffening bar, or (b) if a continuous bar is wanted for rigidity, design
  it expecting **minimal, deliberate slicer support**: the cavity is wide
  open at this stage of the print (nothing built yet at z<18.5 in that area
  besides the ears/side walls) so a couple of easily-reached, easily-removed
  drop supports from the bed up to the bar's underside are cheap here —
  unlike the button housings (§2), there is no narrow channel trapping them.
  Keep any support landing spots off the S2 screw seat's own local pad
  (chamfer that pad's edges at 45° so it's self-supporting for a few mm
  around the hole itself, even if the rest of the bar needs help), and off
  the ear-to-crossbar interfaces. If you go this route, add the interference
  gate against the display board mentioned above regardless of whether
  supports or gussets end up doing the work.
- **Tolerance to expect:** if the crossbar is left as an unsupported flat
  bridge, expect sag on the order of several tenths of a millimeter up to
  ~1mm at midspan (52mm is well past comfortable PETG bridging) — not
  acceptable for a screw seat. If printed with minimal slicer support (or
  redesigned as short local bosses per the recommendation), expect it can
  return to the case's usual **±0.15–0.3mm** working tolerance, same as
  S1/S3 and the other posts — but verify this with a coupon print (the same
  idiom the button caps already use, `export/coupons/`) before committing a
  full Top print, since this is new, unvalidated geometry.

---

## Prioritised list

1. **[Blocker]** Restore/replace the lip/anchor alignment-ring chamfer
   (`add_lip_anchor_reliefs`, `firefly_case.py:800-861`) — confirmed absent
   from `export/{trim,current}/Top.stl` despite README pass 9c claiming it
   fixed; the ring's flat `z=anchor_z[1]` top shelf also needs its own
   self-supporting profile, not just the outer step. See §1.
2. **[Should-fix]** Before modeling candidate 5's S2 crossbar as a literal
   wall-to-wall beam, add a `check_interference` gate against the display
   PCB for any gusset/support reaching toward the ceiling under its
   footprint, and replan S2 as short local bosses or a beam that
   deliberately expects minimal slicer support rather than 45°-only
   self-support (the height/interference budget doesn't allow full
   support-free at this span). See §6.
3. **[Should-fix]** Chamfer the button guide-rib's lead-in edge and the
   ceiling-gusset attach face (~54-75° facets and one flat 8.4mm² patch
   found inside the Home button housing) so slicer support isn't needed
   inside the narrow, hard-to-clear button channel. See §2.
4. **[Nice]** Add a loud assertion (not silent no-op) to
   `chamfer_stadium_edge_at` when its edge match count is 0, so a future
   regression like finding 1 can't hide behind the broad
   `general_ceiling_overhang` whitelist again.
5. **[Nice]** S1/S3 ears in candidate 5: reuse `cone_frustum_solid` for a
   45° root chamfer (same idiom as the window bore and the existing
   root-reinforcement collars) and re-cut any standoff pilot hole after
   joining a collar, per the pass-15-item-8 gotcha. See §6.
6. No action needed: window bore fix (§3) and Bottom screw-hole fix (§4)
   are both genuinely present and correct in the shipped STLs; general dome
   ceiling overhang (§5) is normal and already handled by ordinary slicer
   supports.

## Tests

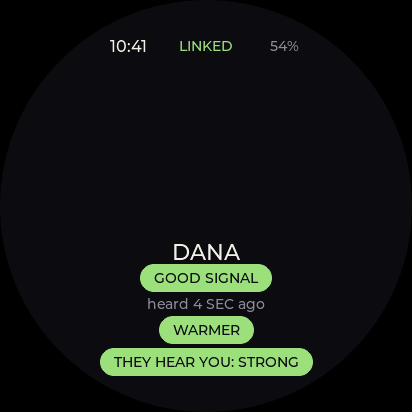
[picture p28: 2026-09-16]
firmware/tests/golden/radar_find_active.png

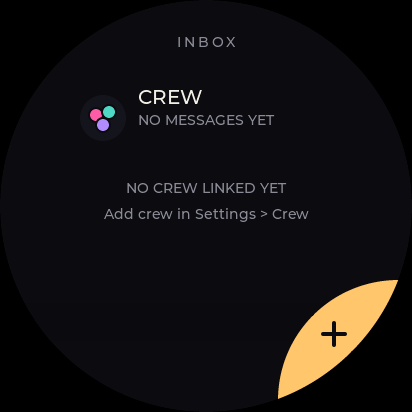
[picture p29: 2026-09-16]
firmware/tests/golden/inbox_no_crew.png

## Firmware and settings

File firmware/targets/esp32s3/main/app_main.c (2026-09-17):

/**
 * app_main.c — ESP32-S3 target entry point (S15 slice b — display + touch).
 *
 * Slice a booted ff_shell against three stub HALs with the screen dark.
 * Slice b keeps that boot EXACTLY (same clock stub, same no-op store, same
 * no-transport shell) and adds the real display + touch HAL on top, staged
 * so the maintainer can flash one gate at a time and watch the glass:
 *
 *   STAGE 1 (first light): expander up -> release resets -> backlight ->
 *            SPD2010 QSPI panel init -> a solid fill + two-colour split via
 *            esp_lcd_panel_draw_bitmap. NO LVGL. Proves the panel path.
 *   STAGE 2 (app on glass): + LVGL v9 via esp_lvgl_port, render one real
 *            ff_shell face (Radar, no selection) — the same projection the
 *            sim renders for that state.
 *   STAGE 3 (touch drives it): + SPD2010 touch -> an LVGL pointer indev
 *            wired to the SAME abstract input seam the sim ctl socket
 *            drives (ff_intent_emit -> ff_shell_intent_sink). A physical
 *            tap/swipe changes shell state. The stored touch calibration
 *            (if any) is loaded from ff_settings and applied.
 *   STAGE 4 (calibrate touch, S15d): + the crosshair capture flow — tap 5
 *            targets -> ff_touchcal_solve -> store to ff_settings -> apply
 *            LIVE and continue straight into the normal UI in the same
 *            boot (no reflash to feel the correction). Params + pairs are
 *            logged. See docs/specs/S15d-touch-calibration.md.
 *
 * The stage is chosen by CONFIG_FF_BRINGUP_STAGE (menuconfig ->
 * "Firefly bring-up", default 1). core/ and app/ are UNCHANGED; every new
 * line is under targets/esp32s3/. Every init step logs so a dark screen
 * still says how far it got.
 *
 * The clock / store / no-transport rationale is unchanged from slice a —
 * see the git history of this file / the S15a PR body. NVS store and UART
 * transport remain later slices (c/d/e).
 */
#include <inttypes.h> /* PRIu32 — the I2C/watchdog/perf health lines below */
#include <stdbool.h>
#include <stddef.h>
#include <stdio.h> /* S26 slice f — snprintf, ff_wakeup_cause_str's fallback branch */
#include <string.h>

#include "driver/gpio.h" /* S26 slice f — GPIO wake source config (touch-INT/PWR/BOOT) for light sleep */
#include "driver/usb_serial_jtag.h" /* S26 slice f amendment — usb_serial_jtag_is_connected(), sleep-inhibit sample */
#include "esp_core_dump.h" /* S25 latch-hold amendment — crash evidence: image_check/get_summary/get_panic_reason/erase */
#include "esp_err.h" /* esp_err_to_name() — S26 slice g's boot-splash failure log */
#include "esp_log.h"
#include "esp_random.h" /* fix/meshclient-packet-id-seed — esp_random() for the outgoing packet-id seed */
/* A02 slice D2 — `esp_random()` behind ff_shell_set_random's `(void*)`
 * context signature. A one-line adapter rather than a cast of the
 * function pointer itself: calling through an incompatible pointer type
 * is undefined behaviour, and this is the kind of place it would never
 * be noticed. */
#include "esp_sleep.h"  /* S26 slice f — esp_light_sleep_start() + wake-source config */
#include "esp_system.h" /* esp_restart() — S26 slice b's reboot action */
#include "esp_task_wdt.h" /* 2026-09-08 QA hardening — render-loop task + LVGL-liveness watchdog coverage */
#include "esp_timer.h"
#include "freertos/FreeRTOS.h"
#include "freertos/task.h"

#include "ff_audio.h"      /* S27 sounds (device half) — the PCM5101 I2S tone-synth HAL */
#include "ff_button.h"     /* S26 slice e — core: the generic debounced push-button (BOOT-as-home) */
#include "ff_compass.h"    /* S15 — GY-273 magnetometer + onboard QMI8658 tilt, feeding ff_shell_set_heading */
#include "ff_display.h"
#include "ff_face.h"
#include "ff_face_dispatch.h" /* fix/flare-cancel-taps — ff_face_dispatch_tick, the non-rebuild per-frame widget refresh */
#include "ff_gesture_glue.h" /* S28 slice b — on-glass BACK/HOME/long-press-flare */
#include "ff_idle.h"       /* S26 slices c+f — core: inactivity -> dim -> screen off -> light sleep */
#include "ff_intent.h"
#include "ff_base64.h"     /* 2026-09-09 amendment — pure base64 encoder, `mic dump <secs>` */
#include "ff_mic.h"        /* S30 — onboard I2S1 mic HAL */
#include "ff_nvs_store.h" /* S21 §4 — the real NVS-backed store */
#include "ff_power.h"      /* S25 — battery keep-alive latch (must fire first) + S26b PWR/BOOT sampling */
#include "ff_power_fsm.h"  /* S26 slice b — core: the press-timing FSM + reboot BOOT-release guard */
#include "ff_session_log.h" /* S25 latch-hold amendment — NVS heartbeat + clean_shutdown flag */
#include "ff_settings.h"
#include "ff_shell.h"
#include "ff_sound_emit.h" /* S27 sounds — the screens-level TAP seam (ff_shell_sound_sink's bind target) */
#include "ff_ticks_at_least_one.h" /* fix/mic-dump-device-path — the pure calc behind ff_ticks_at_least_one() below */
#include "ff_touchcal.h"
#include "scr_music.h" /* 2026-09-09 S31 canvas renderer — ff_scr_music_debug_frame_stats, the `music` console hook */

#if CONFIG_FF_DEBUG_CONSOLE
#include "ff_dbgcmd.h"        /* FF_DBGCMD_LINE_MAX — the line-accumulator bound below */
#include "ff_debug_console.h" /* bench/debug console dispatch — docs/hardware/comms-brain.md */
#endif

/* debt/S15c-handshake-stall — MC_HANDSHAKE_TIMEOUT_MS/MC_HANDSHAKE_MAX_RETRIES
 * for the retry log line below. Unconditional (unlike mc_transport_uart.h):
 * the retry counter is read on every target, and ff_meshclient is already a
 * REQUIRES of this component either way. */
#include "mc_client.h"

#if CONFIG_FF_LINK_UART
#include "mc_transport_uart.h" /* S15c — the real mesh transport, comms brain over GPIO43/44 */
#endif

#include "esp_heap_caps.h" /* PSRAM allocs: shell + demo/field festpack */
#if CONFIG_FF_DEMO_MODE /* S20 — the festpack is allocated in PSRAM (see s_demo_pack) */
#include "ff_demo.h"       /* S20 — demo-mode seeding */
#if CONFIG_FF_DEMO_LIVE
#include "ff_demoapply.h" /* S23c — apply an emitted event through the real inbound seam */
#include "ff_demofeed.h"  /* S23a — the deterministic synthetic event generator */
#endif
#endif

/* S05 field festpack and S20 demo mode are mutually exclusive: a live
 * field build never also seeds the fictional demo world. Kconfig's
 * `depends on !FF_DEMO_MODE` on FF_FIELD_PACK already prevents this
 * through menuconfig; this is the compile-time backstop against a
 * hand-edited sdkconfig setting both directly. */
#if CONFIG_FF_DEMO_MODE && CONFIG_FF_FIELD_PACK
#error "CONFIG_FF_DEMO_MODE and CONFIG_FF_FIELD_PACK are mutually exclusive — pick one"
#endif

static const char *TAG = "firefly";

/* fix/mic-dump-device-path — `pdMS_TO_TICKS(ms)` truncates toward zero,
 * so any caller-supplied millisecond period shorter than one tick period
 * (10ms on this build: CONFIG_FREERTOS_HZ=100 — see
 * firmware/targets/esp32s3/sdkconfig) silently computes to 0 ticks.
 * `vTaskDelay(0)` is a bare task-yield, not a sleep: a polling loop built
 * on it never actually waits, so whatever "elapsed time" budget it is
 * nominally advancing by `ms` each iteration burns down in near-zero
 * wall-clock time instead of over `ms`-per-loop real time. That is
 * exactly what happened to `mic dump`'s FF_MIC_DUMP_POLL_MS=5 poll (its
 * 1000ms no-data budget elapsed in ~10ms of real time — see
 * docs/specs/S30-audio-input.md, "mic dump device notes") and is the
 * same bug class PR #216 fixed for the i2c bus-scan's 5ms retry. Every
 * polling/backoff sleep in this file goes through this helper instead
 * of a bare `vTaskDelay(pdMS_TO_TICKS(ms))` (or a bare
 * `pdMS_TO_TICKS(ms)` timeout on a blocking driver call) so a period
 * dropped below one tick later — a Kconfig edit, a constant tuned down —
 * degrades to "sleeps one tick, still correct" rather than silently
 * spinning.
 *
 * The actual arithmetic is `ff_ticks_at_least_one_calc`
 * (ff_ticks_at_least_one.h), a header with zero FreeRTOS includes kept
 * host-testable — see that header's own doc comment and
 * tests/test_ticks_at_least_one.c for the coverage `pdMS_TO_TICKS`'s own
 * tick-rounding can't be exercised on the sim/host build otherwise.
 * This wrapper only supplies the live `configTICK_RATE_HZ` and narrows
 * back to `TickType_t`. */
static inline TickType_t ff_ticks_at_least_one(uint32_t ms)
{
    return (TickType_t)ff_ticks_at_least_one_calc(ms, (uint32_t)configTICK_RATE_HZ);
}

/* A02 slice D2 — see the note beside the esp_random.h include above. */
static uint32_t ff_esp_random32(void *ctx)
{
    (void)ctx;
    return esp_random();
}

#if !CONFIG_FF_DEMO_MODE
/* ff_clock_t — monotonic ms over esp_timer_get_time() (see slice a).
 * Compiled out under CONFIG_FF_DEMO_MODE, which drives a frozen demo clock
 * instead (below) and never reads real time. */
static uint32_t ff_esp_clock_now_ms(void *user)
{
    (void)user;
    return (uint32_t)(esp_timer_get_time() / 1000);
}
#endif

#if CONFIG_FF_DEMO_MODE
/* S20 demo mode pins the shell's clock at a fixed instant (Sat 21:30) so
 * the seeded world stays frozen and honest — freshness/countdowns read the
 * seeded moment rather than drifting with real boot time. ff_demo_seed sets
 * this counter; both the injected ff_clock_t AND every ff_shell_tick read
 * it (see ff_bringup_now_ms), so the projection ages against the same
 * clock the seed used. The demo festpack is EMBED_FILES'd (main/CMakeLists). */
static uint32_t s_demo_clock_ms;
/* The parsed festpack is ~23 KB. It lives in PSRAM, not internal .bss: internal
 * RAM is scarce and must be left for LVGL's DMA strip buffers, and only the demo
 * build allocates it at all. Populated by ff_demo_seed via the shell's cfg.pack. */
static fp_pack_t *s_demo_pack;
/* S26 slice (a) — the jsmn token scratch fp_parse tokenizes into while
 * parsing the demo festpack above. FP_MAX_TOKENS * sizeof(jsmntok_t) is
 * 256KB (16384 tokens since 2026-09-16, was 128KB): PSRAM, never internal DIRAM — reclaiming THAT is the whole point
 * of this slice (docs/specs/S26-device-lifecycle.md). Intentionally
 * NEVER FREED: ff_shell_cfg_t.toks is stored by the shell and reused by
 * every ff_shell_load_pack call for the shell's whole lifetime (same
 * contract as cfg.pack/s_demo_pack above), not just the one boot-time
 * demo parse — ff_shell_load_pack is the shell's real production
 * pack-load path (already used off-device by the sim's --pack/--connect
 * flow), so a future on-device reload would parse into freed memory if
 * this were freed after ff_demo_seed. 256KB out of 8MB PSRAM is a
 * trade worth making to keep that pointer valid for as long as the
 * shell might call ff_shell_load_pack again. */
static jsmntok_t *s_demo_toks;
extern const uint8_t firefly_pack_start[] asm("_binary_firefly_fields_festpack_json_start");
extern const uint8_t firefly_pack_end[] asm("_binary_firefly_fields_festpack_json_end");

/* S24d — the demo LOOPBACK sender. The demo build has no mesh transport, so
 * the real mc_send_* path refuses every send; this accepts them (returns 0)
 * so the shell pushes the OUT feed item and the user's own outbound shows in
 * the thread. Kept INSIDE this CONFIG_FF_DEMO_MODE block precisely so a field
 * build never compiles it (see the install site + ff_demo.h note). It echoes
 * the user's REAL outbound and reaches no radio; it fabricates nothing. */
static int demo_loopback_send_text(void *ctx, uint32_t dest, const char *utf8, uint32_t *out_packet_id)
{
    (void)ctx;
    (void)dest;
    (void)utf8;
    /* Demo mode has no real mesh transport to hand out a routing-ack-
     * correlated packet id from, but it must still populate a nonzero
     * one on this "successful send" (0 return) — an outbox delivery
     * status feature caller (shell_send_or_queue_text, ff_shell.c) reads
     * packet_id == 0 as "no packet id was ever formed" (ff_feed.h). A
     * demo-mode direct text is marked SENT immediately and never
     * receives an ack either way (no radio to reply), so any nonzero
     * placeholder is harmless. */
    if (out_packet_id != NULL) *out_packet_id = 1u;
    return 0;
}
static int demo_loopback_send_private(void *ctx, uint32_t dest, const uint8_t *payload, size_t len, uint32_t flags)
{
    (void)ctx;
    (void)dest;
    (void)payload;
    (void)len;
    (void)flags; /* no real transport in demo mode — nothing to request an ack from */
    return 0;
}
static ff_wiring_sender_t ff_demo_loopback_sender(void)
{
    ff_wiring_sender_t s;
    memset(&s, 0, sizeof(s)); /* demo mode pushes no mesh owner update — send_admin_set_owner/
                                * send_get_owner_request stay NULL, same as any other unbound
                                * sender field (ff_wiring_sender_t's own doc comment) */
    s.send_text = demo_loopback_send_text;
    s.send_private = demo_loopback_send_private;
    return s;
}

#if CONFIG_FF_DEMO_LIVE
/* S23 (slice b) — LIVE demo clock. When live, the demo clock ADVANCES from
 * the seeded epoch (s_demo_clock_ms, pinned by ff_demo_seed) by real
 * esp_timer elapsed, so ages tick and the ff_demofeed schedule fires.
 * s_demo_epoch_us is esp_timer's value latched the instant live mode
 * STARTS — deliberately AFTER ff_demo_seed returns, so seeding itself runs
 * against the frozen epoch (MAYA's 25-min-old fix etc. age honestly against
 * the seeded wall, exactly as S20). Until then s_demo_live_started is false
 * and the clock reads the frozen epoch. */
static int64_t s_demo_epoch_us;
static bool s_demo_live_started;

static void ff_demo_live_start(void)
{
    s_demo_epoch_us = esp_timer_get_time();
    s_demo_live_started = true;
}
#endif
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
void app_main(void)
{
    /* S25 — latch battery power ON before anything else. On battery the board
     * only stays alive while PWR is physically held; this drives the SYS_EN
     * hold line high so it survives the button release. Must beat the display
     * bring-up's reset delays, hence the very first line. Non-fatal on failure
     * (USB boots run regardless; battery was going to drop either way, and a
     * live-but-unlatched puck is more debuggable than a park loop).
     *
     * S26g AC1: this call stays app_main's first statement — nothing above
     * it, nothing inserted before it by this slice. The timestamp logged
     * right after is read together with ff_display's own "S26g AC1: first
     * splash pixel" log (targets/esp32s3/components/ff_display/ff_display.c)
     * so the maintainer can confirm the order (latch, then splash pixel,
     * never the reverse) straight off the serial log. */
    (void)ff_power_latch_on();
    ESP_LOGI(TAG, "S26g AC1: latch requested at t=%lld us (app_main's first statement)",
             (long long)esp_timer_get_time());

    /* S25 slice c — bring up the battery-sense ADC right after the latch.
     * Order matters only relative to the latch (which must stay first);
     * nothing else in this boot depends on the battery ADC being up
     * before it runs, so this sits here rather than deeper in bring-up.
     * Non-fatal on failure (same posture as the latch call just above,
     * and every other HAL bring-up step in this file) — a puck with no
     * battery-sense ADC still boots; ff_power_batt_mv() simply reports 0
     * (unknown) forever, and the status bar honestly shows "--%". */
    esp_err_t const batt_init_err = ff_power_batt_init();
    ESP_LOGI(TAG, "S25c battery ADC init: %s", (batt_init_err == ESP_OK) ? "ok" : esp_err_to_name(batt_init_err));

    /* S26 slice b — zero the PWR-button FSM before anything can tick it
     * (the main loop below is the only tick site). */
    ff_power_fsm_init(&s_power_fsm);

    /* S26 slice e — zero the BOOT-button debouncer, same "before anything
     * can tick it" placement. */
    ff_button_init(&s_boot_button);
    /* S26 wake-only-touch amendment — zero BOOT's own gate latch, same
     * placement. */
    ff_idle_touch_gate_init(&s_boot_gate);

    /* fix/quick-flare-detection (2026-09-03) — arm the BOOT edge ISR
     * that feeds the multitap counter with real press-edge timestamps
     * (see ff_power.h's own doc comment for the full "why"). Placed
     * right next to the debouncer/gate above — both exist for the SAME
     * physical button, initialized together — rather than deferred to
     * the render loop, so the ISR is live before the first possible
     * BOOT press. Non-fatal on failure (logged inside
     * ff_power_boot_isr_init): quick-flare timing degrades to the
     * debounced-tick path alone (this codebase's pre-PR behavior),
     * never a boot failure. */
    (void)ff_power_boot_isr_init();

    /* S26 slice c — zero the idle FSM; re-pinned to "now" right before
     * the render loop starts (below), after every one-shot bring-up step
     * (including a possibly long, human-paced STAGE 4 calibration) has
     * had its say, so the very first DIM/OFF countdown starts at the
     * actual beginning of interactive use, not at cold boot. */
    ff_idle_init(&s_idle);
    /* S26 wake-only-touch amendment — wire the shared idle FSM into the
     * display HAL's touch read path (ff_display_touch_set_idle's own doc
     * comment has the full contract) BEFORE ff_display_touch_start below
     * ever brings the touch indev up, so the gate is live from the very
     * first poll. */
    ff_display_touch_set_idle(&s_idle);

    s_shell_p = heap_caps_calloc(1, sizeof(ff_shell_t), MALLOC_CAP_SPIRAM);
    if (s_shell_p == NULL) { ESP_LOGE(TAG, "shell PSRAM alloc failed"); return; }
    const int stage = CONFIG_FF_BRINGUP_STAGE;
    ESP_LOGI(TAG, "firefly esp32s3 target booting (S15 slice b: display+touch, STAGE %d)", stage);

#if CONFIG_FF_DEMO_MODE
    s_clock.now_ms = ff_demo_clock_now_ms; /* frozen demo clock (Sat 21:30) */
#else
    s_clock.now_ms = ff_esp_clock_now_ms;
#endif
    s_clock.user = NULL;

    /* S21 §4 — real NVS store, replacing the no-op stub. ff_shell_init loads
     * settings from it below (persisted values on a returning puck, exact
     * defaults on a fresh/empty partition), and saves on every change; on an
     * NVS failure the store degrades to no-op and the puck runs on defaults
     * (ff_nvs_store_init logs which). */
    s_store = ff_nvs_store_init(&s_nvs);

    ff_shell_cfg_t cfg;
    memset(&cfg, 0, sizeof(cfg));
    cfg.clock = &s_clock;
    cfg.store = &s_store;
    /* fix/meshclient-packet-id-seed — a fresh random start for this
     * boot's outgoing Meshtastic packet ids (ff_shell_cfg_t.
     * packet_id_seed doc comment / mc_seed_packet_ids()'s doc comment
     * have the full story: without this, every reboot's mc_init()
     * restarted the counter at 1, and the mesh router silently dropped a
     * repeat-id packet as "already seen recently"). Only esp_random()'s
     * 32 bits go in — the node's own id (my_node_id) isn't known yet at
     * this point in boot, it only arrives later via on_my_info, well
     * after the first send may need to happen. That's fine: a uniformly
     * random 32-bit start makes a collision with any prior boot's ids
     * negligible against the router's ~10-minute (from, id) history
     * window, without needing the node id at all. */
    cfg.packet_id_seed = esp_random();
    /* S21 §3 — the touch-calibration hook the Settings CALIBRATE TOUCH row
     * drives through FF_INTENT_CALIBRATE_TOUCH. */
    cfg.calibrate_touch = ff_calibrate_touch_cb;
    cfg.calibrate_touch_user = NULL;
#if CONFIG_FF_COMPASS
    /* S12 step 3 — the compass calibration ritual's live-update hook
     * (see ff_compass_cal_changed_cb above). Set here, before
     * ff_shell_init, same "live the moment the shell exists" timing
     * every other injected hook in this block uses; the compass driver
     * itself isn't brought up until AFTER ff_shell_init (below, at
     * panel bring-up) — that's fine, `ff_compass_set_cal` is documented
     * safe to call at any time, including before `ff_compass_init`. */
    cfg.compass_cal_changed = ff_compass_cal_changed_cb;
    cfg.compass_cal_changed_user = NULL;
#endif
    /* S26 slice b — the power-menu action hooks (FF_INTENT_POWER_OFF /
     * FF_INTENT_POWER_REBOOT). See ff_power_off_cb/ff_power_reboot_cb
     * above. */
    cfg.power_off = ff_power_off_cb;
    cfg.power_off_user = NULL;
    cfg.power_reboot = ff_power_reboot_cb;
    cfg.power_reboot_user = NULL;
    /* S25 latch-hold amendment — "diag clear" device hook. */
    cfg.diag_clear_crash = ff_diag_clear_crash_cb;
    cfg.diag_clear_crash_user = NULL;
    /* S27 sounds (device half) — set BEFORE ff_shell_init so the hook is
     * live the moment the shell exists. This USED to say the actual I2S
     * HAL bring-up (ff_audio_init) ran later, after display bring-up —
     * that was the bug this fix closes (docs/specs/S27-sounds.md
     * Amendments, "boot order"): a play_sound call landing before
     * ff_audio_init had run was a silent no-op (`ff_audio_play`'s own
     * guard), and the S20 demo seed's seeded RALLY fires from right
     * inside `ff_shell_init`'s caller (a few lines below, in the
     * CONFIG_FF_DEMO_MODE block) — on real glass this produced exactly
     * "ff_audio_play(3) called but ff_audio_init never succeeded —
     * no-op" followed a full 1.6s later by "I2S0 TX up", i.e. any real
     * early event was lost too, not just the seeded one. `ff_audio_init`
     * is now brought up immediately below, BEFORE `ff_shell_init`, so
     * the HAL is live (or has already failed and logged so) before the
     * shell can generate its first sound-eligible event. */
    cfg.play_sound = app_play_sound;
    cfg.play_sound_user = NULL;
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

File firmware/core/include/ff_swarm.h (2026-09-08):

/**
 * ff_swarm.h — S31 Music/Swarm: pure, host-testable, DETERMINISTIC
 * 60-firefly particle simulation for the Music face's "Swarm" concept
 * (docs/specs/S31-music-swarm.md). Zero I/O, zero LVGL — the
 * `firmware/core/` placement rule applied to "where is each firefly and
 * how bright is it", exactly the split `ff_radar_layout`/`radar_layout.c`
 * already draw between core geometry and `scr_radar.c`'s LVGL drawing.
 *
 * ## S31 polish (owner feedback on PR #245, 2026-09-08)
 * Jake, on the field puck: "swarm works, clap flares it and quiet calms
 * it. Would love for it to be more dynamic like the design originally."
 * This motion model replaces PR #245's "wander around a fixed home
 * position" particle with the coordinator's ORIGINAL concept-mockup
 * behaviour: every firefly continuously drifts on its own fixed angular
 * (rad/s) and radial (px/s) velocity — never settling, never static even
 * in total silence — bouncing off the swarm's inner/outer radius bounds
 * forever. A beat no longer "leans" a home position inward; instead it
 * LERPS the rendered radius toward a shared pull target
 * (`FF_SWARM_PULL_TARGET_R_PX`) by a strength that is proportional to
 * the shared beat envelope (see below) and the current loudness, so a
 * strong beat visibly snaps the whole swarm inward and then the pull
 * relaxes back out over the following beat interval as the envelope
 * decays — "then wander off again", now literally riding the same
 * continuous drift trajectory the firefly was already on, not a
 * separate "home" it returns to. Per-firefly TWINKLE (a slow, phase-
 * offset brightness oscillation) is new — it is what keeps a firefly
 * visibly alive even when the shared envelope is fully decayed to
 * near-zero between beats.
 *
 * ## Ownership — NOT part of ff_app_state_t
 * Unlike every other per-face view struct in `ff_app_state.h`, an
 * `ff_swarm_t` instance is NOT projected into the shell's render key:
 * it changes every frame (drift, beat pulls, twinkle) and the render
 * key drives a full `lv_obj_clean` + rebuild on every dirty tick (S16's
 * own rule) — putting 60 particles' continuous motion in there would
 * either force a full-screen rebuild every frame (an S16 churn-budget
 * violation and, per the Map face's own measured cost, a real stall
 * risk) or need the same field-by-field masking every other "must not
 * churn" field gets, at 60x the surface area. Instead `scr_music.c`
 * owns one `ff_swarm_t` instance itself (a file-static, the same
 * "screen owns its own pool" convention `scr_map.c`'s draw-op pool
 * already establishes) and steps/reads it from its own per-frame LVGL
 * timer — see that file's top comment for the full mechanism.
 *
 * ## Determinism
 * `ff_swarm_init(seed)` seeds a small xorshift32 PRNG and derives every
 * particle's fixed "personality" (initial radius/angle, angular/radial
 * drift velocity, twinkle phase, accent color) from it ONCE — nothing
 * here calls a platform RNG or reads wall-clock time. `ff_swarm_step`
 * is a pure function of (current state, loudness, beat_now, dt_s): the
 * SAME seed fed the SAME sequence of (loudness, beat_now, dt_s) calls
 * always produces the SAME particle positions, which is what makes the
 * Music golden fixtures (`music_swarm_*.json`) reproducible
 * pixel-for-pixel.
 *
 * ## Scale: the coordinator's mockup canvas was 600px, the puck is 412px
 * Every absolute-pixel constant below (`FF_SWARM_R_MIN_PX`, `..._MAX_PX`,
 * `..._PULL_TARGET_R_PX`, `..._RADIAL_DRIFT_MAX_PX_S`) is the
 * coordinator's own concept-mockup number — a canvas animation authored
 * at 600px — scaled by `FF_SWARM_MOCK_TO_PUCK_SCALE` (412/600) onto this
 * puck's actual 412px glass (`FF_THEME_PUCK_PX`). 268px (the mockup's
 * own outer radius) would run almost 30px past the visible glass edge
 * (`FF_THEME_GLASS_R` == 200) if used unscaled; the scaled value (~184px)
 * lands comfortably inside it. Angular quantities (drift rad/s, the
 * twinkle formula) need no such scaling — an angle means the same thing
 * on any canvas size.
 */
#ifndef FF_SWARM_H
#define FF_SWARM_H

#include <stdbool.h>
#include <stdint.h>

#ifdef __cplusplus
extern "C" {
#endif

#define FF_SWARM_PARTICLE_COUNT 60u

/** Default seed used whenever nothing more specific is asked for (the
 *  live shell's own default, and every fixture/golden that doesn't
 *  override it via `music.seed` — see tests/fixtures/README.md). Not
 *  0: xorshift32 is fixed at exactly 0 forever if seeded with 0, so 0
 *  is remapped to this value by `ff_swarm_init` regardless of caller —
 *  see that function's own doc comment. */
#define FF_SWARM_DEFAULT_SEED 0x51E9FF17u

/** The coordinator's concept mockup was authored on a 600px canvas;
 *  this puck's glass is 412px (`FF_THEME_PUCK_PX`) — see this header's
 *  own "Scale" comment above. Applied to every absolute-pixel constant
 *  below. */
#define FF_SWARM_MOCK_TO_PUCK_SCALE (412.0f / 600.0f)

/** Firefly radius bounds, px from centre, on the puck's own 412px
 *  canvas — the mockup's own 60-268px range, scaled. Each firefly
 *  drifts continuously and REFLECTS off these bounds (never clamps to
 *  a hard stop, never a fixed "home") so the swarm is never static,
 *  even in total silence. */
#define FF_SWARM_R_MIN_PX (60.0f  * FF_SWARM_MOCK_TO_PUCK_SCALE)  /* ~41.2px */
#define FF_SWARM_R_MAX_PX (268.0f * FF_SWARM_MOCK_TO_PUCK_SCALE)  /* ~184.1px */

/** Beat-driven pull target radius (px) — every firefly's rendered
 *  radius is lerped toward this on a beat, by a strength proportional
 *  to the shared envelope and loudness (see `ff_swarm_step`'s own doc
 *  comment) — "pulled toward radius ~120px... then drift back out". */
#define FF_SWARM_PULL_TARGET_R_PX (120.0f * FF_SWARM_MOCK_TO_PUCK_SCALE) /* ~82.4px */

/** `strength = envelope * (FF_SWARM_PULL_LOUDNESS_BASE + loudness)`,
 *  clamped to [0,1] — a beat pulls inward even at loudness 0 (the base
 *  term), more so the louder it is. Interpretation call, flagged per
 *  AGENTS.md — the task's own wording ("strength proportional to
 *  envelope*(0.6+loudness)") pins the shape, not a separate spec. */
#define FF_SWARM_PULL_LOUDNESS_BASE 0.6f

/** Each firefly's fixed (per-init) angular/radial drift velocity is
 *  drawn uniformly from [-MAX, +MAX] on these two ranges — "each with
 *  its own angular drift (+/-0.2 rad/s) and radial drift (+/-12 px/s),
 *  continuously wandering". Angular needs no mock-scale conversion (an
 *  angle means the same thing on any canvas size); radial does. */
#define FF_SWARM_ANGULAR_DRIFT_MAX_RAD_S 0.2f
#define FF_SWARM_RADIAL_DRIFT_MAX_PX_S (12.0f * FF_SWARM_MOCK_TO_PUCK_SCALE) /* ~8.24px/s */

/** Shared beat-envelope decay rate — `envelope = exp(-phase*RATE)`
 *  where `phase` is how far (as a fraction of the beat interval) the
 *  sim has advanced since the last beat, clamped to [0,1]. The task's
 *  own stated number. */
#define FF_SWARM_ENVELOPE_DECAY_RATE 5.5f
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

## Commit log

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2026-08-23 [api] S13/S14: fixtures, headless per-state rendering, golden tooling (#12)
    * [api] S13/S14: fixtures, headless per-state rendering, golden tooling
    S13 slice b + S14 slice b — the dev-loop infra Wave 3's screens (S06/S08/
    S10) will build on.
    - firmware/app/include/ff_app_state.h: ff_app_state_t, the plain
    view-state struct screens will render (ARCHITECTURE.md principle 3:
    "the UI is a projection"). Sub-structs for radar/now/signals/flare/
    settings, transcribed from the S06/S07/S08/S10/S11 spec interfaces and
    flattened where those specs use live pointers (fp_set_t*, node ids)
    that don't survive a standalone JSON fixture. See the header's comment
    for why the radar sub-struct is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
    [main.c]
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2026-08-23 [api] S06a: radar compute + ff_radar_view_t unification (#13)
    * [api] S06a: radar compute + ff_radar_view_t unification
    core/include/ff_radar.h + core/src/ff_radar.c: ff_radar_compute per
    docs/specs/S06-radar-face.md —
    - Mode resolution (NOSEL/NOFIX/CLOSE/LIVE/STALE/LOST), priority order
    NOSEL > NOFIX > CLOSE > freshness. FF_FRESH_NEVER (paired member that
    has never sent a fix) folds into RADAR_LOST (no dedicated mode exists
    for it; documented interpretation, see ff_radar.h's doc comment).
    - Arrow = ff_geo_arrow_deg(bearing, heading) with wrap-aware
    (ff_geo_angdiff_deg) exponential smoothing, 250ms time constant.
    Smoothing state lives in a caller-owned ff_radar_smooth_t (added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
    [ff_radar.h]
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2026-08-24 [api] S16b2: cut the sim over to ff_shell, retire live.{c,h}
    Retires targets/sim/live.{c,h} and test_live: `ffsim --connect` now
    drives an ff_shell_t over the mc TCP transport, and the ctl socket's
    `state` dump reads ff_shell_view() plus a "wall" object from
    ff_shell_wall() (bench work needs to SEE what latched — #49 context).
    Closes live.h's self-documented spec-gap deviation via a new S13
    Amendments section.
    --dev-trust-all (S16 AC6): sim-only, logged at startup, COMPILED OUT of
    device builds (#if FF_TARGET_SIM guards the field, branch, and API; an
    #error in main.c pins the define discipline). Auto-pairs on NodeInfo
    only — a bare Position still never grows the roster. Recorded as an S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
    [main.c]
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2026-08-24 [api] S16 slice c2: wire core-mutating stubs through the intent seam (#58)
    Wires the four remaining stub sites through ff_shell_intent (S16 slice
    c2, spec's Intents section, AC7):
    - compose SEND -> FF_INTENT_SEND_TEXT (shell dispatch stays a no-op
    until c3 moves the T9 draft in; the emit site is wired now so the
    seam is the only thing c3 has left to touch)
    - Signals rally-row tap -> FF_INTENT_SELECT_RALLY, carrying the row's
    own index (shell dispatch stays a no-op: ff_crew_select_rally() does
    not exist in core yet, per ff_crew.h's own documented deviation)
    - Signals OMW/5 MIN/PULSE chips -> FF_INTENT_CANNED_REPLY; ff_shell_intent
    resolves the reply-context as the newest feed item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
    [main.c]
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2026-08-25 [api] core: position-honesty round — asserted positions and degraded precision (#33, #47) (#69)
    Issue #33: a landmark's asserted (LOC_MANUAL) position re-broadcasts on
    the ordinary interval forever, so freshness alone could never age it
    into STALE/LOST. ff_crew_freshness gains FF_FRESH_ASSERTED, checked
    before any age math so no elapsed time can move a member off it.
    ff_radar_compute maps this to its own mode, RADAR_PLACE — never folded
    into LIVE/STALE/LOST — rendered as a place (solid arrow, neutral "FIXED
    POSITION" chip, no rim tint) with age_str always empty, per the binding
    ruling that LOC_MANUAL means "not measured," not "placed deliberately
    or recently."
    Issue #47: mc_position_t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
    [ff_radar.h]
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2026-08-25 [api] S17a: crew visual distinction — 8-colour palette, colorblind toggle, radar-imprecise dot (#83)
    * [api] S17 slice a: crew visual distinction (closes #43, closes #74)
    Extends the crew palette from 4 to 8 real entries (indices 0-3 byte-
    identical to today's hexes — no <=4-crew golden moves), adds a
    colorblind toggle (`ff_settings_t.colorblind`, `FF_SETTING_COLORBLIND`)
    that switches `ff_theme_crew_color` to an Okabe-Ito-derived 8-colour
    safe palette, and gives Radar's crew ring dots the Map face's fuzzy-ring
    treatment for degraded-precision fixes (issue #74).
    Core:
    - ff_settings_t gains `colorblind` (bool, default false); format version
    bumped 3->4, no migration (same policy as th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
    [ff_radar.h]
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2026-08-26 [api] S18 slice c: pack-derived plausibility window (#40) (#93)
    * [api] S18 slice c: pack-derived plausibility window (#40)
    Tighten the wall-clock plausibility window to the loaded festpack's dates,
    keeping the fixed 2026-2030 window only for the pre-pack bootstrap it
    exists for, and add a build-date proximity backstop for the fixed
    window's silent decay.
    Core (ff_wall):
    - ff_wall_state_t gains an effective window [win_floor, win_ceiling),
    defaulted by ff_wall_init to the fixed [FF_WALL_EPOCH_FLOOR,
    FF_WALL_EPOCH_CEILING) bootstrap bounds. ff_wall_observe now gates on it;
    ff_wall_split_local deliberately stays on the fixed absolute window (it
    is stateless, a redundant sanity net ov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
    [main.c]
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2026-08-27 S15b/c: ESP32-S3 display + touch driver, UI fitted to 412 (#98)
    Device display + touch on the Waveshare ESP32-S3-Touch-LCD-1.46, hardware-verified on board 2.
    - SPD2010 QSPI display via LVGL v9 (banded/strip flush to dodge full-frame ESP_ERR_NO_MEM); TCA9554 IO-expander resets; STAGE bring-up selector.
    - SPD2010 I2C touch via a vendored esp_lcd_touch_spd2010 (4 patches for ESP-IDF 5.3.5 new i2c_master: init read + no-touch-tolerant polling); presses, swipe gestures, long-press all work.
    - S15c: UI refit from 440-puck/456-window to the real 412 panel — relayouts (settings/compose/flare), status-bar un-clip, all 46 goldens regenerated, Settings controls enlarged.
    Independently reviewed (AP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
    [app_main.c, esp_lcd_touch_spd2010.c, ff_display.c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]
2026-08-27 S15: touch calibration (crosshair capture + per-axis affine) (#103)
    Pure-core ff_touchcal (per-axis affine, unit-tested) + a STAGE-4 crosshair capture flow that solves + applies the correction live. Hardware-verified on board 2: measured transform sx=0.885x+15.5 / sy=0.902y+8.2, buttons hit better. Persistence is session-live (stub store); NVS + a Settings "Calibrate Touch" entry follow in the settings rework.
    [app_main.c, ff_display.c]
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2026-08-27 [api] Settings rework — scrolling list, Calibrate Touch, NVS persistence, field-bug fixes (#107)
    * spec: S21 settings rework — scrolling list, Calibrate Touch, NVS persistence
    Replace #105's paginated Settings with a scrolling list; add a "Calibrate
    Touch" entry that runs the crosshair flow from Settings; make the tap-target
    sweep scroll-aware; wire a real NVS-backed ff_store so calibration + all
    settings persist across reboot; set a representative measured default touch cal.
    * S21 §5: default touch cal to the board-2 Waveshare-1.46 panel prior
    Set the ff_settings default touch calibration to the per-axis affine
    measured on boar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
    [app_main.c]
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2026-08-28 Demo mode — Firefly Fields (seeded festival + crew) (#106)
    * spec: S20 demo mode — Firefly Fields (seeded festival + crew)
    A fictional festival (Firefly Fields 2026) + seeded crew/positions/feed so
    every face shows real data with no mesh: live/close-range/stale/no-fix crew on
    Radar, a lineup on Now, dots on Map, chatter on Signals. Demo data flows
    through real core APIs (honest, labeled DEMO). Sim --demo + device
    CONFIG_FF_DEMO_MODE.
    * S20 festpack: Firefly Fields demo pack (fictional festival)
    Author firmware/assets/demo/firefly-fields.festpack.json to the festpack
    v0.1 schema: a fictional three-night bioluminescent night-forest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
    [app_main.c, main.c]
2026-08-28 fix(demo): resolve internal-RAM exhaustion crashing the demo build on device (#109)
    * fix(demo): resolve internal-RAM exhaustion that crashed the demo build on device
    The merged S20 demo build (CONFIG_FF_DEMO_MODE + STAGE 3) crashed on hardware —
    first a main-task stack overflow, then, once given more stack, an LVGL DMA
    buffer OOM. Two independent internal-RAM pressures, both invisible to the sim
    (desktop stacks are megabytes; no DMA-internal constraint) and to CI:
    1. ff_shell_tick spilled a full ff_app_state_t (~7 KB) onto the stack every tick
    for render-key dirty-detection. On the 8 KB ESP32-S3 main-task stack the
    demo's populated projection tipped it into a stack overflow. Moved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
    [app_main.c, ff_display.c]
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2026-08-28 feat(demo): S23(d) demo content sourcing + presence/status jitter (#119)
    Polish slice for S23. Resolves the two #117-review nits and AC5 honestly,
    and documents the jitter delivered vs. deferred.
    - AC5 festival content: a live RALLY's place name AND lat/lon are now
    sourced from the loaded demo festpack (ff_demo_rally_point reads the
    venue origin + the "firefly-tower" landmark name) instead of the
    hardcoded FF_DEMO_LIVE_RALLY_LAT/LON literals (nit #2 — kills the
    drift the review flagged). No pack / unknown origin => no rally sent,
    never a fabricated place.
    - AC5 chatter: the conversational demo string table stays demo-gated C
    (synthetic crew filler, not festival data). Not forc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
    [app_main.c]
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2026-09-01 fix(signals): on-glass interaction pass — rebuild-mid-tap, full-row/FAB press, "now" ages, 1:1 color (#127)
    * fix(signals): "now" sub-minute ages, kill per-second render churn, 1:1 member color
    Three coupled logic fixes behind the on-glass interaction report:
    - ff_fmt_age: ages under a minute render "now" (honest "less than a
    minute ago") instead of a per-second counter. Shared (radar/etc.) —
    "now" is honest everywhere. Boundary unit-tested (59s -> "now",
    60s -> "1 MIN").
    - shell_coarsen_age_ms: the whole <60s span collapses to ONE render-key
    bucket, matching ff_fmt_age. A sub-minute age ticking second-by-second
    now changes NO render key, so the inbox/thread no longer rebuil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
    [app_main.c, ff_display.c]
2026-09-01 feat(signals): S24(d) action popup + rally + send routing (+ demo loopback, FAB press, thread polish) (#128)
    Ships the final S24 Signals slice (spec: docs/specs/S24-signals-inbox.md,
    AC5/AC6) plus the on-glass fixes that make the thread's send half usable.
    Task 1 — action popup + Rally + send routing (AC5/AC6):
    - FF_SIG_SUB_POPUP: the thread FAB and a picker pick open the action popup
    scoped to the thread. Rows: Compose -> composer at scope; Pulse ->
    immediate pulse to scope then close; Rally -> the Rally sub-view. >=44px
    close pops back one level. Popup + Rally are OPAQUE in the render key.
    - FF_SIG_SUB_RALLY: WHERE radio list (On Me pinned, DISABLED with an honest
    reason when my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
    [app_main.c]
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2026-09-01 fix(device): on-glass polish — SPD2010 partial-redraw align, LVGL stack, PSRAM shell, composer press+keys (#131)
    Four device bring-up fixes validated on physical hardware (Lost Lands puck,
    demo-LIVE), never previously PR'd — they lived only on a local build branch.
    - **SPD2010 4-px invalidate alignment** (ff_display.c): the panel addresses
    GRAM in 4-px-aligned windows on both axes. Full-width strip flushes always
    land aligned; a PARTIAL redraw at an arbitrary rect (a single key lighting
    on press) did not, so the panel flushed a misaligned window and ghosted a
    mirrored slice off the right edge. Snap every invalidated area out to the
    4-px grid via an LV_EVENT_INVALIDATE_AREA cal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
    [app_main.c, ff_display.c]
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2026-09-01 feat(festpack)[api]: S26(a) caller-supplied token scratch — reclaim 128KB internal RAM (#134)
    * feat(festpack)[api]: S26(a) caller-supplied token scratch — reclaim 128KB internal RAM
    fp_parse() no longer owns a static jsmntok_t[8192] arena (131,072 B
    living forever in fp_pack.c's .bss). The caller now supplies the jsmn
    token scratch:
    fp_result_t fp_parse(char const *json, size_t len, fp_pack_t *out,
    jsmntok_t *toks, int ntoks);
    fp_pack.h exposes jsmntok_t (JSMN_HEADER — declarations only, no
    compiled tokenizer per TU) and a public FP_MAX_TOKENS=8192 constant for
    callers that want the old capacity. A too-small/NULL toks buffer maps
    to the existing FP_ERR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
    [app_main.c, main.c]
2026-09-01 feat(power): S26(b) PWR button FSM + power menu + soft power-off [api] (#135)
    * feat(power): S26(b) PWR button FSM + power menu + soft power-off [api]
    Implements docs/specs/S26-device-lifecycle.md "(b) Power button -> power
    menu -> soft power-off" (= S25 slice b).
    Core (firmware/core/include/ff_power_fsm.h + src/):
    - New `ff_power_fsm_t`: debounced (30ms, symmetric) PWR-key press FSM.
    `ff_power_fsm_tick(fsm, now_ms, pwr_pressed)` emits at most one of
    SHORT_PRESS / LONG_PRESS (>=1500ms, well under the panel's ~6s hardware
    force-off) / RELEASE per call. LONG_PRESS fires exactly once per press
    cycle, while still held; a release after LONG emits RELEASE, never also
    SHORT_PRESS (relea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
    [app_main.c, ff_power.c]
2026-09-01 feat(idle): S26(c) inactivity → dim → screen off (ff_idle) [api] (#136)
    * feat(idle): S26(c) inactivity → dim → screen off (ff_idle) [api]
    Core ff_idle (firmware/core/include/ff_idle.h + src/ff_idle.c): a pure
    C11 ACTIVE/DIM/OFF FSM. FF_IDLE_T_DIM_MS=15000, FF_IDLE_T_OFF_MS=30000,
    both measured from the same reference instant (a single large now_ms
    jump lands directly in OFF, no need to visit DIM first). ff_idle_tick
    advances against elapsed idle time; ff_idle_input resets to ACTIVE from
    ANY state; ff_idle_force_off jumps straight to OFF regardless of
    elapsed time (PWR SHORT_PRESS while ACTIVE) and is sticky under natural
    ticking until the next input. While keep_awake holds, tick fo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
    [app_main.c, ff_display.c, ff_idle.h]
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2026-09-02 feat(boot): S26(g) boot splash (#139)
    S26 slice (g) — a splash covering the reset pulses + LVGL init latency
    that otherwise leave the glass black for a few hundred ms.
    Draw path: raw esp_lcd_panel_draw_bitmap, NO LVGL — the same
    band-buffer/byte-swap shape ff_display_draw_test_pattern (STAGE 1)
    already uses, chosen over an LVGL-screen splash specifically to BEAT
    LVGL's own init latency rather than merely occupy it. Runs right after
    ff_bringup_panel() succeeds (panel + backlight up) and before
    ff_display_lvgl_start(), for every stage/build (field and demo
    identical — no CONFIG_FF_DEMO_MODE gate; STAGE 1's own diagnostic test
    pattern below it is a manual bring-up aid, not the normal boo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
    [app_main.c, ff_display.c]
2026-09-02 fix(boot): S26(g) hold the splash mark at full amber (~1.1 s, was a ~0.35 s blink) (#141)
    On glass the first cut read as a blink: the breathe peaked at full amber for
    a single 35 ms step with no dwell. Add a hold at the t == 255 step
    (FF_SPLASH_HOLD_MS = 600) behind two named constants (step + hold) so the
    timing is tuned by constant, not by editing the ramp. Total ≈ 1.1 s; the
    spec's budget is raised from ≤ 1 s to ~1 s to match (maintainer feedback,
    2026-09-01). Latch order untouched (splash still runs after
    ff_power_latch_on and the panel bring-up); DIRAM unchanged (no new statics).
    Device-only (ff_display.c); no sim/golden impact. Flashed for the
    maintainer's on-glass feel check.
    Co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
    [ff_display.c]
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2026-09-02 feat(settings)[api]: 12h/24h clock format (12h default) + centered Settings header (#147)
    Ask 1 — 12-hour clock by default, 24-hour via Settings toggle:
    - New `ff_settings_t.clock_24h` (bool, default false = 12-hour), format
    version bumped 6 -> 7. v7 FORWARD-MIGRATES a v6 blob (v6 is the layout
    the real NVS store, S21 §4, ships with today, so fielded pucks hold a
    genuine v6 blob — the pre-v1 "no fielded devices" premise every earlier
    bump relied on no longer holds): `ff_settings_load` reads a v6 blob
    through a frozen `ff_settings_v6_t` shadow and carries every field
    across explicitly, filling `clock_24h` in at its honest default.
    Anything OLDER than v6 (<=v5, pre-dating th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
    [ff_radar.h]
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2026-09-02 feat(display): glass-ruler boot pattern to measure bezel/pixel offset (CONFIG_FF_GLASS_RULER) (#151)
    Device-only diagnostic to measure the bezel/pixel-array offset on the
    Waveshare ESP32-S3-Touch-LCD-1.46 by eye, before correcting anything.
    New CONFIG_FF_GLASS_RULER (bool, default n): when set, app_main draws
    the pattern right after ff_bringup_panel() (same spot the boot splash
    claims, "after the latch") then HOLDS it on glass forever (1s heartbeat
    log), never continuing to the splash/LVGL/normal boot. Off by default:
    zero behaviour change, and ff_display_draw_glass_ruler is compiled out
    entirely (#if CONFIG_FF_GLASS_RULER) so field/demo builds are
    byte-identical either way.
    The pattern (f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
    [app_main.c, ff_display.c]
2026-09-02 fix(display): centre the image on the glass — panel gap (5, 1) measured with the ruler (#152)
    The 412-wide image sat ~5 px left of the round glass window (the SPD2010's
    addressable area is wider than 412 and the bezel is centred on it), so the
    Radar rim tint hugged the left bezel and left a gap on the right. Measured on
    glass with the CONFIG_FF_GLASS_RULER pattern over three flashes: (5, 1)
    puts all four corner squares in view with balanced rulers. Applied via the
    existing esp_lcd_panel_set_gap knob; the measurement log is in
    docs/hardware/glass-offset.md. Touch calibration must be re-run once after
    this lands (pixels moved under the sensor).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
    [ff_display.c]
2026-09-02 fix(display): snap the panel gap to (4, 0) — SPD2010 flush windows must stay 4-px aligned (#153)
    Follow-up to #152, whose auto-merge landed before the amendment. (5, 1)
    read best by eye but painted stray white lines at the top and right edges:
    the SPD2010 only accepts 4-px-aligned windows in panel coordinates (the
    ghosting #131 fixed by aligning invalidated areas), and a gap that is not a
    multiple of 4 misaligns every flush. (4, 0) is within the eye's resolution
    of the measurement and keeps every window aligned; the constraint is now a
    static assert and recorded in the doc. Flashed and on glass.
    [ff_display.c]
2026-09-02 fix(display)[api]: centre edge-hugging elements on the measured glass, panel gap back to (0,0) (#154)
    The bezel window on this board sits ~5 px right of the 412-wide pixel array
    (measured with the CONFIG_FF_GLASS_RULER pattern, docs/hardware/glass-offset.md).
    Shifting the panel window is not viable: the pixel array is exactly 412
    columns, so any positive gap pushes the image's last columns off the array
    and the SPD2010 paints them white (#152/#153 tried (5,1) and (4,0); both
    painted the right edge). Panel gap is back to (0,0), kept under the
    multiple-of-4 static assert.
    The offset is now a theme fact: FF_THEME_GLASS_CX/CY/R = 208/206/203, the
    visible glass's centre and radius. Radar's rim t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
    [ff_display.c]
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2026-09-02 feat(settings)[api]: SCREEN flip 180° (hardware mirror + touch flip + mirrored glass centre) (#158)
    * feat(settings)[api]: SCREEN flip 180 (hardware mirror + touch flip + mirrored glass centre)
    - ff_settings_t.screen_flip, format v7->v8 forward migration chained through v7
    - SCREEN NORMAL|FLIPPED settings row after CLOCK
    - ff_display_set_flip: hardware panel mirror via esp_lcd_panel_mirror (MADCTL)
    - ff_touchcal_flip180 pure helper, composed after calibration in process_coordinates
    - ff_theme_glass_cx/_cy: mirrored glass centre, consumed by radar rim tint
    - docs: S21/S15b/S15d/S26 amendments, glass-offset.md flipped-case rule
    * fix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
    [app_main.c, ff_display.c]
2026-09-02 feat(proto)[api]: retire PULSE end to end — 0x01 reserved, demo never emits it, no rendering (#159)
    PR #129 retired only the OUTBOUND pulse (send popup/chip became Flare).
    This retires PULSE completely: the wire type, the feed kind, the demo
    generator, the inbox rendering, and the dead outbound-pulse programmatic
    seam #129 deliberately kept for tests.
    Retirement table
    - Protocol: FF_PROTO_TYPE_PULSE (0x01) renamed FF_PROTO_TYPE_RESERVED_01,
    permanently reserved (never reused — an old puck may still transmit it).
    ff_proto_encode_pulse removed. ff_proto_decode still recognizes 0x01's
    empty-body shape and returns a normal SUCCESSFUL decode (not 0/failure)
    — a well-formed frame fr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
    [app_main.c]
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2026-09-03 fix(idle)[api]: a touch or button press while dimmed/off is wake-only, never delivered (#163)
    Maintainer-reported on-glass bug: "When the screen is dimmed, a tap
    should just wake up, but right now it also taps whatever is behind,
    which can be unintentional." Same fix applies for screen OFF and after
    light SLEEP.
    Core: add ff_idle_touch_gate(ff_idle_t*, ff_idle_touch_gate_t*, uint32_t
    now_ms, bool pressed) to ff_idle.h/.c [api]. A press that BEGINS while
    the current state is not ACTIVE wakes the FSM (fires ff_idle_input) and
    swallows every sample of that gesture until release; a press that
    begins while ACTIVE is delivered normally; state is latched only at
    press-begin, so a gesture that star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
    [app_main.c, ff_display.c, ff_idle.h]
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2026-09-03 fix(display): screen flip survives LVGL start — seed the port's mirror from s_screen_flip (#164)
    On a boot with screen_flip=true persisted, app_main applied the panel
    mirror (ff_display_set_flip) BEFORE ff_display_lvgl_start(), and
    esp_lvgl_port's add_disp-time rotation update then re-issued
    esp_lcd_panel_mirror(panel, false, false) from the hard-coded cfg —
    silently un-mirroring the panel while s_screen_flip (and therefore the
    touch rotation) stayed true. Symptom on glass: display upright, touches
    landing at the 180-degree-rotated position. The runtime toggle path
    never hit it because LVGL was already up, so it only appeared after a
    re-flash/reboot with the flip persisted.
    Seed the por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
    [ff_display.c]
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2026-09-03 fix(sim): window mode runs the device lifecycle — idle FSM, touch gate, rebuild-under-finger latch (#174)
    Extracts the per-tick lifecycle pump ctl_loop.c already had (S26 slice c)
    into a shared helper, sim_lifecycle.{c,h}: ff_sim_lifecycle_pump(idle,
    rebuild_pending, rebuild_count, now_ms, dirty, shell_wake, finger_down,
    keep_awake, sleep_inhibit, state). Three callers now run it —
    ctl_loop.c's ff_ctl_loop_pump, main.c's live ff_run_window loop, and
    ff_demo_run.c's ff_run_demo_window loop — closing the gap where window
    mode and --demo rebuilt the LVGL tree unconditionally on any dirty tick,
    with no ff_idle_init/ff_idle_tick/ff_idle_touch_gate/ff_shell_keep_awake/
    ff_shell_take_wake any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
    [main.c]
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2026-09-03 fix(core)[api]: battery-low is decided once in core; launcher and radar agree; shared brightness limits (#177)
    * fix(core)[api]: battery-low is decided once in core; launcher and radar agree; shared brightness limits
    Two duplicated-decision debt items:
    1. Battery-low. scr_radar.c computed `batt_low = (batt_pct >= 0 &&
    batt_pct <= FF_THEME_BATT_LOW_PCT)` inline and applied the amber
    alert color; scr_launcher.c's status row rendered the SAME batt_pct
    field with its own unnamed 87/62/37/12 glyph ladder and never
    applied any low-battery treatment at all — the launcher IS home
    (S26 slice e) and never read amber even at 1%.
    Moved the decision into core: `FF_BATT_LOW_PCT` (15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
    [ff_radar.h]
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
